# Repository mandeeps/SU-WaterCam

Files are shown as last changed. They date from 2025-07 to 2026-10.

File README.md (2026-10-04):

Prerequisite Knowledge:
Basic Linux, electronics, general computer troubleshooting

Helpful Resources:
Soldering: https://mightyohm.com/files/soldercomic/FullSolderComic_EN.pdf

# Build Guide

### Project requires a Raspberry Pi 
or compatible single board computer with GPIO, I2C, SPI etc.,

## Parts List

**WaterCam Unit**

- Raspberry Pi 4B

- [Copper or aluminum heatsink](https://www.amazon.com/GeeekPi-Heatsinks-Conductive-Electronic-Compatible/dp/B0C7Z27Q3R) for Raspberry Pi

- [Case 150x150x90 mm or larger](https://www.amazon.com/LMioEtool-Dustproof-Waterproof-Electrical-Transparent/dp/B07PK84N5D)

- [Optical Camera w/ controllable NIR filter (IR-CUT)](https://www.amazon.com/Dorhea-Raspberry-Camera-Automatic-Adjustable/dp/B07DNSSDGG/136-0027955-5919373) - should come with a ribbon cable to connect to the Pi 4B

- WittyPi 4 power management: [Witty Pi 4 HAT - RTC & Power Management for Raspberry Pi : ID 5704 : Adafruit Industries](https://www.adafruit.com/product/5704)

        Witty Pi 4 supports 3A power output for the Raspberry Pi 4

        [CR2032 Battery for WittyPi 4](https://www.adafruit.com/product/654)

- Flir Lepton 3.5 and Flir Breakout Board v2
  
  - [Flir Breakout board 2.0](https://www.mouser.com/ProductDetail/Teledyne-FLIR-Lepton/250-0577-00?qs=DRkmTr78QARne0IUCYtsyA%3D%3D)
  
  - [Flir Lepton 3.5](https://www.mouser.com/ProductDetail/Teledyne-FLIR-Lepton/500-0771-01?qs=DRkmTr78QAQNv%2FBEKfCn%252BQ%3D%3D)

- [Female/Female Jumper Wires](https://www.adafruit.com/product/266) - to connect Flir until we get a custom PCB made

- LWIR (8-14 micron range) transmission window material to protect Flir - [Edmund Optics](https://www.edmundoptics.com/f/infrared-ir-material-windows/12440/)

- [Stemma QT header cables to connect Adafruit sensors to Pi](https://www.adafruit.com/product/4397)

- plus [Stemma QT to Stemma QT cable](https://www.adafruit.com/product/4210) for chaining Adafruit sensors to other Adafruit sensors

- [Adafruit BNO085 IMU](https://www.adafruit.com/product/4754) or 055 IMU- for motion detection / orientation reporting

- [Adafruit AHT20](https://www.adafruit.com/product/4566) Temperature and Humidity Sensor - for monitoring device health

- [Voltaic V50 Battery](https://voltaicsystems.com/v50/) or V75 or other battery

        We are using Voltaic battery packs because they do not auto-shutdown during low power draw, which is important for this system as it will be in low-power mode most of the time and losing power then would prevent it from starting back up. They are intended to be directly charged from 6V solar panels using a barrel jack to usb-c (micro for older verions) adapter. If using a battery that is not always-on configure the WittyPi to draw more power when idle to avoid losing power.

- [Solar Panel](https://voltaicsystems.com/10-watt-panel-etfe/) - 6 volt panel if charging Voltaic battery pack directly  

- MicroSD card - preferably higher capacity than needed (at least 64GB), consider "high endurance" or "industrial" (for temperature tolerance) cards: https://www.dzombak.com/blog/2023/12/Choosing-the-right-SD-card-for-your-Pi.html
  
  Example: [SanDisk High Endurance microSD](https://shop.sandisk.com/products/memory-cards/microsd-cards/sandisk-high-endurance-uhs-i-microsd?sku=SDSQQNR-064G-GN6IA)
  
  Test the SD cards with F3 Fight Flash Fraud to verify they are legit: https://github.com/AltraMayor/f3

       TODO: Alternatively boot from USB SSD - this has pros/cons

* Dual USB-A to single USB-C cable to connect Voltaic power pack to WittyPi 4, preferably with right angle connectors for smaller cases. Only the USB-A ports on the Voltaic packs are always on, and each outputs 2.5A max, 3A together, so we need a Y power adapter.

* Cellular modem with USB Adapter board:
  
  [Quectel EC25 Cellular Modem](https://www.amazon.com/Quectel-LTE-EC25-AF-Mini-PCIe/dp/B082SL8KY1)
  
  [Cell Modem USB Carrier/Adapter with SIM Card Slot](https://www.amazon.com/gp/product/B07YY5967K)
  
  [Antennas for Modem and GPS](https://www.amazon.com/Antenna-698-2700MHZ-Universal-Directional-Wireless/dp/B08XBSYT8N) - need 3 antennas, 2 for cellular and 1 for GPS
  
  [Cables to connect Antennas to Cell Modem](https://www.amazon.com/Coaxial-Pigtail-Antenna-Bulkhead-Extender/dp/B098QH631G) - get appropriate cables to connect to uFL on the cellular board. SMA male antennas need SMA female cables, RP-SMA antennas likewise need the correct cables.
  
  [USB A Right Angle Up Adapter Cable for Modem](https://www.amazon.com/Antrader-Degree-Extension-Converter-Adapter/dp/B07F7Y21GW) - if the modem board does not otherwise fit in your case. The 150x150x90 case is too small to directly install the modem into the USB port on the Raspberry Pi.
  
  SIM Card for Cell Modem - 1nce for example has a data plan targeting IoT devices

* [Multitech mDot LoRa module](https://www.multitech.com/brands/multiconnect-mdot)
  
  - [Antenna for mDot](https://www.amazon.com/915MHz-LoRa-Antenna-Indoor-Cable/dp/B0CTXKBMH9) - RP-SMA connector needed on 915 MHz antenna
  
  - [Female-Female 2.54 to 2.0mm Jumper Wires](https://www.adafruit.com/product/1919) - 2mm pitch header cables for connecting mDot to Raspberry Pi until we get a custom PCB made

* Cable gland to let solar panel power cable into case
 
* MicroSD cards - preferably higher capacity than needed for wear-leveling, consider high endurance or industrial (for temperature tolerance) cards: https://www.dzombak.com/blog/2023/12/Choosing-the-right-SD-card-for-your-Pi.html 

Test the SD cards with F3: https://github.com/AltraMayor/f3
 
  **optional items we are evaluating**
- Anti-fog spray/hydrophobic coating for lens

- Breather valve / vent plug to allow moisture and heat to exit the bottom of the case

- Desiccant packs - for example https://sensorpros.com/products/druck-dri-can-desiccant?variant=3272716801 or https://www.amazon.com/Silica-Gel-Packets-Indicating-Electronics/dp/B0B2DNLZ4K - will need to be dried for reuse
  
  **Tools and accessories - do not order multiples**

- [Conformal coating](https://www.digikey.com/en/products/detail/mg-chemicals/419D-55ML/9657990) to protect electronics from water - make sure it is not applied to any connectors

- Silicone sealant for water-resistance - use to seal holes in case

- Ethernet cable - so you can connect to a network for updates and initial configuration. I shared the WiFi connection on my laptop with the Pi over Ethernet using Network Manager's connection sharing on Linux. Other operating systems have similar functionality.

- [Serial TTL USB adapter cable](https://www.adafruit.com/product/954) - useful for logging into the Pi before networking has been configured, and for debugging/troubleshooting.

- Drill for creating openings in case for cable gland, antenna sockets (if antennas don't fit in the case or need to be external), and camera aperatures

- microSD reader if you do not have one

### Setup Raspberry Pi 4 with Flir Camera, IMU, and Quectel Cellular modem+GPS

  Refer to this image for GPIO pin numbers



Flash the current SD card image file to an unused microSD card: https://github.com/WaterCam-Team/sd-images - NOTE: GPS set up has to be done for each cellular modem individually, this might be automated in the future.

You can use the [Raspberry Pi Imager's](https://www.raspberrypi.com/software/) custom OS option to write the image file to a SD card. Simply click "Choose OS", scroll all the way down, select "use custom" and pick the file you downloaded, then click "Choose Storage" and pick your microSD card. You don't need to customize settings or options, just write the image - so select "No" when asked if you want to customize Once it's been written to, you can insert it in a Pi 4B and let it boot. It will automatically expand the filesystem to the full size of the card, so it will take some time on the first boot. Do not interrupt this, just let it run.

You can connect to the system using a serial cable. Once it's connected to a network (via nmtui or other) synchronize the time (manually or with wittypi.sh) and change the hostname with `sudo hostnamectl set-hostname NEWNAME`. Verify that the 127.0.0.1 entry in /etc/hosts matches this new hostname and is not still using the base image name. Then you can add the device to Tailscale with an ACL tag: go to Tailscale Admin, click "Add device", select Linux server, add an ACL tag, and generate the install script.







<details>
<summary>If and only if installing software from scratch:</summary>

Use Raspberry Pi Imager to install current stable 64-bit Raspberry Pi OS Lite (Bookworm) to a microSD card with SSH enabled in the configuration options, along with the user account name and password, and configure a unique hostname for each system that makes sense (like the installation location)

https://www.raspberrypi.com/software/

After flashing, add `enable_uart=1` at the end of the /boot/config.txt file. Insert the SD card in the Pi, attach power and boot it up.

https://www.jeffgeerling.com/blog/2021/attaching-raspberry-pis-serial-console-uart-debugging

Use a serial cable to connect to the console and use sudo raspi-config to configure the device settings (locale, timezone, predictable network names, etc.,) and select Network Manager in place of dhcpcd in networking settings.

https://learn.adafruit.com/adafruits-raspberry-pi-lesson-5-using-a-console-cable/software-installation-windows

Pi Zero: within raspi-config, leave GPU memory at the default of 32 MB, PiCamera2 will not need more and the camera will not work with less.

Use sudo nmtui to configure the ethernet connection to a static IP, with your computer IP as the gateway and DNS server if you are sharing your Internet connection with the Pi. Otherwise configure for whatever network setup you have.

Now you can use ssh to login to the Pi after connecting it to your computer with an ethernet cable. Connection sharing can be setup using Network Manager on a Linux computer, or Windows Connection sharing, or the macOS equivalent.

Once you've logged in and have an internet connection on the Pi, run `sudo apt update` and `sudo apt upgrade`

Verify the Pi is on the latest firmware with `rpi-eeprom-update`.

Helpful tools: `sudo apt install git tmux htop rpicam-apps`
Serial console application: tio [https://github.com/tio/tio] or other (screen, minicom, etc.,)
Install your preferred editor (which should be neovim) and aptitude if you want a TUI for apt

Set /boot/config.txt options:

###### Disable LEDs to save a little power

dtparam=act_led_trigger=none
dtparam=act_led_activelow=off
dtparam=pwr_led_activelow=off

To disable ethernet LEDs on Pi 3 & 4 try:

dtparam=eth_led0=4
dtparam=eth_led1=4

or:

dtparam=eth_led0=14
dtparam=eth_led1=14

###### disable audio

dtparam=audio=off

###### disable wireless - Obviously leave this out if you are using Wifi on the Pi

dtoverlay=disable-wifi
dtoverlay=disable-bt
dtoverlay=pi3-disable-wifi
dtoverlay=pi3-disable-bt

###### I2C clock stretching for BNO055 IMU - only set this if there are issues with the BNO IMU

dtparam=i2c_arm_baudrate=10000

###### Pi Zero: add to /boot/cmdline.txt - Flir Lepton SPI settings

spidev.bufsiz=131072

###### SD Card settings

Disable swap and set noatime to prolong SD card life by decreasing writes: `sudo swapoff --all`, `sudo apt purge dphys-swapfile`.

Add `noatime,commit=60` settings to ext4 partitions in /etc/fstab - noatime prevents writing access times to files, commit collects and delays writes to every N seconds. Data loss will be limited to the last N seconds of writes if power is lost. Do NOT change the /boot partition settings, it is a vfat filesystem and these options will not work and will cause the Pi to not boot.

Set temp directories like /tmp to mount in RAM, ex. `tmpfs /tmp tmpfs nodev,nosuid,size=20M 0 0` in fstab: https://wiki.archlinux.org/title/Tmpfs

Other options include logging to a USB drive, or setting the SD to write-protected and using a USB drive for all write operations.

Use a larger SD card size than needed so you have free space for automatic wear-leveling (is this a thing on cheap SD cards?) 

Industrial or "high endurance" cards should offer better durability. SLC flash would be ideal but is expensive.

##### Optional Tweaks

You can disable services we won't be needing to speed up boot slightly (~3s)
sudo systemctl disable man-db.timer keyboard-setup triggerhappy

If you are not using wifi you could also disable wpa_supplicant

Outdated (Bullseye specific): If there are issues with taking high-resolution images use the vc4-kms-v3d driver with options: dtoverlay=vc4-kms-v3d,cma-320

Can also add nohdmi to the vc4-kms-v3d line to disable HDMI ports and save ~30mA

Keep the systemd journal in RAM to spare the microSD card: install `config/journald-volatile.conf` as described at the top of that file. Logs then last until the next shutdown or power cut.

### Power Management

Next, configure the WittyPi 4 for power management.
Download: wget http://www.uugear.com/repo/WittyPi4/install.sh
Install: sudo sh install.sh
Shutdown the Pi, install the WittyPi onto the Pi using the extended headers
Reboot, then run wittyPi.sh from the wittypi directory to configure the schedule.

Install doas with `sudo apt install doas -y`

Create /etc/doas.conf and add:

`permit nopass <username> cmd reboot
permit nopass <username> cmd shutdown`

We will run `doas shutdown` to power down the Pi in a script that is run as a non-root user. This lets us save power by turning off the Pi after it has completed its tasks and we can turn it back on at a regular interval with the WittyPi schedule.

Remove uwi since we will not be using it: sudo systemctl disable uwi, then rm the uwi directory.

If there are issues with power management check the firmware version the WittyPi is using and upgrade if needed using these instructions (might need a Pi with Bullseye installed, worked for me on Bookworm with kernel 6.1): https://www.uugear.com/portfolio/compile-flash-firmware-for-witty-pi-4/#rtc_offset_value

Remember to save and restore the clock offset as the instructions say.

### SU-WaterCam software setup from scratch

Clone the public git repo: https://github.com/mandeeps/SU-WaterCam.git
Compile lepton.c and capture.c for the device. Install build-essential if not already done: `sudo apt install build-essential`. Then cd to the SU-WaterCam/tools directory and run: 
`gcc lepton.c -o lepton && gcc capture.c -o capture`

Copy to the root of the SU-WaterCam directory: From tools directory, run `cp lepton ../.` and `cp capture ../.`

Install the system packages, create the venv and install the Python packages exactly as the header of
[`requirements.txt`](requirements.txt) describes. It is the single, complete recipe: the apt packages
(picamera2 and the camera stack must come from apt, not pip), a venv created with
`--system-site-packages` so it can see them, then `pip install -r requirements.txt` into that venv.

Set default Python to the venv by adding 'source /home/pi/SU-WaterCam/venv/bin/activate' to the end of your .bashrc file.

### Adafruit BNO055 IMU

`pip install adafruit-circuitpython-bno055` in the venv

### Adafruit BNO085 IMU

`pip install adafruit-circuitpython-bno08x` in the venv

### Calibrate the IMU prior to use:

Calibrate BNO055 - use the bno055_calibration.py script in the tools directory `bno055_calibration.py --mode calibrate`. It will walk you through the procedure.

Calibrate BNO085

TODO

</details>

## Hardware Setup

Current order of installation:

Modify NIR camera, install passive heatsink, install WittyPi 4 with CR2032 battery, connect NIR camera, connect cellular modem, connect Flir Lepton, connect mDot, insert microSD card, power on and test device before installing into case.

Drill holes for cameras and external power (and antennas if too large to fit within or signal blocked) into case, place components and battery into case, install cameras, connect antennas. Power on and test device.

Apply silicone sealant to all openings into case, and install LWIR transmission window for Lepton. Check water-resistance before field installation. Connect to solar panel power.

### Optical Camera

Remove the photo resistor (light sensor) from the Dorhea IR-CUT camera. You could remove it by snipping the two leads that connect it to the board, or apply heat with a soldering iron to the two leads and use a solder sucker or solder wick to detach them. 

Solder a wire so the IR filter can be manually controlled by the Pi. The wire is soldered to the third point from the bottom of the camera on the backside and connected to pin #40 on the Pi for use with the take_nir_photos.py script.

Before removing the photoresistor:



Solder a header cable like so:



It should look like this when done, the light sensor is gone and the wire will let us manually control the filter:



Insert the cable into the camera with the metal pins facing the board:



On the Rapsberry Pi find the CAMERA slot. The other end of the ribbon cable should be installed with the metal pins facing away from the black plastic retainer towards the pins in the slot:



### WittyPi 4 Setup

Solder pins to the unpopulated 7-pin header for use with the mDot. 

Software is already configured on the SD filesystem image. If installing from scratch follow installation instructions for the WittyPi software before installing the WittyPi hardware. Install the heatsink, standoffs, and connect the camera ribbon cable before placing the WittyPi on the GPIO pins. Screw down the hardware so it stays attached. Create a startup script or SystemD service to run the WittyPi network time synchronization when networking is available to get an accurate system time - WittyPi stock software disables Chrony, systemd-timesyncd, etc.,







Do not forget the standoffs or the heatsink.





### Quectel EC25 Modem and GPS

Install the miniPCIE card into the USB adapter. The mini PCIE card is the component on top and the USB adapter is the component on the bottom of this image:



The card can only fit into the adapter one way:



The MAIN and DIV UFL ports should connect to cellular antennas using UFL to SMA cables, and the GNSS slot is for a GPS antenna. Read this before connecting anything to UFL connectors: [Three Quick Tips About Using U.FL - SparkFun Learn](https://learn.sparkfun.com/tutorials/three-quick-tips-about-using-ufl/all)

The UFL connectors on the cables can be easy to damage, consider using a tool like this for installing and removing the cables: [U.FL Push/Pull Tool](https://www.sparkfun.com/u-fl-push-pull-tool.html)



Use a right-angle USB adapter cable to make connecting to the Raspberry Pi easier:



Also consider taping or otherwise securing the connections once everything is installed in the waterproof case to reduce the chance of disconnections during field installation.

Some of our cellular antennas use SMA connectors. Going forward we will stick with RP-SMA because that is what the mDot uses.

 https://store.rokland.com/blogs/news/connectors-101-rp-sma-vs-sma



SMA connectors

<details>

<summary>Cellular Modem Manual Software Setup</summary>

`sudo apt install gpsd gpsd-clients`

Remove and purge udhcpcd and openresolv: `sudo apt purge udhcpcd openresolv`
Reconfigure current network devices with network manager to retain local networking during setup - `sudo nmtui` is easiest way
Make sure /etc/network/interfaces has no references to devices you want NM to manage

Override automatic device renaming: Create /etc/systemd/network/10-wwan.link with the contents 

[Match]
Driver=qmi_wwan
Path=platform-fd500000.pcie-pci-0000:01:00.0-usb-0:1.3:1.4

[Link]
Name=wwan0

Then run 'sudo udevadm control --reload' 

'sudo udevadm trigger --action=add /sys/class/net/wwp1s0u1u3i4' or whatever the device name is

Then configure the cellular modem and verify everything works as expected after restarts
`sudo mmcli -m 0 --simple-connect='apn=iot.1nce.net'` Replace apn as appropriate

Setup connection with NetworkManager: `sudo nmcli c add type gsm ifname cdc-wdm0 con-name Quectel apn iot.1nce.net`

Reduce the priority of the cellular modem so Ethernet or WiFi is preferred while you are still installing updates: https://superuser.com/a/1603124

`sudo nmcli con mod Quectel ipv4.route-metric 100` and do the same for ipv6

**GPS/GNSS setup — needs to be done once per modem**

The Quectel EC25 GNSS receiver is independent of the cellular data stack. It works even if the SIM has exhausted its data limit. The udev rule `config/77-mm-quectel-ignore-gps.rules` prevents ModemManager from claiming the ttyUSB serial ports, so ttyUSB1 (NMEA output) and ttyUSB2 (AT commands) are always available.

Configure these one-time NVRAM settings on the modem. Stop ModemManager first so the AT port is free:

`sudo systemctl stop ModemManager`

Connect to the AT port with tio:
`tio /dev/ttyUSB2`

(ttyUSB2 is the AT port. ttyUSB1 is the GPS NMEA output port.)

Issue the following AT commands. You should see `OK` after each. You may not see what you are typing — just type and press Enter.

Enable NMEA output:
`AT+QGPSCFG="nmeasrc",1`

Enable GNSS autostart on modem power-on:
`AT+QGPSCFG="autogps",1`

Turn GNSS on now:
`AT+QGPS=1`

Enable assisted GPS (XTRA) — requires network access to download assistance data, skip if SIM is exhausted:
`AT+QGPSXTRA=1`

Exit tio with `ctrl-t q`. These settings are saved to NVRAM and only need to be set once per modem.

Restart ModemManager: `sudo systemctl start ModemManager`

**Install the GNSS systemd service**

`quectel-gnss.service` sends `AT+QGPS=1` at boot, before gpsd starts. This is needed because the autogps NVRAM setting does not always persist across power cycles reliably.

```
sudo cp config/quectel-gnss-enable /usr/local/bin/
sudo chmod +x /usr/local/bin/quectel-gnss-enable
sudo cp config/quectel-gnss.service /etc/systemd/system/
sudo systemctl daemon-reload
sudo systemctl disable gps.service   # disable old service if present
sudo systemctl enable --now quectel-gnss.service
```

**Configure gpsd**

Edit `/etc/default/gpsd`:
```
DEVICES="/dev/ttyUSB1"
GPSD_OPTIONS="-n"
START_DAEMON="true"
```

Then restart gpsd: `sudo systemctl restart gpsd`

Verify NMEA is streaming: `timeout 10 cat /dev/ttyUSB1` — you should see `$GPGGA`, `$GPRMC`, etc.

**Python GPS usage** (using py-gpsd2 installed via requirements.txt, or run tools/get_gps.py directly):
```python
import gpsd2
gpsd2.connect()
packet = gpsd2.get_current()
print(packet.position())
```

**XTRA assisted GPS data**

XTRA data speeds up cold-start time-to-first-fix but requires network access to download. If the SIM data is exhausted, XTRA will not update but the receiver still works — expect a longer cold-start fix time (a few minutes outdoors with clear sky view instead of seconds). To manually refresh XTRA when network is available: download `xtra2.bin` and inject it with `sudo mmcli -m 0 --location-inject-assistance-data=xtra2.bin`

sources:
https://sigquit.wordpress.com/2012/03/29/enabling-gps-location-in-modemmanager/
Stackoverflow mirror: https://code.whatever.social/questions/6146131/python-gps-module-reading-latest-gps-data

</details>

### Flir Lepton Breakout board wiring

Raspberry Pi GPIO Header

Image source: [Lepton/docs/RaspberryPiGuide.md at main · FLIR/Lepton · GitHub](https://github.com/FLIR/Lepton/blob/main/docs/RaspberryPiGuide.md)

Eventually we will have a PCB to connect the Lepton breakout board and Raspberry Pi.

Manual Lepton Breakout Board Wiring
Orient the back of the breakout board towards yourself. The front is the side with the socket for the Lepton camera.
Let's call the pins that are closest to you pins 1 through 10, starting from the left and going to the right. Right is the side with the mini ZIF connector on top (the white plastic bit above the QR code sticker)
Let's call the pins on the bottom (away from you) pins A through J.

Flir Lepton Breakout 2.0 Pins

Image by Kaitlyn Gilmore (https://github.com/kmgmore)

We can use the top pin of the two pins without jumpers on the back of the board (side towards you right now) for ground. In other words, the pin with nothing covering it that is closest to the white ZIF socket towards the top is the ground pin, so connect it to the ground pin on the Pi.

Wiring diagram: 



Note: I2C is not required for getting data from the Lepton, but is useful for changing its configuration. Because we need I2C for other peripherals, use splitter cables for the two I2C pins (SDA and SCL) on the Pi. So get or make two cables that each have a female header on one end and a male and female header on the other end. One female end connects to a pin on the Raspberry Pi GPIO header, and the other two ends are for the Flir breakout board and a peripheral like the Adafruit IMU. Another pair of split cables is useful for 3.3V (or 5V) and ground.

Split Y cables for I2C or power: 

If using I2C: The SDA pin on the Pi (pin #3) will connect to pin C on the breakout board (side away from you) - use a splitter

I2C: The SCL pin on the Pi (pin #5) will connect to pin 4 on the breakout board (side towards you) - use a splitter - image has been corrected to match this

MOSI on the Pi (pin #19) connects to pin E on the breakout

MISO on the Pi (pin #21) connects to pin 6 on the breakout board

CLK pin on the Pi (pin #23) will connect to pin D on the breakout

CS pin (pin #24, right across from CLK, aka CE0, GPIO 8) connects to pin 5 on the breakout board

We are not using this but I am leaving the note here for reference: the VSYNC pin is Pin #11, GPIO 17 on the Pi connected to pin H on the breakout board - This GPIO is also used by the WittyPi 4 and that might cause an issue. Our software does not currently use vsync anyway, so this can be ignored.

Reset pin on the breakout is pin I following the convention declared above. Connect it to an arbritrary GPIO pin on Pi that is set high by default (options are 0-8)

I am using GPIO 6 (pin 31 on the Pi) in the lepton_reset.py script. We need a pin that is high by default because the breakout board reset triggers on low.

Insert the Flir camera into the breakout board.
Check everything is correct by running the capture and lepton binaries in SU-WaterCam. Rename or copy the appropriate 32 or 64-bit binaries to "lepton" and "capture" and then run: ./capture

Examine the created files to verify things are working.

Binaries are from https://github.com/lukevanhorn/Lepton3

Thanks Luke Van Horn! Also, thanks to Max Lipitz for the tip about the output containing the temperature values in degrees Kelvin.

#### Leptonic for live thermal image stream

We're setting up an unused Pi 3 for collecting thermal images for coregistration - using leptonic from github

https://github.com/themainframe/leptonic

Compile after installing dependencies: libzmq3-dev

Port forward, first ssh into pi and run leptonic on /dev/spidev0.0, then open another terminal and port forward with:
➜ ssh -L 5555:10.42.0.3:5555 pi@10.42.0.3

Run the leptonic web server on your own machine, it's too much for the Pi 3 to do both: 
npm start in frontend directory then
127.0.0.1:3000 in your browser

</details>

### Multitech mDot LoRa module



The default mDot firmware is set up for UART. The WittyPi can tell if the Raspberry Pi is off by reading the TX pin, which should be set low when the Pi shuts down. Keeping the mDot powered on through the WittyPi keeps the TX pin on the Pi set high and prevents the WittyPi from cutting off power to the Raspberry Pi. So we turn on alternative UART pins on the Pi 4B and use those to connect to the mDot instead on our default OS images.

To do this manually: add dtoverlay=uart5 to /boot/config.txt on a Pi 4 so we can use pin 32 for TX and pin 33 for RX. On the Pi 4, make sure "enable_uart=1" is in the /boot/config.txt file, and add "dtoverlay=uart5". Save and reboot. Connect the TX pin on the mDot to pin #33 on the Pi and connect the RX pin on the mDot to pin #32 on the Pi.

**mDot wiring**

The power pin (VOD, pin # 1) on the mDot should be connected to 3.3V on the WittyPi. Connect ground (pin 10 on the mDot) to the ground pin on the WittyPi. Connect the mDot UART TX (transmit, pin #2) to the Pi RX (receive) pin (pin #33 if using uart5), and the mDot RX pin (#3) to the Pi TX pin (pin #32 using uart5).

For the remote start over Lora function, the WittyPi ground should be connected to both the mDot ground and a mosfet's source. The mosfet drain should be connected to the WittyPi switch pin. The mosfet gate should be connected to both the mDot output pin PB_1 and the WittyPi ground with a resistor. The mDot input pin PA_6 should be connected to a GPIO on the Raspberry Pi that is set HIGH when the Raspberry Pi is turned on, we are using GPIO 5 (pin 29) on the Raspberry Pi. 

On the Pi run tio /dev/ttyAMA5 and issue AT commands to control the mDot, see the mDot AT reference document in the instructions directory. For example, "ATI" will tell you the installed firmware version.

if using minicom or screen:

sudo minicom -s -D /dev/serial0 to connect to the mDot if it is on the default TX/RX pins, minicom -s -D /dev/ttyAMA5 if on uart5,

Use the settings specified in the mDot manual:

Baud rate 115200

Data bits 8

Parity N

Stop bits 1

Hardware/software flow control off

Add the device ID to Chirpstack as the Device EUI. You can reuse the device Network ID as the Join EUI in Chirpstack. The device Network Key is the Application Key in Chirpstack. If the mDot fails to join but does activate try to set the address, session key, and application key manually on the mDot. Reset the nonces under OTAA Keys in Chirpstack and on the mDot.

### Solar Power

Voltaic battery packs should be connected to solar panels using the connector on the side of the battery pack. Older models used micro-USB and newer ones use USB-C. The USB-C port on the top can be used for reading the battery level. The full-size USB-A ports are the ones that provide always-on power. Voltaic packs support pass-through charging from solar panels.

According to Voltaic: "The SBU pins still correlate to ½ of the cell voltage, so while the battery cell voltage ranges from approximately 3.2V (empty) to 4.2V (full charge), the corresponding SBU pin voltage ranges from 1.6V to 2.1V. We recommend that customers currently reading the cell voltage from the D+ pin make the necessary hardware changes to read from the A8/B8 SBU pins."

### Tailscale for remote login over cellular data

https://tailscale.com/download

Consider using Tailscale SSH: https://tailscale.com/kb/1193/tailscale-ssh

`tailscale up --ssh`

Make sure the device is [tagged](https://tailscale.com/kb/1068/tags) and not using a personal Tailscale account. See tailscale-acl.txt in config directory for an example of Access Control List rules to permit SSH into tagged devices. Forbid tagged devices from accessing other tagged devices for security. 

Do not clone SD cards from Pis with Tailscale already configured so you can install that SD card on a new Pi. Each device should be connected to Tailscale individually and not share keys.

Consider installing and using mosh for high-latency cellular connections
sudo apt install mosh

Use an appropriate client for your own device.

### Filebrowser remote file access

Helpful when using a system interactively for data collection: https://github.com/filebrowser/Filebrowser

Install, then run:

```
filebrowser config init 
filebrowser users add USER PASSWORD
filebrowser config set --address 0.0.0.0
```

Then you can create a SystemD service like the example in the config directory. Move it to /etc/systemd/system, run `sudo systemctl daemon-reload` and `sudo systemctl enable --now filebrowser` to run.

### Remote Video Streaming

with libcamera-apps-lite installed run:

`libcamera-vid -t 0 --inline --listen -o tcp://0.0.0.0:8888`

On your machine connected to the Pi (over Tailscale or directly) use VLC to stream the video using 'open network stream' and enter tcp/h264://PI_ADDRESS_OR_HOSTNAME:8888 with the appropriate IP address and port number. 

### Pytorch

`pip install torch torchvision` (in the venv)

old model based on FloodNet data set and DeepLab
FloodNet: https://ieeexplore.ieee.org/document/9460988

### Boot Speed and Power Optimization
If the cellular modem is not needed, networking and USB can be disabled to reduce boot time and power consumption. NetworkManager and ModemManager can be disabled.

uhubctl for turning off USB: https://github.com/mvp/uhubctl

Overclocking by small amounts is being investigated. Reducing the time spent operating would allow the system to return to an off state faster, possibly reducing overall power consumption compared to running at a lower clock rate.

## Clone SD Card

If you need to clone/copy a Pi microSD card:

on a Linux/*nix system use dd to copy the entire device. Make sure you have enough free space first, as the filesystem image will be the same size as the SD card you are copying. Use lsblk to determine the location of the SD card! Clone the entire disk, not a partition.

`dd bs=4M if=/dev/mmcblk0 of=sd_clone conv=fsync status=progress`

You might need to run dd with sudo if your user account does not have access to the SD device. Change the owner of the new file if so.

If you want to share it online, use PiShrink to save space. PiShrink reduces the image to the actual used space, not the size of the entire SD card: https://github.com/Drewsif/PiShrink

This command will also apply xz compression to the shrunk image.

`sudo pishrink.sh -aZ image_file`

For creating new SD cards with the file you copied you can use Raspberry Pi Imager (or Etcher or another such tool). If you are copying an image that was compressed with PiShrink remember that the first boot will take time as the filesystem is expanded. If you use dd to write the image to an SD card you need to uncompress it first. The command for dd is as above but with the input and output reversed to write to a blank SD card. ALWAYS check you are writing to the correct device when you use dd. For more information on this: https://www.pragmaticlinux.com/2020/12/how-to-clone-your-raspberry-pi-sd-card-in-linux/ 

## Manual Data Collection

If you need to take a unit out in the field to collect data you can add a couple of wires to a button to trigger the cameras and use the button-service-gpiozero.py script with GPIO Zero installed: https://github.com/gpiozero/gpiozero 

We are using a simple pushbutton on a perfboard with two header cables connected to pin #29 and ground on the Pi. Autostart the script with systemd using the button.service file in the config directory. Copy the button.service file to /etc/systemd/system, then run sudo systemctl daemon-reload, sudo systemctl enable button.service, and sudo systemctl start button.service

***References and Helpful Resources***

**Raspberry Pi**

https://pinout.xyz/

**Flir Lepton**

Lepton 3.5 with radiometery: 56° HFOV, 71° diagonal (f/1.1 silicon doublet)

[Home · groupgets/LeptonModule Wiki · GitHub](https://github.com/groupgets/LeptonModule/wiki)

[Flir Lepton Thermal Camera Breakout | Hackaday.io](https://hackaday.io/project/3000-flir-lepton-thermal-camera-breakout)

[GitHub - maxritter/diy-thermocam: A do-it-yourself thermal imager, compatible with the FLIR Lepton 2.5, 3.1R and 3.5 sensor with Arduino firmware](https://github.com/maxritter/diy-thermocam)

[GitHub - themainframe/leptonic: A web GUI and several utilities for working with FLIR® Lepton® 3 LWIR camera modules.](https://github.com/themainframe/leptonic)

[Flir Lepton hacking](https://www.electricstuff.co.uk/lepton.html)

[GitHub - groupgets/LeptonModule: Code for getting started with the FLIR Lepton breakout board](https://github.com/groupgets/LeptonModule)

[FLIR Lepton Hookup Guide - SparkFun Learn](https://learn.sparkfun.com/tutorials/flir-lepton-hookup-guide)

[Lepton/docs/RaspberryPiGuide.md at main · FLIR/Lepton · GitHub](https://github.com/FLIR/Lepton/blob/main/docs/RaspberryPiGuide.md)

https://groups.google.com/g/flir-lepton?pli=1

[GitHub - alexanderdyson/openmv_flir_object_detection](https://github.com/alexanderdyson/openmv_flir_object_detection)

[GitHub - danjulio/lepton: Code and libraries to use a FLIR Lepton Thermal Imaging Camera Module](https://github.com/danjulio/lepton/)

[lepton/raspberrypi at master · danjulio/lepton · GitHub](https://github.com/danjulio/lepton/tree/master/raspberrypi)

https://anthony.lepors.fr/raspi-thermo-cam/installation-de-leptonmodule/

https://www.pureengineering.com/projects/lepton

[GitHub - lukevanhorn/Lepton3: Lepton 3 for the Raspberry Pi](https://github.com/lukevanhorn/Lepton3)

**UUGear WittyPi4**

Alternative implementation using more standard modern Linux subsystems: https://github.com/trackIT-Systems/wittypi4 - will investigate later
Python interface to WittyPi4: https://github.com/Eagleshot/WittyPi4Python

Note that the stock software disables network time sync software like Chrony, systemd-timesyncd, ntpd, etc.,

**Multitech mDot LoRa module**

https://os.mbed.com/cookbook/Interfacing-with-Python

https://os.mbed.com/cookbook/Interfacing-Using-RPC

With mbed being EoL'd by ARM, consider mbed community edition for future work: https://github.com/mbed-ce

GCC ARM toolchain can be used for mbed in place of ARM CC

**Voltaic Battery**

["The two USB-A ports function the  same. Connecting a USB-A cable activates a mechanical switch, which puts the battery into Always On mode. Removing the cable puts that battery into Auto Off mode. If you supply power into the battery via the top USB-C PD port, the Always On function of the USB-A ports is deactivated. We recommend using the side port for power input in any Always On application."](https://blog.voltaicsystems.com/updated-usb-c-pd-and-always-on-for-v25-v50-v75-batteries/)

**Quectel Cellular Modem**

**IR CUT Camera**

Our (OV5647 sensor) camera stats: 

CCD size: 1/4 inch

Aperture(F): 1.8

Focal Length: 3.6 mm (adjustable)

Field of View: 72 degrees

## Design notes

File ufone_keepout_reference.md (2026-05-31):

# UFONet WaterCam – Component Keep-Out Reference

**Rev 0.3 | UFO-Net / WaterCam Sensor Stack**

This document covers mechanical dimensions, keep-out zones, special placement constraints, and conformal coating instructions for each component in the WaterCam sensor assembly. Dimensions are in millimeters unless noted. All dimensions should be verified against the linked official sources before committing to a PCB layout.

> **Conformal Coating Note:** Two coating materials are in use across WaterCam builds. Third-party manufactured units use **acrylic** (IPC-CC-830 Type AR, 25–75 µm). Student-assembled units may use **MG brand modified silicone** (IPC-CC-830 Type SR). Keep-out zones are identical for both materials; process procedure and safety considerations differ — see [Section 0](#0-conformal-coating-material-selection) before beginning.

---

## 0. Conformal Coating Material Selection

### Is acrylic sufficient for WaterCam?

**Yes.** WaterCam units are housed in IP65-rated enclosures. The conformal coating is a secondary protection layer against condensation forming inside the enclosure — not a substitute for the enclosure seal. Acrylic (IPC-CC-830 Type AR) at 25–75 µm is standard practice for this type of deployment and is the correct specification for third-party manufacturing.

Acrylic advantages for this application:
- Simple, consistent application by spray or brush
- Tack-free in ~30 min, full cure in 24 h
- Reworkable with acetone or MEK — failed components can be replaced in the field
- No outgassing after cure — safe to close enclosure immediately

### MG Modified Silicone — when and why

MG brand modified silicone (e.g., MG 422B) is a silicone-acrylic hybrid (IPC-CC-830 Type SR). It offers better flexibility across wider temperature swings (−65°C to +200°C vs. acrylic's typical −65°C to +125°C) and greater moisture resistance if the IP65 seal is compromised.

Students may use MG modified silicone for units they assemble. The keep-out masking zones are identical to acrylic. However, silicone introduces three risks specific to this hardware that require additional procedure steps described below.

### Material Comparison

| Property | Acrylic (third-party) | MG Modified Silicone (student) |
|---|---|---|
| IPC-CC-830 type | AR | SR |
| Thickness target | 25–75 µm | 50–130 µm (2 thin coats) |
| Tack-free time | ~30 min | ~30 min |
| Functional cure | 24 h | 24 h |
| Off-gas period before enclosure close | None required | **72 h minimum** (see AHT20 risk below) |
| Rework solvent | Acetone or MEK | MG 8340 thinner or mechanical removal only |
| Viscosity | Low — good spray atomisation | Higher — apply thin coats, avoid flood |
| Masking tape bond risk | Low | Moderate — use low-tack tape (3M ScotchBlue 2090) |

### Silicone-Specific Risk 1 — AHT20 Humidity Sensor Contamination (CRITICAL)

Silicone coatings off-gas volatile cyclic siloxanes (D4, D5) during and after cure. These vapors deposit on the AHT20's capacitive polymer sensing film, filling the hygroscopic pores and reducing effective surface area. The result is a persistent, systematic **low-humidity offset** that may not recover fully at ambient conditions. This is a documented failure mode for polymer-film humidity sensors exposed to silicone coating outgassing.

**Mitigation for silicone builds:**
- After coating and functional cure (24 h), leave the board in open air for a minimum of **72 h** before installing into the enclosure.
- Do not close the enclosure until off-gassing is complete — siloxanes trapped inside will re-deposit on the sensor.
- After 72 h open-air off-gas, perform a reference humidity check by comparing the AHT20 reading against a calibrated reference (a second uncoated sensor or a reference hygrometer). If offset exceeds ±4% RH, extend off-gas period or replace the AHT20.
- Alternatively: install the AHT20 **after** coating and off-gassing are complete. The AHT20's DFN-6 package is a simple hand-solder part (6 pads, 3 mm × 3 mm); installing it last avoids exposure entirely.

### Silicone-Specific Risk 2 — Optical Surface Contamination

Siloxane vapor deposits a thin, partially absorptive film on optical surfaces:

- **Dorhea camera lens:** Silicone film causes visible haze in RGB images. Even minor contamination reduces contrast at the water surface edge used for flood-line detection.
- **Lepton lens (internal) and PE IR window (enclosure):** Silicone film deposits on the Lepton's internal lens element reduce thermal sensitivity (higher effective NETD). The enclosure PE window (EO #2593, 0.38 mm polyethylene) is non-polar — siloxane physisorption on PE is relatively low compared to polar or crystalline surfaces, so the window itself is a secondary concern. The primary reason not to close the enclosure during off-gassing is the AHT20. That said, if siloxane does deposit on the PE window, clean with IPA; unlike crystalline windows, PE is not damaged by IPA.

**Mitigation for silicone builds:**
- Remove Lepton module before coating (already required for all builds).
- Remove Dorhea camera from its mount and store in a sealed anti-static bag before coating.
- Do **not** reinstall either optical component until the full 72 h off-gas period is complete and the board is installed in the enclosure with the enclosure briefly vented.

### Silicone-Specific Risk 3 — Connector Contact Contamination

Silicone that contacts metal spring fingers (Molex socket, U.FL connectors, GPIO pins) cannot be removed with acetone or IPA. It requires MG 8340 thinner and mechanical scrubbing, or micro-abrasive blasting — neither practical for field repair.

**Mitigation for silicone builds:**
- For the Molex 32-pin Lepton socket: tape is not sufficient. Insert a physical foam plug cut to the socket cavity dimensions, then tape over it. Remove foam plug after curing.
- For U.FL connectors: use a mated dummy connector or wrap with self-fusing silicone tape (yes — silicone tape as mask, because it does not bond to cured silicone coating the way acrylic-based tape adhesive does).
- For GPIO headers: wrap entire header with self-fusing silicone tape rather than electrical tape.
- Inspect all contacts under magnification before reinstalling any connector. Any silicone residue on spring fingers requires 8340 thinner and a cotton swab before assembly.

### Silicone Application Notes for Students

1. **Clean the board first.** Remove all flux residue with IPA. Allow IPA to evaporate completely (minimum 15 min at room temperature) before applying silicone — residual IPA under curing silicone causes adhesion failure and blistering.
2. **Apply in two thin coats, not one thick coat.** MG modified silicone is more viscous than acrylic. A single thick coat runs and drips around connector edges. Let first coat become tack-free (~30 min) before applying second coat.
3. **Do not spray at close range.** If using aerosol, hold the can at 30 cm minimum. Close-range silicone spray globs rather than atomising.
4. **Feather brush strokes away from masked areas.** Load the brush lightly and stroke outward from the masked edges — do not stroke toward them. Silicone wicks more aggressively than acrylic.
5. **Use low-tack masking tape.** Standard painter's tape or electrical tape may bond to the silicone surface on removal, leaving adhesive residue on PCB pads. 3M ScotchBlue 2090 is a suitable choice. Peel masking within 1 hour of tack-free (do not wait for full cure to remove masking — it becomes harder to peel cleanly).
6. **Document what you coated.** Photograph the board before and after coating. Record which board serial number received silicone. Rework requires knowing which material was used.

### Revised Process Order — Silicone Builds

1. Clean board with IPA. Wait 15 min for full evaporation.
2. **Remove** FLIR Lepton module. Store in sealed anti-static bag.
3. **Remove** Dorhea camera. Store in sealed bag.
4. Apply physical foam plug to Molex socket. Apply self-fusing silicone tape to GPIO headers and U.FL connectors. Apply low-tack tape (3M 2090) to all other MASK zones.
5. Apply first coat of MG modified silicone. Allow 30 min tack-free.
6. Apply second coat. Allow 24 h functional cure at room temperature.
7. Peel all masking (do not wait beyond 1 h after tack-free for tape sections).
8. Inspect contacts under magnification. Clean any silicone residue from spring fingers with MG 8340.
9. **Leave board in open air for 72 h** to off-gas siloxanes. Do not place in enclosure during this period.
10. After 72 h: perform AHT20 reference humidity check (compare against calibrated reference). If offset >±4% RH, extend off-gas period or replace AHT20.
11. Inspect optical paths: confirm no haze on Dorhea lens, confirm no film visible on Lepton lens. Do not install enclosure polymer IR window until off-gas is complete.
12. Reinstall Dorhea camera. Reinstall FLIR Lepton module into Breakout Board socket.
13. Install board into enclosure.

---

## 1. Raspberry Pi 4 Model B

| Attribute | Value |
|---|---|
| PCB | 85.0 × 56.0 mm |
| Thickness | 1.4 mm nominal |
| Mounting holes | 4× M2.5, located at corners (see drawing) |
| GPIO header | 40-pin 2×20, 2.54 mm pitch |
| Tallest component (USB-A) | ~15.0 mm above top of PCB |
| RJ45 height | ~13.5 mm |
| USB-C power | Short edge, extends ~3.2 mm beyond board edge |
| MicroSD protrusion | ~2.8 mm beyond short edge |
| Camera FPC (CSI-2) | Top edge, 15-pin 1.0 mm pitch |
| Display FPC (DSI) | Top edge, 15-pin 1.0 mm pitch |

### Keep-Out Zones

**Connector access clearance.** The USB-C power port, dual USB 3.0/2.0 ports, and RJ45 all protrude from the long edges of the board. The USB-C extends 3.2 mm past the PCB edge; provide a minimum 5 mm clearance on the USB-C side to allow cable insertion.

**GPIO header region.** The 40-pin header runs along the long edge. If stacking a HAT, standard M2.5 brass standoffs require 11 mm minimum clearance between board surfaces. Do not route signals under the header pins.

**Under-board clearance.** The underside of the Pi 4B has SMT components. Minimum 1.0 mm clearance below the board to any substrate surface. Do not place any components directly under the Pi footprint on the same carrier PCB if the Pi is soldered down.

**Camera/Display FPC connectors.** Located along the top long edge. Each requires ~5 mm clearance above the PCB for the cable lock arm to open. Do not obstruct the cable path toward the lens or display.

**RF.** The Pi 4B has an onboard Wi-Fi/BT antenna in the top-right corner (opposite end from USB-C). Do not place metallic structures within ~5 mm of the antenna module area on the same vertical plane.

### Conformal Coating — Raspberry Pi 4B

```
Pi 4B Top View (85 mm × 56 mm)
┌──────────────────────────────────────────────────┐
│ [MASK] USB-A × 2    [MASK] RJ45    Antenna ████  │
│ ████████████        ███████████              ▲   │
│                                              │   │
│                    PCB body                  │   │
│                    COAT OK                   │   │
│                                          RF keep-│
│                                          out 5mm │
│ ████ USB-C [MASK]                            │   │
│ ████ MicroSD [MASK]                          │   │
│                                              │   │
│ ○○○○○○○○○○○○○○○○○○○○  GPIO [MASK]           │   │
│ ○○○○○○○○○○○○○○○○○○○○                            │
│ [CSI-2 FPC]  [DSI FPC]  ← both MASK             │
└──────────────────────────────────────────────────┘
```

| Zone | Treatment |
|---|---|
| PCB body (SoC, RAM, passives) | COAT OK |
| USB-A, USB-C, RJ45, HDMI connectors | MASK — connector contacts must remain uncoated |
| MicroSD slot | MASK — card insertion must remain possible |
| GPIO 40-pin header | MASK — WittyPi HAT connection must remain clean |
| CSI-2 FPC connector (camera) | MASK — Dorhea FPC must remain removable |
| DSI FPC connector | MASK — if display is installed; mask regardless |
| Wi-Fi/BT antenna module area | Do not coat; keep metal structures 5 mm clear |

**Official Resources**
- Mechanical drawing (PDF): https://datasheets.raspberrypi.com/rpi4/raspberry-pi-4-mechanical-drawing.pdf
- Product Information Portal: https://pip.raspberrypi.com/categories/559-mechanical
- Full datasheet: https://datasheets.raspberrypi.com/rpi4/raspberry-pi-4-datasheet.pdf

---

## 2. WittyPi 4 (UUGear Power Management HAT)

| Attribute | Value |
|---|---|
| Form factor | Standard Raspberry Pi HAT |
| PCB | 65.0 × 56.0 mm |
| GPIO connector | 2×20 SMT header, base height 3.5 mm (updated Aug 2025; prior version was 2.0 mm) |
| Input voltage | Up to 30V DC via screw terminal |
| Operating temperature | −30°C to +80°C |

### Keep-Out Zones

**Stack height.** When mounted on the Pi 4B via the 40-pin GPIO header, the WittyPi 4 board surface sits approximately 3.5 mm above the Pi GPIO pin tops. Combined with the Pi's 15 mm tallest component, ensure the enclosure interior has adequate clearance for the stack.

**I2C address space.** The WittyPi 4 acts as an I2C proxy for its onboard RTC and temperature sensor. The I2C address is configurable to avoid conflicts with the BNO085 and AHT20 (0x38). Confirm address assignments before finalizing firmware.

**Power wiring keep-out.** The DC input screw terminal is on one edge of the board. Ensure adequate clearance for the power cable routing within the enclosure, especially near the IP65 cable gland entry point.

### Conformal Coating — WittyPi 4

```
WittyPi 4 Top View (65 mm × 56 mm)
┌────────────────────────────────────┐
│                                    │
│  DC/DC converter   RTC chip        │
│  (tallest ~10 mm)  DS3231SN        │
│  COAT OK           COAT OK         │
│                                    │
│  PCB body / passives               │
│  COAT OK                           │
│                                    │
│  ████ DC screw terminal [MASK] ████│ ← power wires pass through
│                                    │
│ ○○○○○○○○○○○○○○○○○○○○ GPIO header  │
│ ○○○○○○○○○○○○○○○○○○○○ [MASK]       │ ← mates with Pi GPIO
└────────────────────────────────────┘
```

| Zone | Treatment |
|---|---|
| PCB body (DC/DC converter, RTC, passives) | COAT OK |
| 40-pin GPIO header (underside, contacts Pi) | MASK — contacts must remain clean for electrical connection |
| DC input screw terminal | MASK — power wire termination must remain serviceable |

**Official Resources**
- Product page: https://www.uugear.com/product/witty-pi-4/
- User manual: https://www.uugear.com/doc/WittyPi4_UserManual.pdf
- STEP model (Mini variant): https://www.uugear.com/repo/WittyPi4/WittyPi4Mini.step

> Note: UUGear does not appear to publish a standalone mechanical drawing PDF for the WittyPi 4. Dimensions can be extracted from the STEP file or measured from the standard HAT template.

---

## 3. FLIR Lepton 3.5

| Attribute | Value |
|---|---|
| Module (without socket) | 11.5 × 12.7 × 6.9 mm |
| Module (with Molex socket) | 11.8 × 12.7 × 7.2 mm |
| Resolution | 160×120 pixels |
| Spectral band | LWIR 8–14 µm |
| Field of view | 57° horizontal / 71° diagonal (with shutter) |
| Interface | 32-pin Molex socket (105028-1001 or 105028-2031) |
| Max mounting force | 1 kgF (do not exceed) |
| Operating power | ~140 mW typical; ~800 mW during shutter event |
| Operating temperature | −10°C to +80°C |

### Keep-Out Zones

**Optical field of view.** The 57° horizontal × 71° diagonal FoV cone must be completely clear of any enclosure wall, baffle, or coating. The cone extends from the lens face outward; nothing may encroach on this volume.

**Mechanical shutter pins.** The Lepton 3.5 has a motorized internal shutter. The shutter mechanism has protruding actuator pins on the sides of the housing. Any foam isolator, retention clip, or bracket must be cut to avoid contacting these pins. Maximum uniform load on shutter face: 1 kgF.

**Thermal keep-out.** Do not place heat-generating components within the Lepton's FoV. Minimize thermal gradient across the camera body — per the Teledyne FLIR Engineering Datasheet, the surrounding area must support dissipation of up to 160 mW. Thermally isolate the Lepton mounting from the main PCB ground plane where possible.

**Socket contact zone.** The Lepton module is NOT a sealed assembly (per FLIR Engineering Datasheet §6.2). Its 32 side contacts engage the Molex socket through wiping contact. Any liquid (coating, flux residue, condensation) that enters the socket-module interface will cause contact resistance failures. The Lepton module must never be coated.

**Polyethylene IR window.** The WaterCam enclosure uses an Edmund Optics 6″ × 6″ Translucent IR Material Window (EO #2593) cut to fit the **Lepton aperture only**. This window does not cover the Dorhea optical camera — the Dorhea lens faces the environment directly (see Section 5). Material is **polyethylene (PE)**, 0.38 mm thick, molded translucent/milky white sheet. Transmission spans 8–14 µm (LWIR, matching the Lepton 3.5 spectral response) and extends to ~40 µm. The FLIR Engineering Datasheet §6.2 cites germanium and zinc selenide as common crystalline options — those are not in use here.

Key handling notes for this window:
- **Thickness 0.38 mm — very flexible and scratch-prone.** Handle by edges only. Do not lay flat on abrasive surfaces.
- **Solvent compatibility.** PE is resistant to IPA, acetone, and the carrier solvents in both acrylic and silicone conformal coatings. Do not use aromatic solvents (toluene, xylene) or chlorinated solvents near the window — these swell PE. Clean with IPA or mild soap and water only.
- **UV degradation.** Outdoor UV exposure causes PE to yellow and embrittle over time. Inspect the window at each service interval; replace if yellowing or surface crazing is visible, as this scatters LWIR and degrades thermal image uniformity.
- **Silicone outgassing.** PE is non-polar; siloxane physisorption from silicone coating outgassing is lower on PE than on polar or crystalline surfaces. However, the precaution of not closing the enclosure until the 72 h off-gas period is complete still applies — primarily to protect the AHT20, not the window. See Section 0, Silicone Risk 2.
- The window is part of the enclosure, not the PCB assembly, and is not subject to the conformal coating process.
- The window must not impinge on the 57° H / 71° D optical keep-out cone.

### Conformal Coating — FLIR Lepton 3.5 Module

```
FLIR Lepton 3.5 — Side View (with shutter)

        ┌── Germanium lens window ──┐
        │     ╔═══════════╗         │
◄──────►│     ║  LWIR     ║         │   NO COAT on any surface
57° FoV │     ║  sensor   ║         │   NO COAT on lens
        │     ╚═══════════╝         │   NO COAT on shutter pins
        └───────────────────────────┘   NO COAT on 32 side contacts
                 │ │ │ │ │ │ │ │
            ─ ─ ─ ─ ─ ─ ─ ─ ─ ─ ─ ─   ← 32-pin side contacts
            (mate into Molex socket)
```

| Zone | Treatment |
|---|---|
| Germanium lens window | **NO COAT** — any coating blocks LWIR; permanent damage |
| Shutter actuator pins (sides) | **NO COAT, NO OBSTRUCT** — shutter event exerts force; coating can jam mechanism |
| 32-pin side contacts | **NO COAT** — must make wiping contact with socket; coating prevents seating |
| Module housing | **NO COAT** — module must remain removable from socket |

> **The Lepton module as a whole must never enter a coating process.** Remove from socket before board coating. Reinstall after coating is fully cured and masking removed.

**Official Resources**
- Engineering Datasheet Rev 400: Teledyne FLIR Doc. # 500-0771-01-09 (on file at `Docs/instructions/`)
- Mechanical IDD for Lepton 3.5: 500-0771-41 (request from Teledyne FLIR)
- Breakout board schematic: `Docs/instructions/FLIR_Lepton_Breakout_Board_V2_Schematic-16912.pdf`

---

## 4. FLIR Lepton Breakout Board V2.0 (PN: 250-0577-00)

| Attribute | Value |
|---|---|
| PCB | 29.5 × 29.0 mm |
| Total thickness (excl. Lepton) | 15.0 mm (PCB + Molex socket + jumper pins) |
| Lepton socket | 32-pin Molex (105028-1001 compatible) |
| Interface header | J2: 20-pin, 2.54 mm pitch (2×10), 100 mil |
| Input voltage | 3.0 V to 5.5 V |
| Operating temperature | 0°C to 55°C |
| Jumpers | J5–J9 (bypass for voltage/clock/power-up sequence) |

### Keep-Out Zones

**Molex socket.** The 32-pin Molex socket is the mechanical and electrical interface to the Lepton module. The socket has side-contact spring fingers that must make unobstructed wiping contact with the Lepton's pads. No coating, flux, or other material may enter the socket interior or contact the spring fingers.

**Jumpers J5–J9.** These bypass the onboard 1.2 V LDO, 2.8 V LDO, master clock, and power-up sequencer. They are installed by default and configure the board for standard 3–5 V operation. Mask these for coating so they remain reconfigurable if power supply topology changes.

**J2 header (Pi interface).** This 20-pin header connects the breakout board to the Raspberry Pi SPI/I2C/power lines. Mask the header if any chance of future disconnection exists. If permanently wire-soldered, the solder joints can be coated after soldering.

**Mounting holes.** Four 2.0 mm diameter mounting holes at corners (see Fig. 1 in datasheet). Mask holes and surrounding ~2 mm annulus if hardware will be installed after coating; coating inside threaded standoff holes causes poor thread engagement.

### Conformal Coating — Lepton Breakout Board V2.0

```
Lepton Breakout Board V2.0 — Top View (29.5 mm × 29.0 mm)

  J2 (20-pin, 2×10 header) — MASK
  ┌──○─○─○─○─○─○─○─○─○─○──┐
  │  ○─○─○─○─○─○─○─○─○─○  │
  │                        │
  │  ┌──────────────────┐  │
  │  │  32-pin Molex    │  │
  │  │  Lepton socket   │  │
  │  │                  │  │
  │  │  ████ MASK ████  │  │
  │  │  (entire socket  │  │
  │  │   interior and   │  │
  │  │   spring fingers)│  │
  │  └──────────────────┘  │
  │                        │
  │  [J5][J6][J7][J8][J9] ← MASK (jumpers)
  │                        │
  │  Y1  C1–C4  U1  R1–R5 │ ← COAT OK (passives, LDOs, oscillator)
  │                        │
  ○ mounting holes — MASK  ○
  └────────────────────────┘
```

| Zone | Treatment |
|---|---|
| 32-pin Molex socket (entire) | **MASK** — spring fingers must remain unobstructed; coating prevents Lepton seating |
| Jumpers J5–J9 | **MASK** — must remain reconfigurable |
| J2 20-pin header | **MASK** — Pi interface must remain electrically clean |
| Mounting holes (4×) | **MASK** — thread engagement |
| PCB body (LDOs, passives, oscillator Y1, U1) | COAT OK |

> **Lepton module itself:** Remove from socket before coating. Do not coat. Reinstall after curing.

**Official Resources**
- Breakout board datasheet: `Docs/instructions/Lepton Camera Breakout Board-V2.0-Datasheet-US.pdf`
- Schematic: `Docs/instructions/FLIR_Lepton_Breakout_Board_V2_Schematic-16912.pdf`
- Getting started guide: `Docs/instructions/Getting started with the Raspberry Pi and Breakout Board V2.0.pdf`

---

## 5. Dorhea IR-Cut Camera (Optical / NIR)

| Attribute | Value |
|---|---|
| Interface | CSI-2 FPC, 15-pin 1.0 mm pitch (connects to Pi CSI-2 port) |
| Resolution | 2592 × 1944 pixels (~5 MP) |
| IR-cut filter | Motorized, GPIO-controlled (GPIO 21 on Pi) |
| Filter state — LOW | IR filter IN (visible-light-only mode) |
| Filter state — HIGH | IR filter OUT (NIR+visible mode) |
| Filter settle time | ~300 ms mechanical travel; 500 ms software margin |

### Keep-Out Zones

**Lens and image sensor.** The lens assembly and image sensor must be completely clear of coating, condensation, and contamination. Any coating on the lens surface causes permanent image degradation and cannot be cleaned off once cured.

**IR-cut filter motor mechanism.** The motorized IR-cut filter is a precision mechanical assembly. Coating that contacts the filter carriage, motor shaft, or actuator linkage will bind the mechanism. GPIO 21 drives the motor; if the mechanism is seized, the NIR-OFF/NIR-ON capture pair will produce identical images, invalidating the reflectance ratio used for water surface analysis.

**CSI-2 FPC connector.** The 15-pin FPC connects to the Pi's CSI-2 port. Both the connector on the camera board and the lock arm on the Pi must remain free of coating. Keep FPC bend radius above 5 mm; route away from enclosure edges.

**Direct environmental exposure.** Unlike the Lepton, the Dorhea lens has no protective window between it and the scene being filmed. The lens is directly exposed to the environment through the enclosure aperture. Ensure the enclosure aperture is sized and sealed (gasket or O-ring) to prevent rain ingress and condensation from reaching the lens face while preserving the optical field of view. Do not allow standing water to contact the lens — the IR-cut filter motor behind the lens is not rated for immersion.

### Conformal Coating — Dorhea IR-Cut Camera

```
Dorhea IR-Cut Camera — Top View (approximate)

  ┌──────────────────────────────────┐
  │                                  │
  │   ┌──────────────────────────┐   │
  │   │    Lens assembly         │   │
  │   │    + Image sensor        │   │
  │   │                          │   │
  │   │   ████████ MASK ████████ │   │
  │   │   (entire optical path)  │   │
  │   └──────────────────────────┘   │
  │                                  │
  │   IR-cut filter motor            │
  │   ┌──────────────────────┐       │
  │   │ filter carriage/motor│       │
  │   │   ████ MASK ████     │       │
  │   └──────────────────────┘       │
  │                                  │
  │   PCB body                       │
  │   COAT OK (non-optical areas)    │
  │                                  │
  │═══════════════════════════════   │ ← FPC connector
  │   CSI-2 FPC [MASK]               │
  └──────────────────────────────────┘
```

| Zone | Treatment |
|---|---|
| Lens assembly | **MASK** — optical surface; permanent damage if coated |
| Image sensor face | **MASK** — permanent contamination |
| IR-cut filter motor + carriage | **MASK** — mechanical binding; destroys NIR capture capability |
| CSI-2 FPC connector | **MASK** — removable connection to Pi CSI-2 port |
| PCB body (non-optical areas) | COAT OK |

---

## 6. IMU — BNO055 (most units) / BNO085 (some units)

> **Variant note:** Most WaterCam units use the **BNO055**. A small number of units use the **BNO085** (or BNO086). Both share the same LGA-28 footprint and identical conformal coating rules. The differences that matter for this document are I2C address selection and package thickness (see table). Verify which variant is installed before finalizing firmware and I2C address conflict checks.

| Attribute | BNO055 | BNO085 |
|---|---|---|
| Package | LGA-28 | LGA-28 |
| Dimensions | 3.8 × 5.2 × 1.13 mm | 3.8 × 5.2 × 1.1 mm |
| Manufacturer | Bosch Sensortec | Bosch sensors + CEVA SH-2 firmware |
| Interface | I2C or SPI | I2C, SPI, or UART |
| I2C address select | COM3 pin → 0x28 (default) or 0x29 | SA0 pin selectable |
| Operating voltage (VDD) | 2.4–3.6 V | 2.4–3.6 V |

### Keep-Out Zones

**Magnetic keep-out.** The BNO085 contains a triaxial magnetometer used for heading/orientation. Keep the following away from the sensor:

- Power inductors and ferrite beads: minimum 15 mm distance recommended
- Permanent magnets and ferromagnetic hardware (screws, standoffs): minimum 10 mm
- DC motor drivers and high-current traces: route away from BNO085 footprint
- Large copper pours (ground planes) directly underneath can distort the magnetic field; avoid a copper-free zone beneath the sensor on adjacent layers if magnetometer accuracy is critical

**Axis alignment.** The BNO085 coordinate system is defined relative to chip orientation. For IMU-assisted georeferencing, document the rotation matrix between chip axes and geographic/enclosure axes at design time. This is especially important if the board is mounted at a non-standard angle inside the enclosure.

**Vibration isolation.** If the enclosure is subject to vibration from wind or water flow, consider vibration-damping foam under the PCB in the sensor region to avoid accelerometer saturation or high gyro noise.

**Conformal coating.** Both the BNO055 and BNO085 are closed LGA packages with no exposed sensing ports. Both can be coated. Avoid thick coatings (>75 µm) that mechanically stress the LGA solder joints.

### Conformal Coating — BNO055 / BNO085

| Zone | Treatment |
|---|---|
| LGA body (either variant) | COAT OK — closed package, no exposed sensing port |
| PCB around sensor | COAT OK |
| Solder joints | COAT OK — confirm <75 µm thickness to avoid mechanical stress |

**Official Resources**
- BNO055 Datasheet (Bosch Sensortec): https://www.bosch-sensortec.com/media/boschsensortec/downloads/datasheets/bst-bno055-ds000.pdf
- BNO08X Datasheet Rev 1.17 (CEVA/Hillcrest): `Docs/instructions/BNO080_085-Datasheet.pdf`
- Adafruit BNO085 breakout guide: `Docs/instructions/Adafruit-9-DOF-orientation-IMU-fusion-breakout-BNO085.pdf`
- Calibration procedure: `Docs/instructions/BNO080-BNO085-Sensor-Calibration-Procedure.pdf`

---

## 7. AHT20 (Aosong)

| Attribute | Value |
|---|---|
| Package | DFN-6 (3×3 mm) |
| Dimensions | 3.0 × 3.0 × 1.0 mm |
| Accuracy | ±2% RH, ±0.3°C (typical) |
| Interface | I2C, fixed address 0x38 |

### Keep-Out Zones

**Airflow / sensor opening.** The AHT20 has a rectangular sensing port on the top surface. This must be exposed to ambient air — do not cover it with conformal coating, epoxy, or any mechanical obstruction. If the sensor is inside an enclosure, the datasheet recommends a window in the housing that allows air exchange while minimizing the influence of air trapped inside the enclosure.

**Thermal isolation.** The AHT20 measures ambient temperature. Placing it near heat sources (voltage regulators, cellular modem, Pi SoC) will produce elevated temperature readings. The AHT20 datasheet (Aosong, Fig. 8–10) recommends adding PCB milling slots around the sensor footprint to reduce thermal conduction from the board.

**Humidity equilibration.** After exposure to solvents (flux cleaning, conformal coating), the AHT20 should be equilibrated at ambient conditions for 24 hours, or baked at >50°C for several hours, before taking calibrated readings.

### Conformal Coating — AHT20

```
AHT20 DFN-6 (3 mm × 3 mm) — Top View

  ┌─────────────────┐
  │  ┌───────────┐  │
  │  │  Sensing  │  │
  │  │   port    │  │ ← MASK this opening
  │  │  ██████   │  │    before coating
  │  └───────────┘  │
  │                 │
  │  DFN body       │ ← COAT OK (except port)
  └─────────────────┘
```

| Zone | Treatment |
|---|---|
| Sensor port (rectangular opening, top surface) | **MASK** — must be open to ambient air |
| DFN package body | COAT OK |
| PCB around AHT20 | COAT OK |

> **Post-coating:** Remove AHT20 sensor port mask last. Allow 24 h equilibration at ambient before trusting humidity/temperature readings.

**Official Resources**
- Datasheet (Aosong official): https://www.aosong.com/userfiles/files/media/Data%20Sheet%20AHT20.pdf
- SparkFun mirror: https://cdn.sparkfun.com/assets/d/2/b/e/d/AHT20.pdf
- Adafruit guide: `Docs/instructions/Adafruit-AHT20_TempHumiditySensor.pdf`

---

## 8. Quectel EC25 (LTE Cat 4)

> Confirm which form factor is in use: standard LCC module or Mini PCIe variant. Dimensions differ significantly.

| Attribute | LCC Module | Mini PCIe |
|---|---|---|
| Dimensions | 29.0 × 32.0 × 2.4 mm | 30.0 × 50.95 × 4.5 mm |
| Interface | LCC pads (solder to PCB) | Edge connector (52-pin) |
| Antenna | U.FL connector(s) | U.FL connector(s) |

### Keep-Out Zones (both variants)

**RF antenna keep-out.** The cellular antenna connects via U.FL. The U.FL connector requires a minimum 1 mm clearance on all sides for mating/unmating. The antenna cable/trace must route away from digital signal lines, switching regulators, and the LoRa module antenna.

**Under-module copper.** Quectel's hardware design guides specify that no copper pour or signal routing should be placed under the module footprint on the top layer.

**Thermal keep-out.** The EC25 generates meaningful heat during active data transmission. Keep temperature-sensitive components (AHT20, BNO085) at least 20 mm away or provide a thermal break.

**eSIM/SIM connector.** If using a nano-SIM socket, ensure clearance for card insertion/removal. If using the 1NCE eSIM, no physical access is needed.

### Conformal Coating — EC25

```
EC25 Module — Top View (LCC variant, 29 mm × 32 mm)

  ┌──────────────────────────────────┐
  │                                  │
  │   RF shield (metal can)          │
  │   COAT OK (exterior)             │
  │                                  │
  │                    ┌──┐          │
  │                    │  │ U.FL     │
  │                    │██│ MASK     │
  │                    └──┘          │
  │                                  │
  └──────────────────────────────────┘
  (LCC pads on underside — coat after soldering is OK)
```

| Zone | Treatment |
|---|---|
| EC25 module body (RF shield exterior) | COAT OK |
| U.FL connector(s) | **MASK** — coax cable must mate; coating prevents connection |
| SIM socket (if nano-SIM) | **MASK** — card insertion |
| LCC solder pads | COAT OK after soldering |

**Official Resources**
- Hardware Design v2.2: https://forums.quectel.com/uploads/short-url/yVwhmS9iLDp8K24V93xJw3L6zmS.pdf
- Hardware Design v1.3 (Pine64 mirror): https://files.pine64.org/doc/datasheet/project_anakin/LTE_module/Quectel_EC25_Hardware_Design_V1.3.pdf
- Quectel product page: https://www.quectel.com/product/lte-ec25-series/

---

## 9. MultiTech mDot (MTDOT-915 Series)

| Attribute | XBee Form (X1-SMA) | SMT Form (M1-UFL) |
|---|---|---|
| Dimensions | 33.02 × 27.69 × 3.81 mm | ~28.6 × 21.0 mm (verify) |
| Frequency | 915 MHz (US) | 915 MHz (US) |
| Antenna | SMA (external) or U.FL | U.FL |
| Interface | XBee socket (through-hole) or SMT | SMT pads |

### Keep-Out Zones

**RF keep-out.** For the SMA variant, a minimum 5 mm clear zone around the antenna connector body is required for connector access. For U.FL variants, apply the same 1 mm rule as the EC25 U.FL connectors. The LoRa antenna should be routed away from the cellular antenna (minimum 15–20 mm separation recommended for co-located antennas at 900 MHz vs. 700–2100 MHz cellular bands, or use orthogonal polarizations).

**Under-module copper.** Same rule as the EC25: no signal routing under the module footprint.

**XBee socket clearance.** If using the through-hole XBee socket variant, the socket adds approximately 4 mm in height below the PCB and requires clearance on both sides for the module to seat and unseat.

### Conformal Coating — mDot

| Zone | Treatment |
|---|---|
| mDot module body | COAT OK |
| U.FL connector(s) | **MASK** — coax cable must mate |
| SMA connector (if applicable) | **MASK** — antenna cable must thread on |
| XBee socket (if through-hole) | **MASK** — module must seat/unseat |

**Official Resources**
- Developer Guide with mechanical drawings (Chapter 2): https://multitech.com/wp-content/uploads/S000612-mDot-Developer-Guide.pdf
- Developer Guide DB9 rev: https://multitech.com/wp-content/uploads/s000612_DB9.pdf
- MultiTech developer resources: https://www.multitech.net/developer/products/multiconnect-dot-series/multiconnect-mdot/

---

## 10. HAT Stack Summary

When using the Pi 4B with the WittyPi 4 HAT stacked on top, the combined assembly height is approximately:

| Layer | Height |
|---|---|
| Pi 4B PCB + tallest component (USB-A) | ~16.4 mm (1.4 mm PCB + 15 mm component) |
| WittyPi 4 SMT header standoff | 3.5 mm |
| WittyPi 4 PCB thickness | ~1.6 mm |
| WittyPi 4 tallest component (approx.) | ~10 mm (DC/DC converter) |
| **Total stack height (approx.)** | **~33 mm** |

This is an estimate. Measure actual component heights against the WittyPi 4 STEP file and Pi 4B mechanical drawing to confirm enclosure sizing.

---

## 11. Special Placement Considerations

### I2C Bus Conflict Check

| Component | Default I2C Address | Notes |
|---|---|---|
| BNO055 (most units) | 0x28 (default) or 0x29 | COM3 pin selects; 0x28 is default |
| BNO085 (some units) | SA0 pin selectable | Confirm address against your specific board |
| AHT20 | 0x38 (fixed) | Cannot be changed |
| WittyPi 4 RTC (DS3231SN) | 0x68 (proxied by WittyPi MCU, configurable) | |
| WittyPi 4 temp sensor (MCP9808) | Proxied by WittyPi MCU | |

No address conflicts in the default BNO055 configuration (0x28/0x29 do not conflict with 0x38 or 0x68). Confirm WittyPi 4 I2C proxy address avoids 0x28, 0x29, and 0x38. For BNO085 units, confirm SA0 pin address selection does not conflict with WittyPi 4's proxied address.

### Antenna Separation

Keep the EC25 cellular antenna and mDot LoRa antenna physically separated and preferably orthogonally polarized. Minimum recommended center-to-center distance between antenna cables is 15 mm. Route antenna cables along opposite edges of the enclosure interior if possible.

---

## 12. Conformal Coating — Complete Mask Summary

| Component | Zone | Treatment | Reason |
|---|---|---|---|
| FLIR Lepton 3.5 | Entire module | **NO COAT, remove before coating** | Not a sealed assembly; contacts must wipe clean |
| FLIR Lepton 3.5 | Lens (internal) | **NO COAT** | Blocks LWIR 8–14 µm |
| FLIR Lepton 3.5 | Shutter pins | **NO COAT, NO OBSTRUCT** | Shutter actuation force |
| Lepton Breakout V2.0 | Molex 32-pin socket | **MASK** | Spring fingers must remain clean |
| Lepton Breakout V2.0 | Jumpers J5–J9 | **MASK** | Must remain reconfigurable |
| Lepton Breakout V2.0 | J2 20-pin header | **MASK** | Pi interface |
| Lepton Breakout V2.0 | Mounting holes | **MASK** | Thread engagement |
| Lepton Breakout V2.0 | PCB body | COAT OK | |
| Dorhea IR-Cut Camera | Lens assembly | **MASK** | Visible-light optical surface |
| Dorhea IR-Cut Camera | Image sensor | **MASK** | Permanent contamination |
| Dorhea IR-Cut Camera | IR-cut filter motor | **MASK** | Mechanical binding kills NIR capture |
| Dorhea IR-Cut Camera | CSI-2 FPC connector | **MASK** | Removable Pi connection |
| Dorhea IR-Cut Camera | PCB body | COAT OK | |
| AHT20 | Sensor port (top) | **MASK** | Must breathe ambient air |
| AHT20 | DFN body | COAT OK | |
| BNO055 / BNO085 | LGA body | COAT OK | Closed package; <75 µm thickness |
| Raspberry Pi 4B | USB-A, USB-C, RJ45, HDMI | **MASK** | Connector contacts |
| Raspberry Pi 4B | MicroSD slot | **MASK** | Card must insert |
| Raspberry Pi 4B | GPIO 40-pin header | **MASK** | WittyPi HAT connection |
| Raspberry Pi 4B | CSI-2 FPC connector | **MASK** | Camera FPC connection |
| Raspberry Pi 4B | DSI FPC connector | **MASK** | Future display or service |
| Raspberry Pi 4B | PCB body | COAT OK | |
| WittyPi 4 | 40-pin GPIO header | **MASK** | Contacts Pi GPIO |
| WittyPi 4 | DC screw terminal | **MASK** | Power wiring |
| WittyPi 4 | PCB body | COAT OK | |
| EC25 | U.FL connectors | **MASK** | Antenna coax |
| EC25 | SIM socket (if nano-SIM) | **MASK** | Card insertion |
| EC25 | Module body | COAT OK | |
| mDot | U.FL / SMA connectors | **MASK** | Antenna connection |
| mDot | XBee socket (if used) | **MASK** | Module seating |
| mDot | Module body | COAT OK | |

### Coating Process Order — Acrylic (Third-Party / Standard)

1. **Remove** FLIR Lepton module from Breakout Board socket. Set aside in anti-static bag.
2. Apply all masking materials (tape or peelable latex) to zones listed as MASK above.
3. Apply acrylic conformal coating (25–75 µm) by selective spray or brush. Do not flood coat — low pressure to avoid spray ingress under masking at connector edges.
4. Allow full cure (typically 30 min tack-free, 24 h full cure).
5. Remove all masking.
6. Inspect: no coating in socket, no coating on lens, no coating on filter motor.
7. Wait 24 h before trusting AHT20 humidity readings (solvent equilibration).
8. Reinstall FLIR Lepton module. Install board into enclosure.

> **Silicone builds:** See [Section 0 — Revised Process Order for Silicone](#revised-process-order--silicone-builds) for the extended procedure including 72 h off-gas period and AHT20 reference check.

---

## Document Notes

- Dimensions marked as "approx." or without a cited source should be measured from STEP/3D models or manufacturer drawings before use in a PCB layout.
- The WittyPi 4 SMT header height changed from 2.0 mm to 3.5 mm as of August 2025 (Adafruit product page). If your unit predates this change, adjust HAT stack height accordingly.
- The EC25 variant in use (LCC vs. Mini PCIe, and regional suffix: -AF, -A, etc.) determines the exact footprint. Verify against your specific part number.
- The mDot SMT variant dimensions should be confirmed against the MultiTech developer guide mechanical drawings (Chapter 2) for the specific MTDOT part number in use.
- **IMU variants (Rev 0.2):** Most WaterCam units use the BNO055 (I2C address 0x28/0x29 via COM3 pin). A small number of units use the BNO085 (CEVA SH-2 firmware, SA0 pin address select). Both are LGA-28; conformal coating rules are identical for both variants. Magnetic keep-out distances are the same.
- **Camera correction (Rev 0.2):** Prior revision listed "Raspberry Pi Camera Module 3." The installed optical camera is the Dorhea IR-Cut Camera (CSI-2, motorized NIR filter, GPIO 21).
- **Coating materials (Rev 0.3):** Acrylic is the specified coating for third-party-built units and is accurate for the use case (IP65 enclosure, secondary moisture protection). Student-assembled units may use MG modified silicone — see Section 0 for material comparison, outgassing risks, and the silicone-specific process order. Key difference: silicone builds require 72 h open-air off-gas before enclosure installation to protect the AHT20 humidity sensor.

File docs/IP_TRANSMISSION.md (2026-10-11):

# IP Transmission — WaterCam over WiFi/Cellular

**Status:** Complete — standalone client and TickTalkPython integration both implemented.  
**Branch:** `CellTransmit`  
**Last updated:** 2026-04-14

---

## Overview

The WaterCam device normally sends sensor data over LoRa via an mDot modem.
On deployments with WiFi or cellular access, the same data can be sent directly
to the FastAPI server over HTTP.  Both transports produce identical readings in
InfluxDB and the dashboard — the only difference is the delivery path.

```
Sensors ──┬── LoRa (mDot → ChirpStack → POST /chirpstack/uplink)
           └── IP  (requests → POST /ip/uplink)
                            └── GET /ip/downlink/{device_id}  (polling)
```

The server auto-sets `transport_type = "ip"` for any device that hits the
`/ip/uplink` endpoint, which makes the `/downlink` router queue commands
for polling instead of pushing them through ChirpStack.

---

## Files

| File | Purpose |
|---|---|
| `tools/transmit_ip.py` | `IPTransmitter` class — uplink POST and downlink poll |
| `runtime_config.json` → `ip_upload` | All user-tunable settings |
| `tests/test_ip_upload.py` | Integration tests against a live server |
| `docs/IP_TRANSMISSION.md` | This document |

---

## Configuration (`runtime_config.json`)

Add or edit the `ip_upload` block:

```json
"ip_upload": {
  "enabled": false,
  "server_url": "http://localhost:8000",
  "api_key": "",
  "device_id": "watercam-001",
  "timeout_s": 15,
  "retry_attempts": 3,
  "retry_backoff_s": 2,
  "fallback_to_lora": true,
  "only_if_lora_unavailable": true,
  "cellular_connection": "Quectel",
  "cellular_connect_timeout_s": 90
}
```

| Key | Type | Description |
|---|---|---|
| `enabled` | bool | Master switch. Set `true` to activate IP transport. |
| `server_url` | str | Base URL of the FastAPI server, no trailing slash. |
| `api_key` | str | This unit's own IP API token, sent as `Authorization: Bearer <token>` on uplinks and downlink polls. Issued once per device on the dashboard (Management → IP access token). Required when the server runs `IP_AUTH=enforce`; until then a missing token is accepted and logged (API `docs/IP_TRANSPORT.md`). |
| `device_id` | str | Logical device identifier used for all uplinks and downlink polling. Must be unique per deployment. |
| `timeout_s` | int | Per-request timeout in seconds. |
| `retry_attempts` | int | Max POST attempts before giving up (backoff between attempts). |
| `retry_backoff_s` | float | Base sleep between retries. Before attempt N, waits `retry_backoff_s * 2^(N-1)` seconds (exponential backoff). |
| `fallback_to_lora` | bool | Intent flag for the TickTalkPython integration layer: if IP fails, fall back to LoRa. Not enforced by `transmit_ip.py` itself. |
| `only_if_lora_unavailable` | bool | Default `true`: skip the IP uplink while the mDot is joined (LoRa first). `false` sends over both. |
| `cellular_connection` | str | Default `"Quectel"`: the LTE modem's NetworkManager connection, brought up only when the server can't be reached over WiFi. Managed only if its autoconnect is off. `""` leaves the modem alone. See [Transport order](#transport-order-lora-wifi-cellular). |
| `cellular_connect_timeout_s` | int | How long `nmcli` may take to bring the connection up (default 90; re-attaching took 3–51 s on 006). |

---

## `IPTransmitter` Class

```python
from tools.transmit_ip import IPTransmitter

tx = IPTransmitter()  # reads runtime_config.json automatically
```

### Constructor options

```python
IPTransmitter(
    config_path="runtime_config.json",  # path to config
    override_url="http://...",          # skip config server_url
    override_device_id="dev-001",       # skip config device_id
)
```

### `send_uplink(channels, device_ts=None) → dict`

POST sensor readings to `/ip/uplink`.

**`channels`** — list of channel dicts. Each channel encodes one sensor value:

```python
channels = [
    {"code": "00 01", "payload_hex": "000000006710AB12"},  # device timestamp
    {"code": "02 01", "payload_hex": "00000050"},          # battery 80%
    {"code": "05 01", "payload_hex": "0898"},              # temperature 22.00°C
    {"code": "06 01", "payload_hex": "3D"},                # humidity 61%
    {"code": "04 01", "payload_hex": "028F5C2AFAD47800"},  # GPS lat/lon
    {"code": "07 17", "payload_hex": "00000001"},          # flood detected
    {"code": "08 18", "payload_hex": "FF00FF00..."},       # flood bitmap (variable)
]
result = tx.send_uplink(channels, device_ts=int(time.time()))
```

**Returns:**
```python
{
    "success": True,
    "status_code": 201,
    "response": { "device_id": "...", "decoded": {...}, "ts": "..." },
    "error": None,
    "attempts": 1
}
```

On failure `success` is `False` and `error` contains a human-readable message.
4xx errors are **not retried** (client mistake). 5xx and connection errors are
retried up to `retry_attempts` times.

### `poll_downlink() → dict`

GET `/ip/downlink/{device_id}` to retrieve the oldest queued command.

```python
result = tx.poll_downlink()
if result["success"] and result["command"]:
    cmd = result["command"]
    print(cmd["hex_payload"])   # encoded command to decode/apply
    print(cmd["queue_id"])      # DB id (already marked delivered)
    print(cmd["parts"])         # decoded parts list (may be None)
```

The server marks the command as delivered **atomically on retrieval** — there is
no separate acknowledge call. Once polled, the command is consumed.

**Returns:**
```python
{
    "success": True,
    "status_code": 200,
    "command": {                  # or None if nothing queued
        "queue_id": 42,
        "hex_payload": "...",
        "parts": [...],
        "created_at": "2026-04-14T12:00:00+00:00"
    },
    "error": None
}
```

### `is_reachable() → bool`

Quickly checks if `/health` responds with HTTP 200. Use this before deciding
whether to attempt IP or fall back to LoRa.

---

## Channel Encoding Reference

The server's `CHANNEL_REGISTRY` maps 2-byte codes to sensor fields.  The
`payload_hex` for each channel must be exactly the right length and use
**big-endian byte order**.

| Code | Field | Bytes | Encoding |
|---|---|---|---|
| `00 01` | `device_ts` | 8 | uint64 — UNIX seconds |
| `01 04` | `emergency_status` | 4 | uint32 bool (0 or 1) |
| `02 01` | `battery_pct` | 4 | uint32 (0–100) |
| `03 01` | `imu_block` | 12 | 3× int32 accel (mg), or custom IMU packing |
| `04 01` | `gps_block` | 8 | int32 lat\_microdeg, int32 lon\_microdeg |
| `05 01` | `temperature_c` | 2 | int16 (value × 100) |
| `06 01` | `humidity_pct` | 1 | uint8 (0–100) |
| `07 17` | `camera_flood_detect` | 4 | uint32 bool |
| `07 27` | `camera_new_local_max` | 4 | uint32 bool |
| `08 18` | `camera_flood_bitmap` | variable | raw bitmap bytes |
| `09 19` | `sr_area_threshold_pct` | 4 | uint32 |
| `09 29` | `sr_stage_threshold_cm` | 4 | uint32 (cm) |
| `09 39` | `sr_monitoring_frequency` | 4 | uint32 |
| `09 49` | `sr_emergency_frequency` | 4 | uint32 |
| `09 59` | `sr_neighborhood_emerg_freq` | 4 | uint32 |

**Encoding examples (Python `struct`):**

```python
import struct, time

# device_ts — 8 bytes
struct.pack(">Q", int(time.time())).hex()

# battery_pct — 4 bytes
struct.pack(">I", 75).hex()          # → "0000004b"

# temperature_c — 2 bytes (22.50°C → 2250 → 0x08CA)
struct.pack(">h", int(22.50 * 100)).hex()

# humidity_pct — 1 byte
struct.pack(">B", 61).hex()          # → "3d"

# gps_block — 8 bytes (40.7128°N, -74.0060°W — placeholder)
struct.pack(">ii", int(40.7128 * 1e6), int(-74.0060 * 1e6)).hex()

# flood bitmap — variable
bitmap_bytes = b'\xff\x00\xff\x00'   # 8 pixels, alternating
bitmap_bytes.hex()
```

---

## Server API Endpoints

All endpoints are on the FastAPI server (`../API`).  
Base path: `{server_url}/` (no version prefix currently).

### `POST /ip/uplink`

Receive sensor data from an IP device.

**Request body:**
```json
{
    "device_id": "watercam-001",
    "device_ts": 1712000000,
    "channels": [
        {"code": "02 01", "payload_hex": "00000050"},
        {"code": "05 01", "payload_hex": "0898"}
    ]
}
```

- `device_ts` — optional; if omitted, server time is used.
- `channels` — at least one required (or provide `payload_hex` for raw TTLoRa hex).
- Side effect: device `transport_type` is set to `"ip"` on first call.

**Response (201):**
```json
{
    "device_id": "watercam-001",
    "channel": "multi",
    "ts": "2026-04-14T12:00:00+00:00",
    "decoded": {
        "battery_pct": { "value": 80, "unit": "%" },
        "temperature_c": { "value": 22.0, "unit": "°C" }
    }
}
```

### `GET /ip/downlink/{device_id}`

Poll for the oldest pending queued command.

**Response (200) — command pending:**
```json
{
    "command": {
        "queue_id": 42,
        "hex_payload": "09192A...",
        "parts": [...],
        "created_at": "2026-04-14T11:55:00+00:00"
    },
    "message": "Command retrieved successfully"
}
```

**Response (200) — nothing queued:**
```json
{"command": null, "message": "No pending commands"}
```

The command is marked delivered **atomically** when retrieved. No ACK needed.

### `POST /ip/device/{device_id}/transport`

Manually set the transport type for a device.

```json
{"transport_type": "ip"}
```

Usually not needed — `/ip/uplink` sets `transport_type = "ip"` automatically.

---

## Running the Tests

```bash
# From the project root:
python tests/test_ip_upload.py

# Or with pytest:
pytest tests/test_ip_upload.py -v

# Point at a different server:
WATERCAM_SERVER_URL=http://192.168.1.50:8000 python tests/test_ip_upload.py

# Use a different device ID (avoids polluting production data):
WATERCAM_DEVICE_ID=test-device-ci python tests/test_ip_upload.py
```

The tests **skip** (rather than fail) if the server is unreachable, so they are
safe to include in CI pipelines where the API may not be running.

Tests that create real readings in InfluxDB/SQLite — the `device_id` used during
testing will appear in the dashboard.  Use `WATERCAM_DEVICE_ID=...` to isolate
test traffic from production devices.

---

## Smoke-Testing the Transmitter Directly

```bash
python tools/transmit_ip.py
```

This encodes a minimal uplink (timestamp + battery + temperature) using values
from the script's `__main__` block and prints the server's response.  The server
URL and device ID come from `runtime_config.json`.

---

## TickTalkPython Integration

**Status: Complete** as of 2026-04-14.

Two `@SQify` functions have been added to `ticktalk_main.py`:

### `ip_uplink_transmit(bitmap, sensor_tracker)` (line ~1496)

Collects a subset of sensor data (AHT20 temperature/humidity, GPS, WittyPi
battery, flood bitmap, flood detect flag, and runtime threshold parameters),
encodes it as channel-coded hex, and POSTs to `/ip/uplink`.  IMU orientation
is intentionally omitted (no `03 01` channel).  Called from `ttmain` immediately
after `lora_return`:

```python
lora_return = lora_token_with_tracker(bitmap, sensor_tracker)
ip_return   = ip_uplink_transmit(lora_return, sensor_tracker)  # lora_return is the bitmap
shutdown_result = call_shutdown(ip_return)
```

The IP uplink runs after LoRa, and the shutdown waits for it, so an upload
(or a cellular bring-up) is never cut off.  A failure in IP never affects LoRa
and vice versa.

### Transport order: LoRa, WiFi, cellular

On by default. Each capture's IP uplink:

1. **LoRa.** While the mDot is joined (`AT+NJS?` through the LoRa daemon), the
   IP uplink is skipped, and a cellular session left up is taken down.
2. **WiFi.** Otherwise the server is tried over WiFi. NetworkManager prefers
   WiFi's route (metric 600) to the modem's (700). If a cellular session is up
   and WiFi has reconnected, the session is taken down first.
3. **Cellular.** If the server is still unreachable, `nmcli connection up`
   brings the modem's data connection up, the reading and queued backlog are
   sent, and any downlink command is collected (the wake-start poll had no
   route). The connection then stays up for the session, until LoRa or WiFi
   returns or the Pi powers off. If the server can't be reached over it either,
   it is taken down straight away.

Only a connection with autoconnect **off** is managed. A unit whose `Quectel`
connection still autoconnects keeps cellular up as before, so a field unit
reached over cellular doesn't lose its link until it is set up for this.

**Capture ID.** The capture time, the moment `get_time` fired for that capture
(`tools/capture_time.py`), identifies it on every transport: `device_ts` in the
IP uplink, and channel `00 01` in the LoRa sensor packets. The LoRa bitmap
packet carries no ID, so that every byte goes to the bitmap. It is sent straight
after the full sensor packet, and the API gives it that packet's capture time
when the LoRaWAN frame counters are consecutive. Captures are at least 30 s
apart, so the capture time is unique per unit.

- **On the node:** while LoRa isn't joined, each capture is also queued for LoRa
  store-and-forward. When IP delivers a reading (live or from its own queue),
  the LoRa entry with the same capture time is removed.
- **On the server:** the API keeps the first arrival of each part of a capture
  (sensors, bitmap) and drops later ones, whichever transport they came by
  (API `app/capture_dedup.py`). This also covers what the node can't know: LoRa
  uplinks are unconfirmed, and an HTTP retry can post twice.

Set up on the unit (checks and remote-access caveats are in
[FIELD_DEPLOYMENT_GUIDE.md](FIELD_DEPLOYMENT_GUIDE.md#151-keep-the-cellular-modem-off-unless-lora-and-wifi-fail)):

```bash
sudo nmcli connection modify Quectel connection.autoconnect no   # no data at boot
sudo install -m 644 config/polkit/50-watercam-networkmanager.rules /etc/polkit-1/rules.d/
```

The polkit rule lets `pi` (ticktalk has no login session) control NetworkManager
connections. The modem stays registered on the network without a data
connection: that costs no measurable power (see
[POWER_ANALYSIS.md](POWER_ANALYSIS.md)) and keeps GPS working. Cellular is
kept as the last resort for **data**, not power: a wake over cellular used
126–474 KB on 006, of which our own traffic was about 10 KB; the rest was
Tailscale ([CELLULAR_DATA.md](CELLULAR_DATA.md)).

**Effect on the other units:** with the defaults, units with `ip_upload.enabled`
stop sending over IP while their LoRa is joined.

**Sensor data collected:**
- AHT20: `temperature_celsius` → channel `05 01`, `relative_humidity` → `06 01`
- GPS: `gps_lat` / `gps_lon` → channel `04 01`
- WittyPi: `battery_voltage` converted to % → channel `02 01`
- Bitmap: contents → channel `08 18`; flood detect flag → channel `07 17`
- Runtime params: area/stage thresholds, frequencies → channels `09 19`–`09 59`

**Reachability check:** `is_reachable()` is called before encoding; if the
server doesn't respond, the function returns `{"status": "unreachable"}` without
spending time on encoding.

### `ip_downlink_poll_and_apply(lora_init)` (line ~1647)

Polls `/ip/downlink/{device_id}` once per wake cycle and applies any queued
parameter-update commands.  Called after `initialize_lora_integration` so
updated thresholds are in effect for the capture cycle that follows:

```python
lora_init   = initialize_lora_integration(trigger)
ip_downlink = ip_downlink_poll_and_apply(lora_init)  # NEW
```

**Downlink command codes handled** (from server `app/encoders.py`):

| Code | Name | Decoding | `set_parameter` target |
|---|---|---|---|
| `10 90` | `area_threshold_pct` | u8 direct | `area_threshold` |
| `11 91` | `stage_threshold_cm` | u16 direct | `stage_threshold` |
| `12 92` | `monitoring_freq_h` | u8 index → `[1,3,6,24,72]` hrs → ×60 | `monitoring_frequency` (min) |
| `13 93` | `emergency_freq_min` | u8 index → `[2,5,10]` min | `emergency_frequency` |
| `14 94` | `flood_code_freq_min` | u8 index → `[10,20,30,40,50,60]` min | `neighborhood_emergency_frequency` |
| `16 96` | `audio_recording_enabled` | u8 bool | `audio_recording_enabled` |
| `18 98` | remote debug session | u8 × 10 min, 0 = end ([REMOTE_DEBUG_SESSION.md](REMOTE_DEBUG_SESSION.md)) | request for `remote-debug.timer` |
| `21 91` | emergency mode on | u8 hours, 0 = `emergency_max_hours` ([REMOTE_START_AND_EMERGENCY.md](REMOTE_START_AND_EMERGENCY.md)) | `emergency_mode`, `emergency_max_hours`, `emergency_since` |
| `99 99` | emergency mode off | no value | `emergency_mode` |
| `21` | emergency mode on (old code, kept during the transition) | no value | `emergency_mode` |

Unrecognised codes are logged and ignored — forward-compatible with new server
commands.

### Enabling IP in the main application

Set `ip_upload.enabled = true` in `runtime_config.json`.  When disabled (the
default), both `@SQify` functions return immediately without making any network
calls — zero overhead for LoRa-only deployments.

---

## Known Gaps / Next Steps

1. **Full image upload** — not applicable.  Raw camera files (JPG/PGM/CSV) are
   never transmitted; the compressed flood bitmap via channel `08 18` is the
   intended image payload.
2. **Auth — done (API #28).** The server issues each device its own token and checks
   `Authorization: Bearer <token>` on uplinks and downlink polls. Put the token in
   `ip_upload.api_key`; no code change is needed on the node.
3. **GPS decoder bug — fixed (API commit 0a63091)** — `decode_gps_8b` in
   `API/app/decoders.py` had three bugs: 3-byte slices instead of 4-byte,
   `signed=False` which corrupted W-hemisphere longitudes, and raw integer
   field names instead of float degrees.  Fixed and covered by `TestGPSDecoder`
   in `API/tests/test_ip_transport.py`.

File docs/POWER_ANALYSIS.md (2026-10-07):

# WaterCam Power Budget

**Updated:** 2026-10-06, from bench measurements on units 005 and 006 running
current `main` (006 at stock clocks on the packaged kernel since 2026-10-06),
and the field investigation in
[UNIT006_POWER_FAILURE.md](UNIT006_POWER_FAILURE.md).

Every figure below is marked **measured** or **estimate**. The estimates are
there to size things roughly, not to be relied on; the last section lists
what still needs measuring.

---

## Hardware

| Part | Notes |
|---|---|
| Raspberry Pi 4B | Some units run `arm_freq=2000`; stock is 1800 (see [Peaks](#peaks-matter-more-than-averages)) |
| Witty Pi 4 | Power switching, RTC and schedule; always powered |
| Dorhea IR-Cut camera, FLIR Lepton 3.5 | Optical/NIR and thermal capture |
| MultiTech mDot | LoRaWAN, Class C (listens continuously), powered from the Witty Pi's always-on 3.3 V rail |
| Quectel EC25 | LTE modem, on IP-transport units only (006 has one) |
| AHT20, BNO055/BNO085 | Negligible draw |
| Voltaic V50 | 48 Wh usable; A ports 2 A each (3 A combined); solar input capped at about 2 A |
| Voltaic 20 W 6 V ETFE panel | Peaks at 23 W, but the V50 accepts only about 10 W of it |

---

## Measured draw

All figures are the Witty Pi's output (Vout × Iout), from the power logger
(`tools/powerlog.py`, one sample a minute) unless noted.

| State | Power | Source |
|---|---|---|
| Idle, booted, no work | **2.0 W** (0.40 A at 4.90 V) | measured: 005, median of 1,076 samples, no modem |
| Idle, 006 (has the LTE modem) | **2.6 W** (0.53 A at 4.89 V) | measured: 006, median of 2,792 samples. This is a difference between units, not the modem's draw: see [The LTE modem](#the-lte-modem) |
| Two captures, from the first photo to the shutdown request | **3.3–3.8 W** mean, **75–87 mWh** in 73–87 s | measured: five real ticktalk wakes on 006, 2026-10-06, sampled at 5 Hz |
| Peaks during a real wake | **7.5–8 W** (1.50–1.67 A) | measured: same five wakes, stock clocks |
| Brief peaks under synthetic load (camera, inference, 4-core stress, modem) | **8–10 W** (1.8–2.2 A) | measured: 006 load tests at 2000 MHz |
| Off: Witty Pi standby plus the mDot listening | **about 0.05–0.1 W** | estimate: not yet measured |

The one-minute logger is too coarse to integrate a wake, so the 2026-10-06
figures come from a 5 Hz sampler of the same Witty Pi registers. The sampler
itself adds some load, which is in every one of those figures equally.

### The LTE modem

*Measured* on 006, 2026-10-06: five real ticktalk wakes (shutdown intercepted,
so the unit stayed on) with the modem attached or in low power (`AT+CFUN=4`
through ModemManager), uploading over WiFi or cellular.

| Run | Two captures | Mean | Peak |
|---|---|---|---|
| Modem attached, WiFi upload (×2) | 78–79 mWh | 3.7–3.8 W | 1.59–1.67 A |
| Modem in low power, WiFi upload (×2) | 76–87 mWh | 3.6–3.7 W | 1.50–1.63 A |
| Modem attached, cellular upload | 75 mWh | 3.3 W | 1.59 A |
| Cellular on its own: attach, reach the server, back to low power (×2) | 9–53 mWh | 2.8–3.9 W | 1.0 A |

- **An attached, idle modem draws less than the Witty Pi resolves** (about
  0.05 W). Idle was 3.22 W with it attached or in low power, and low power
  didn't lower the peaks either. GPS kept working in low power.
- **Re-attaching took 3 s once and 51 s the next time.**
- **WiFi may cost more than the modem:** with WiFi disconnected, idle fell to
  about 2.6–2.9 W. That comes from a single session and needs confirming.
- **Cellular costs data, not power:** 126–474 KB for a wake over cellular, of
  which our own traffic is about 10 KB; the rest is Tailscale
  ([CELLULAR_DATA.md](CELLULAR_DATA.md)). This is why cellular is the last resort
  ([IP_TRANSMISSION.md](IP_TRANSMISSION.md#transport-order-lora-wifi-cellular)).

---

## One wake, with current software

| Step | Time | Source |
|---|---|---|
| Boot (kernel and userspace) | 11 s | measured: `systemd-analyze` on 005 and 006 |
| Next-wake alarm armed, `ticktalk` starts | about 15 s after boot | measured on 006 when testing #97 |
| Wait for the first capture | none since 2026-10-07: it starts as soon as the sensors are up (`TTStartOnArrival`, `tools/wait_for_sensors.py`); before, it waited for the next minute boundary, 0–60 s, 30 s on average | from the code |
| Two captures 60 s apart (`shutdown_iteration_limit` 2). Each runs photo, co-registration, segmentation (1.6 s via the daemon), compression and transmit, and finishes within about 15 s. | about 75 s | measured: 005 and 006 |
| Shutdown request after the last capture | `ticktalk` start to shutdown request: **1 min 48 s** | measured: 005 and 006, 2026-10-04 |
| Shutdown | about 10 s | estimate |

**A wake lasts about 2 minutes, about 0.12 Wh** (0.11–0.13 Wh).
*Partly measured:* the two captures are 75–87 mWh (above). Boot and shutdown
are estimated at about 35 mWh, as they weren't sampled. Until 2026-10-07 the
first capture also waited for the next minute boundary, at about 3.3 W: about
28 mWh on average, which made a wake about 0.14 Wh.

The Witty Pi schedule's ON window (10 or 15 min) is only a maximum: the Pi
shuts itself down when the cycle ends. Energy depends on the number of wakes,
not the length of the window.

Segmentation used to dominate. Before the SegFormer daemon it took about 40 s
per image (about 95 s on a throttled unit), and the old version of this doc
assumed 2–3 minutes. See
[SEGFORMER_OPTIMIZATION.md](SEGFORMER_OPTIMIZATION.md).

---

## Daily use by schedule

*Estimates.* The off-state draw (0.05–0.1 W, unmeasured) is 1.2–2.4 Wh/day on
its own, so it matters as much as the wakes do.

| Schedule | Wakes/day | Wakes | Off-state | Total |
|---|---|---|---|---|
| `watercam_on15_off1h45_offnight.wpi` (every 2 h, 06:00–22:00) | 9 | 1.1 Wh | 1.2–2.4 Wh | **about 2.5–3.5 Wh/day** |
| `watercam_10minutes_per_hour.wpi` | 24 | 2.9 Wh | 1.2–2.4 Wh | **about 4–5.5 Wh/day** |
| `watercam_daylight_2h.wpi` (every 2 h, 08:00–16:00 EST, daylight only) | 5 | 0.6 Wh | 1.2–2.4 Wh | **about 2–3 Wh/day** |

**These are best cases.** The schedules assume every wake ends with a clean
shutdown.

- **When one doesn't,** the Pi can stay up for the whole ON window or longer, at 2–2.6 W.
- **9 full 15-minute windows** come to about 6 Wh plus the off-state.
- **In the field, 006's use was roughly 12–15 Wh/day** in June–August, on older software. Only 20–37 wakes a month ended with a logged clean shutdown. See [UNIT006_POWER_FAILURE.md](UNIT006_POWER_FAILURE.md#energy-budget).

### Emergency mode

Emergency mode keeps the unit on: `call_shutdown()` ignores the iteration
limit, and the Witty Pi's shutdown schedule is cleared. It captures every
`photo_interval` for as long as it lasts.

- **Draw:** about 3–4.5 W continuously, idle plus a capture each minute, more with the modem. *Estimate.*
- **Per day:** about 70–110 Wh.
- **On the V50 alone:** 48 Wh lasts about **11–16 hours** with no sun.
- **Solar can't sustain it:** a clear day's 20–30 Wh doesn't cover it. Emergency mode needs a time limit (see below).

---

## Solar input and storage

- **The input is capped at about 10 W.** The 20 W panel peaks at 23 W (5.21 V, 4.46 A), but each V50 solar input accepts at most 2 A. *From the spec.*
- **Clear day:** about 20–30 Wh. **Overcast:** about 3–6 Wh. *Estimates* for Syracuse, NY (43°N), June–September; winter yield hasn't been measured.
- **Storage:** 48 Wh usable.
  - At 3–4 Wh/day that's about **12–16 days with no sun**, best case.
  - At the field figure of 12–15 Wh/day, about **3 days**.

On current software, energy is not usually the limit. 006's failure came from:
- **brownouts at wake time**, under fast current peaks
- **the Witty Pi stranding the unit:** once it has been unpowered past its alarm time, it never wakes the Pi again

The fixes are #97 (arm the next wake before the load starts) and #98 (after a power cut, sleep until the battery recovers).

---

## Peaks matter more than averages

- **Clocks:** stock clocks (`arm_freq=1800`) lower the peak current. On 006, 2000 MHz plus the modem browned out the Pi even on a healthy supply. The old advice that overclocking saves energy by finishing sooner no longer holds: inference takes 1.6 s.
- **Wiring:** keep the Y-adapter, so the load is spread across both V50 A ports. Never charge through the V50's top USB-C port while it powers a unit.
- **Overlap:** the IP upload runs after LoRa, once segmentation is done. On 006 the wake's peaks were the same with the modem attached or in low power, so the modem isn't what drives them at stock clocks.

---

## Ideas that still apply

| Idea | Effect |
|---|---|
| Cap emergency mode (e.g. 6–8 h), then fall back to frequent scheduled wakes | Protects the battery during long events |
| Measure the off-state draw; if the mDot dominates, consider whether it must listen overnight | Up to about 1–2 Wh/day |
| Cache the camera's AWB gains across boots | About 5 s per wake |
| Battery-aware scheduling | Needs a real battery measurement first (see [Battery state of charge](#battery-state-of-charge)) |

No longer relevant:
- **Bigger panel:** the V50's 10 W input cap makes it pointless.
- **INT8 or ONNX for speed:** done.
- **Powering the modem down between cycles:** the Pi and modem are fully off between wakes, and only on for about 2.5 minutes.
- **Keeping the modem in low power during a wake:** measured, no saving (see [The LTE modem](#the-lte-modem)).
- **Trimming the ON window:** the Pi already shuts down when its cycle ends.

---

## Battery state of charge

**Today the units have no way to measure it.** Units 005 and 006 have neither
of the sensors `tools/battery_manager.py` supports (ADS1115 at 0x48, INA260 at
0x40). Until 2026-10-07 `battery_pct` was the Witty Pi's output voltage mapped
from 4.75 V (0 %) to 5.10 V (100 %). But the V50's 5 V output is regulated, so
the voltage moves with load and cabling, not charge: a wall-powered unit read
37–54 % within minutes, and the noise set off LoRa sends. Since then no
battery percentage is sent; the Witty Pi voltage is kept for diagnostics only.

### Planned: read the V50's own charge signal through the mDot

The V25, V50 and V75 put about half the cell voltage on the **USB-C D+ pin**
([Voltaic](https://blog.voltaicsystems.com/reading-charge-level-of-voltaic-usb-battery-packs/)):
roughly 1.85–2.1 V full, and about 1.73 V when the pack turns its USB output
off. The mDot can read it with no new chips:

- **ADC pin:** `PB_0` is unconnected on the main-branch HAT and unused in
  mDot-AT-firmware. In use: `PB_1` (Witty Pi switch, heartbeat, emergency out),
  `PA_5` (boot), `PC_1` (Pi state), `PA_6` (emergency in), `PC_4`/`PC_5` (ID).
  Spare ADC alternatives: `PA_1`, `PA_4`, `PA_0` (wake pin), `PA_7`.
- **Always readable:** the mDot runs from the Witty Pi's always-on 3.3 V rail,
  so it can read the pack while the Pi is off (a resting voltage, more accurate
  than one under load). Its ADC reference is about 3.0 V.
- **Wiring:** a USB-C breakout in the V50's top port with **only D+ and GND**
  connected (never VBUS; that port is the one that sagged when charging through
  it). D+ to `PB_0` through about 10 kΩ, with 100 nF from the pin to GND, and
  the V50's ground shared with the HAT.
- **Firmware:** a new AT command in mDot-AT-firmware that reads `AnalogIn(PB_0)`
  and returns the voltage (built in Mbed Studio).
- **Node software:** a new first path in `battery_manager.py` that asks the
  mDot through the LoRa daemon, with the D+ to cell-voltage scale (about 2×)
  calibrated per pack.
- **Calibration:** run the full drain test (below) with D+ logged once a
  minute, to map D+ to charge and set the empty point. Fix `CELL_V_MIN` while
  doing it: 3.0 V now, but the V50 cuts out at about 3.45 V per cell.
- **Accuracy to expect:** about ±10–15 % of charge mid-range, where a Li-ion
  cell's voltage is flat. Better near empty, which is when it matters.
- **v6 HAT:** add a connector for the D+ lead. The KiCad mDot symbol's pin
  numbers don't match MultiTech's guide (PB0/PB1 are swapped, as are PA0/PA7),
  so lay out by pin name and check the footprint.
- **To confirm first:** that the field V50s are the "Always On" model the
  feature is documented for.

Also in `battery_manager.py`: the INA260 path ignores charging and charges the
whole off period at the current measured at boot. Fix it before anyone fits an
INA260.

## Still to measure

1. **Off-state draw:** the Witty Pi plus the mDot listening in Class C, with the Pi off.
2. **Energy per wake, boot and shutdown included:** the captures were sampled at 5 Hz on 2026-10-06; boot and shutdown weren't.
3. **WiFi's draw:** idle looked about 0.3–0.6 W lower with WiFi disconnected, in one session.
4. **Solar charging through the V50's side port:** a load test while it charges from the real panel in sun.
5. **Winter yield** at the 10 W input cap.

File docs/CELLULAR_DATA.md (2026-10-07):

# Cellular Data Use

**Measured:** 2026-10-07 on unit 006 (T-Mobile LTE, Quectel EC25), by recording
`wwan0` and `tailscale0` with `tcpdump` during a real ticktalk wake with WiFi off.
`tailscale0` carries our own traffic before encryption; the rest of what crosses
`wwan0` is overhead. Two wakes of about 100 s each.

Cellular is the last resort: LoRa first, then WiFi (see
[IP_TRANSMISSION.md](IP_TRANSMISSION.md#transport-order-lora-wifi-cellular)).

## Per wake

| | Run 1 | Run 2 |
|---|---|---|
| **Total on `wwan0`** | **474 KB** | **126 KB** |
| Our traffic (API requests, DNS) | 10 KB | 10 KB |
| Tailscale probing every relay (DERP) region over HTTPS | ~280 KB | 0 |
| Tailscale's home relay (no direct path to the API server on cellular, so uploads are relayed) | 64 KB | 42 KB |
| Tailscale coordination server (network map resync) | 33 KB | 44 KB |
| Tailscale direct-path probes to the API server's private addresses (Docker bridges, LAN), which can't answer over cellular | 80 KB | 28 KB |
| Tailscale direct-path probes to the server's public address | 14 KB | 8 KB |
| Tailscale log uploads | 0 | 0 |

- **Most of it comes in the first 15 s after the link comes up** (328 KB and
  72 KB). Whether Tailscale probes every relay region varies: run 2 followed a
  `tailscaled` restart and didn't.
- **While the link stays up,** Tailscale costs about 0.4–2 KB/s (1.5–7 MB an
  hour), mostly the private-address probes. A normal wake keeps cellular up for
  about a minute; in emergency mode the unit stays on, so cellular can stay up
  for hours.
- **Turning off log uploads** (`--no-logs-no-support`) made no difference: no
  log traffic was seen either way.

## Options not yet tried (Tailscale stays, for remote access)

| Option | Saves (estimate) | Needs |
|---|---|---|
| Disable unneeded relay regions in the tailnet policy (`derpMap`, region set to `null`), keeping the home region and a few nearby | up to ~220 KB when the region probing happens | Tailnet admin. Applies to every device on the tailnet. |
| On the node, drop RFC1918 destinations on `wwan0` (nftables) so the private-address probes never reach the modem | 28–80 KB per wake, and most of the steady cost | Node change; check `tailscaled` copes with the dropped sends |
| Tighten the ACL so `tag:watercam` only sees the API server and admin machines (006 sees 11 peers, mostly shared-in devices) | ~15–25 KB, plus fewer updates while up | Tailnet admin. `config/tailscale-acl.txt` is out of date: refresh it from the admin console first. |
| Inbound UDP to the API server's Tailscale port through the campus firewall, so a direct path forms | ~10–25 KB | Campus IT |
| Drop the `/health` check before each upload; one POST per wake | ~5 KB | Node change |

Together these might bring a cellular wake to roughly 40–70 KB. That is an
estimate; confirm it with another recorded wake.

The baseline cost of Tailscale reconnecting its coordination and relay links,
about 30–40 KB per link change, remains while it runs.

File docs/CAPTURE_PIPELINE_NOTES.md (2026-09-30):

# Capture pipeline: detection, gotchas, and a reference run

Operational notes from running the pipeline end to end on node `ufo-01-01-005`, 2026-09-25.
Everything here is measured or reproduced on hardware.

---

## Detecting the cameras

**Do not use `vcgencmd get_camera`.** It belongs to the legacy Broadcom camera stack and returns
nothing useful on the libcamera stack, which is what these nodes run (Debian 13, kernel 6.18). It
reports silence whether or not a camera is attached, so a missing camera and a working one look
identical.

```bash
rpicam-still --list-cameras
```

```
0 : ov5647 [2592x1944 10-bit GBRG] (/base/soc/i2c0mux/i2c@1/ov5647@36)
```

For the thermal side, the Lepton needs SPI:

```bash
ls /dev/spidev*            # expect /dev/spidev0.0 and /dev/spidev0.1
grep -i '^dtparam=spi' /boot/firmware/config.txt
```

`ls /dev/video*` is also a poor test on its own: the libcamera stack exposes `/dev/media*` nodes and
the mapping to `/dev/video*` is not what it was under the legacy stack.

## The Lepton `capture` binary must be found by walking up from the capture directory

`flir()` in `tt_take_photos.py` locates the binary with `_find_project_root()`, which walks **up from
the directory it is given** looking for a file named `capture`. The binaries live in the project
root:

    SU-WaterCam/capture
    SU-WaterCam/lepton

So the capture directory has to sit under the project tree. Production satisfies this by writing to
`images/<timestamp>/`. Capturing somewhere else fails with

    Check Lepton state - capture binary not found: /tmp/capture

and the optical pair still succeeds, so the failure is easy to miss — you get a scene with no
thermal band rather than an error.

## Driving the capture functions directly

`take_two_photos` and `flir` are `@SQify`-decorated for the TickTalk runtime. The plain functions
are reachable through `__wrapped__`:

```python
import tt_take_photos as T
T.take_two_photos.__wrapped__(None, directory)   # optical pair, IR-cut filter toggled between them
T.flir.__wrapped__(directory)                    # Lepton frame + temperatures CSV
```

## The pipeline spans two interpreters

This is by design and matches what `ticktalk_main.segformer()` does with a subprocess:

| stage | interpreter | why |
|---|---|---|
| capture, co-registration | `SU-WaterCam/venv/bin/python3` | picamera2, gpiozero, SimpleITK |
| segmentation | `~/miniforge3/envs/5band/bin/python` | mmseg, mmcv, onnxruntime |

Neither environment can run the other's stage. `mmseg` also only imports with the working directory
set to `segformer_5band`, because the package is vendored there.

## The two five-band TIFFs are not interchangeable

Co-registration writes both, and they differ in channel order and geometry:

| file | channels | size |
|---|---|---|
| `color_preserved_5_band.tiff` | **R, G, B**, thermal, NIR | native 972x1296, 4:3 |
| `final_5_band.tiff` | **B, G, R**, thermal, NIR | 512x512, aspect squashed |

`final_5_band` carries OpenCV's native order straight from `cv2.imread`.
`save_color_preserved_tiff()` is the function that reverses the optical channels, which is what
"color preserved" refers to. Verified against the source JPEG read as true RGB: `color_preserved[0]`
correlates 1.0000 with true red, `final_5_band[0]` correlates 1.0000 with true blue.

**Everything that feeds or reads a model uses `color_preserved_5_band.tiff`**:
`ticktalk_main.segformer()` and `tools/watercam.py` serve it, `photo_processing/export_dataset.py`
trains on it, and `tools/export_segformer_onnx.py` calibrates INT8 on it. The names live in
`CoregistrationConfig` (`MODEL_INPUT_TIFF`, `SEGMENTATION_PNG`) rather than as string literals.

`final_5_band.tiff` is **legacy output, no longer read by any UFONet software.** It is still
written so older captures and external tooling keep working. **Do not feed it to a model.**

### Every TIFF states its own band order

Both writers now set a `BAND_ORDER` tag — `red,green,blue,thermal,nir` for `color_preserved`,
`blue,green,red,thermal,nir` for `final_5_band`, which also carries a `BAND_ORDER_NOTE` saying it is
legacy. The value is the same comma-separated format the exported `.onnx` declares in its `bands`
metadata, so `tools/segformer_daemon.py` compares the file against the model directly instead of
keyword-matching prose band descriptions. `final_5_band` previously carried no band descriptions and
no tags at all, which is how the file easiest to confuse was also the one that said nothing about
itself.

Captures written before the tag existed carry only the prose descriptions, and
`segformer_preprocess.tiff_band_order()` still reads those, so nothing already captured is
invalidated. An audit of all 6489 `color_preserved_5_band.tiff` in the archive found **zero** files
with the bands in the wrong order.

### Mask name

The segmentation mask is `color_preserved_5_band_segmentation.png`. It is named after its input and
cannot be named independently: `segment_tiff_5band.py` takes no output argument and writes
`<input stem>_segmentation.png`. While the mask was still called `final_5_band_segmentation.png`,
the daemon path wrote that name but the subprocess fallback wrote the stem-derived name and then
returned the name it had not written. Masks are resolved through
`coreg_multiple.segmentation_path()`, which accepts the superseded name so directories segmented
earlier stay readable.

## Reference run, sensors through to mask

Node 005, indoors, `iter_100.pth`:

| stage | time | output |
|---|---|---|
| optical pair | 7.9 s | `*-NIR-OFF.jpg` 1,146,071 B, `*-NIR-ON.jpg` 1,062,783 B |
| FLIR Lepton | 3.0 s | `lepton_*.pgm` 64,063 B, `temperatures_*.csv` 96,122 B |
| co-registration | 51.85 s | `final_5_band.tiff` 1,312,028 B, `color_preserved_5_band.tiff` 6,284,508 B |
| segmentation, torch | 28.79 s | mask (972, 1296), water 32.932% |
| segmentation, ONNX | 1.81 s | mask (972, 1296), water 32.891% |

5-band stack `(5, 972, 1296) uint8`, band means R=74.9 G=65.0 B=70.3 TH=97.3 NIR=47.1.

Two things worth reading off this:

- **torch against ONNX agreed on 98.39% of pixels here**, against 94.29% on `lake.tiff` and 93.35%
  on a 23:45 night frame. The disagreement is padding sensitivity scaled by how marginal the
  decisions are, so a well-exposed scene disagrees less. See `segformer_5band/NEXT_CHECKPOINT.md`.
- **Co-registration took 51.85 s here, against 24.20 s and 10.11 s on comparable scenes.** The
  solver's convergence time varies run to run, not just its answer. Once the transform cache is
  seeded this drops to about 1 s regardless.

The 32.9% water on an indoor room is not meaningful. That is a 100-iteration checkpoint, not the
pipeline.

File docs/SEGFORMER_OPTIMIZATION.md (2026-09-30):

# SegFormer 5-Band Performance Optimization

## Current Architecture

### Inference Pipeline

**As of 2026-09-26** `ticktalk_main.segformer()` sends the request to the resident daemon over
`/run/segformer/segformer.sock` and only falls back to a subprocess if the socket is absent. Both
paths are fed `color_preserved_5_band.tiff` and both write
`color_preserved_5_band_segmentation.png`. Measured on node ufo-01-01-005: **2.2 s** via the
daemon, **39.8 s** via the fallback.

The original design, which the strategies below were written against, invoked a fresh subprocess
every wake cycle:

```python
# the historical call
subprocess.Popen(
    ["/home/pi/miniforge3/envs/5band/bin/python",
     "/home/pi/segformer_5band/segment_tiff_5band.py",
     filepath + "/final_5_band.tiff"],
    cwd="/home/pi/segformer_5band"
).wait()
```

Each call was synchronous (`.wait()`), so the entire WaterCam pipeline stalled for the duration of
inference — which is what the daemon removed.

The mask name is not a free choice: `segment_tiff_5band.py` takes no output argument and writes
`<input stem>_segmentation.png`, so it follows from the TIFF name.

### Input Assembly

Co-registration (`tools/coreg_multiple.py`) produces the 5-band TIFF the model reads,
`color_preserved_5_band.tiff`:

| Band | Source | Content |
|---|---|---|
| 1 (R) | NIR-OFF optical | Red channel |
| 2 (G) | NIR-OFF optical | Green channel |
| 3 (B) | NIR-OFF optical | Blue channel |
| 4 | FLIR Lepton 3.5 | LWIR thermal, normalized 8-bit |
| 5 | NIR-ON red − NIR-OFF red | Near-infrared reflectance difference |

Band numbers here are 1-based; `photo_processing/training/` numbers the same bands 0-based.
Every TIFF written from 2026-09-26 states its own order in a `BAND_ORDER` tag
(`red,green,blue,thermal,nir`), in the same format the exported `.onnx` declares in its `bands`
metadata, so `tools/segformer_daemon.py` compares file against model rather than assuming.

Co-registration also writes `final_5_band.tiff`, which is **B, G, R** at a squashed 512×512 —
OpenCV's native order straight from `cv2.imread`. It is legacy output that nothing reads any more.
An earlier revision of this table described that file rather than this one.
`docs/CAPTURE_PIPELINE_NOTES.md` is the canonical reference.

The optical image at 2592×1944 is downsampled by 50% (`SCALE_PERCENT = 50`,
`MAX_IMAGE_SIZE = 1000`) during co-registration, so the TIFF passed to
SegFormer is approximately **1296×972 pixels**.

### Earlier observation (undated, config not recorded)

| Stage | Duration | Power |
|---|---|---|
| Python interpreter + model load | ~10–20 s | 5.5 W |
| Image preprocessing | ~5–10 s | 5.5 W |
| Forward pass (inference) | ~90–150 s | 7.0–7.5 W |
| Postprocessing + PNG write | ~5–10 s | 5.5 W |
| **Total** | **~120–180 s** | **~6.5–7.5 W avg** |

### Measured on node ufo-01-01-005, 2026-09-24

Measured over Tailscale on an idle node (no capture service running), through the deployed
`SingleFileInference5Band` class with the repository-default B0 config and `iter_100` checkpoint.
**No thermal throttling at any point** (`get_throttled=0x0` throughout, peak 69.6 C). The node is
**overclocked (`arm_freq=2000`, `over_voltage=0`)**, so these do not transfer unchanged to a stock
Pi 4B. Environment: torch 1.7.1, onnxruntime 1.19.2, mmcv 1.3.0, mmseg 0.11.0, 4 torch threads.

Real capture (`lake.tiff`, 1296×972), timing `_inference_single` only, so process and model load
are excluded:

| Path | Inference | vs deployed |
|---|---|---|
| torch fp32 (current deployment) | **27.98 s** | 1.00× |
| onnxruntime fp32 (`segformer_5band_dyn.onnx`) | **1.80 s** | **15.5×** |

Synthetic `1×5×512×1024`, repeated runs:

| Path | n | mean | sd | min | max | vs deployed |
|---|---|---|---|---|---|---|
| torch fp32 | 3 | 46.52 s | 1.14 | 45.22 | 47.35 | 1.00× |
| torch int8 dynamic (qnnpack) | 3 | 40.02 s | 1.09 | 38.90 | 41.08 | 1.16× |
| onnxruntime fp32 | 10 | 2.76 s | 0.03 | 2.74 | 2.84 | 16.86× |

The real-capture numbers are lower than the synthetic ones because the test config applies `Resize`
at `img_scale=(1024, 512)`, so inference runs at 512×683 rather than on the full frame.

**The 90–150 s forward pass in the table above is not reproducible here.** That entry is undated and
does not record which config produced it. This configuration resizes before inference and measures
28 s. Treat **28 s as the current deployed baseline**, and the older figure as describing a
whole-frame path rather than this one.

**torch dynamic INT8 is not worth deploying.** It returns 1.16×, against the 3–4× INT8 is usually
quoted at, because `quantize_dynamic` covers only `nn.Linear` and most of this model's cost sits
elsewhere. INT8 through ONNX Runtime is a different mechanism and is still unmeasured.

**Output fidelity: ONNX is faithful, padding is not.** On the real capture, torch and ONNX argmax
agree on only 94.29% of pixels (water fraction 13.724% against 9.285%). That is a padding effect,
not a conversion error:

- On identical padded input, ONNX matches torch to a max absolute logit difference of **5.111e-06**
  and **99.9997%** argmax agreement.
- torch against itself, unpadded 512×683 against padded 512×704, agrees on only **94.33%** with the
  same water-fraction shift, reproducing the entire gap with ONNX absent. The ONNX path pads width
  to a multiple of 32.
- It is amplified by `iter_100` being barely trained: `|logit(water) − logit(bg)|` has median
  0.3942, with **6.72%** of pixels under 0.05 and 1.40% under 0.01. Decisions that marginal flip in
  bulk under any perturbation.

The padding is worth fixing on its own merits, and a properly trained checkpoint should be far less
sensitive to it.

The deployed model is **SegFormer-B0**, not a larger variant. `segment_tiff_5band.py`
defaults to `local_configs/segformer/B0/segformer.b0.512x512.flood_5band_2cls.65k.test.py`
(`type='mit_b0'`, `pretrained='pretrained/mit_b0.pth'`) with the checkpoint
`work_dirs/segformer.b0.512x512.flood_5band_2cls.65k_huantao/iter_100.pth`, and `work_dirs/`
contains only B0 runs. That checkpoint is 44 MB, which is a B0 model carried with optimizer
state; a B2 checkpoint holds roughly seven times the parameters and would be far larger.

The timing is therefore not explained by model capacity, and the earlier inference of "B2 or
larger" from the timing profile was wrong. The config runs `test_cfg=dict(mode='whole')` at
`img_scale=(1024, 512)` over a 1296×972 TIFF, under CPU PyTorch through mmsegmentation, paying a
cold process start every cycle. Input resolution and framework overhead account for the gap, which
is why pre-resizing is Strategy 1 below.

One residual uncertainty: this is the repository default, and the checkpoint actually sitting in
`/home/pi/segformer_5band/` on a deployed node has not been inspected. If a node is reachable,
confirm there.

---

## Bottleneck Analysis

### 1. Cold Process Start (10–20 s per cycle)

Every invocation of `segment_tiff_5band.py` pays the full cost of:
- Python interpreter startup
- Conda environment activation and import resolution
- PyTorch initialization (~3–5 s on ARM)
- Model checkpoint loading from microSD (~5–10 s for B2: 84 MB on-disk)
- GPU/CPU device setup

This overhead is fixed regardless of image size or model variant.

### 2. Unoptimized PyTorch Inference (~90–150 s)

PyTorch on ARM Cortex-A72 (Pi 4B):
- No JIT compilation by default
- Operations execute sequentially through PyTorch's Python dispatcher
- Memory layout (NCHW) is not optimal for ARM NEON SIMD
- Float32 throughout — no half-precision or integer acceleration

### 3. Oversized Input Resolution (1296×972)

SegFormer's MiT encoder uses overlapping patch embeddings on the input.
Processing 1296×972 pixels creates a feature map ~4× larger than the
512×512 resolution the model was likely trained on. The excess resolution
does not improve accuracy but multiplies compute proportionally.

### 4. Subprocess Communication Overhead

The orchestration layer and the inference script share no state — they
communicate only via files on microSD. Each cycle writes a TIFF (~15–25 MB
uncompressed for 5-band 1296×972), which is read back immediately by the
inference script. The SD card I/O adds latency and wear.

---

## Optimization Strategies

### Strategy 1: ONNX Export + ONNX Runtime (Highest Impact, No Hardware Change)

**Expected speedup: 2–4× over PyTorch baseline**
**Expected inference time: 40–75 s (B2) or 8–20 s (B0)**

ONNX Runtime for ARM64 uses ahead-of-time graph optimization and
platform-specific kernel selection (MLAS on ARM, which uses NEON intrinsics
directly). Unlike PyTorch, it does not incur Python dispatch overhead per
operator.

#### Export the model (run once on any machine with PyTorch):

```python
import torch
from transformers import SegformerForSemanticSegmentation

model = SegformerForSemanticSegmentation.from_pretrained(
    "/home/pi/segformer_5band/checkpoint"
)
model.eval()

# Match the 5-band input: batch=1, channels=5, H=512, W=512 (inference resolution)
dummy = torch.randn(1, 5, 512, 512)

torch.onnx.export(
    model,
    dummy,
    "segformer_5band.onnx",
    input_names=["pixel_values"],
    output_names=["logits"],
    dynamic_axes={
        "pixel_values": {0: "batch", 2: "height", 3: "width"},
        "logits": {0: "batch", 2: "height", 3: "width"},
    },
    opset_version=17,
)
```

#### Run inference with ONNX Runtime on the Pi:

```bash
pip install onnxruntime  # arm64 wheel available from PyPI
```

```python
import onnxruntime as ort
import numpy as np
import rasterio
from PIL import Image

sess_opts = ort.SessionOptions()
sess_opts.intra_op_num_threads = 4  # use all Pi 4B cores
sess_opts.execution_mode = ort.ExecutionMode.ORT_SEQUENTIAL
sess_opts.graph_optimization_level = ort.GraphOptimizationLevel.ORT_ENABLE_ALL

session = ort.InferenceSession(
    "segformer_5band.onnx",
    sess_options=sess_opts,
    providers=["CPUExecutionProvider"],
)

with rasterio.open("color_preserved_5_band.tiff") as src:
    img = src.read().astype(np.float32)  # (5, H, W)

# Resize to training resolution before inference
from torchvision.transforms.functional import resize
import torch
img_t = torch.from_numpy(img)
img_t = resize(img_t, [512, 512])  # antialias resize outside the model

# Normalize per-band to [0, 1]
for i in range(5):
    img_t[i] = (img_t[i] - img_t[i].min()) / (img_t[i].max() - img_t[i].min() + 1e-8)

input_array = img_t.unsqueeze(0).numpy()  # (1, 5, 512, 512)
logits = session.run(["logits"], {"pixel_values": input_array})[0]

pred = np.argmax(logits[0], axis=0).astype(np.uint8)
Image.fromarray(pred).save("color_preserved_5_band_segmentation.png")
```

---

### Strategy 2: INT8 Static Quantization (Multiplies ONNX Gains)

**Expected additional speedup over ONNX FP32: 2–3×**
**Expected total inference time from baseline: 15–30 s (B2), 4–8 s (B0)**

ONNX Runtime's quantization tool converts FP32 weights and activations to
INT8. ARM Cortex-A72 supports 8-bit SIMD natively; this maps directly to
vectorized NEON operations that run ~3× faster than FP32 NEON.

Static quantization requires a small calibration dataset (~50–100 images
representative of deployment scenes — flood vs. dry land images).

```bash
pip install onnxruntime onnx
python -m onnxruntime.quantization.preprocess --input segformer_5band.onnx --output segformer_5band_prep.onnx
```

```python
from onnxruntime.quantization import quantize_static, CalibrationDataReader, QuantType
import numpy as np

class WaterCamCalibrationReader(CalibrationDataReader):
    def __init__(self, calibration_tiffs):
        self.images = calibration_tiffs
        self.idx = 0

    def get_next(self):
        if self.idx >= len(self.images):
            return None
        img = load_and_preprocess(self.images[self.idx])  # same logic as inference
        self.idx += 1
        return {"pixel_values": img}

quantize_static(
    model_input="segformer_5band_prep.onnx",
    model_output="segformer_5band_int8.onnx",
    calibration_data_reader=WaterCamCalibrationReader(calibration_tiffs),
    quant_type=QuantType.QInt8,
    per_channel=True,
)
```

**Accuracy note**: INT8 quantization typically reduces mIoU by 0.5–2% on
well-calibrated data. For flood segmentation with clear class boundaries
(water vs. land), this degradation is acceptable. Validate on held-out
captures before deploying.

---

### Strategy 3: Model Variant Reduction

**SegFormer variant comparison on ARM (estimated with ONNX FP32):**

| Variant | Parameters | FLOPs (512×512) | Est. Pi 4B ONNX FP32 | Est. Pi 4B ONNX INT8 |
|---|---|---|---|---|
| B5 | 82M | 79.6G | ~90–120 s | ~30–40 s |
| B2 | 25M | 62.4G | ~40–60 s | ~15–25 s |
| B1 | 14M | 15.9G | ~20–30 s | ~8–12 s |
| **B0** | **3.7M** | **8.4G** | **~10–18 s** | **~4–7 s** |

FLOPs are from the original SegFormer paper (Xie et al. 2021). Pi 4B
estimates are extrapolated from Cortex-A72 GFLOPS benchmarks.

If the deployment model is currently B2 or B5, **retraining with B0** is
the single highest-impact change for inference speed. B0's MiT-B0 encoder
uses 4 transformer stages with [32, 64, 160, 256] channel widths vs B2's
[64, 128, 320, 512], reducing both parameter count and memory bandwidth.

For a 5-class flood segmentation problem (e.g., water/dry_land/vegetation/
infrastructure/shadow), B0 is likely sufficient — the task does not require
ImageNet-scale feature diversity.

---

### Strategy 4: Persistent Inference Daemon (Eliminates Cold-Start Cost)

**Expected savings: 10–20 s per cycle (fixed overhead elimination)**

Instead of spawning a new Python process each wake cycle, run SegFormer as
a long-lived daemon that accepts inference requests via a Unix domain socket
or a named pipe. The model stays loaded in RAM for the duration of the Pi's
active window.

#### Daemon implementation sketch:

```python
# /home/pi/segformer_5band/segformer_daemon.py
import socket, os, sys, json
import numpy as np
import onnxruntime as ort

MODEL_PATH = "/home/pi/segformer_5band/segformer_5band_int8.onnx"
SOCKET_PATH = "/tmp/segformer.sock"

session = ort.InferenceSession(MODEL_PATH, providers=["CPUExecutionProvider"])
print("Model loaded, ready", flush=True)

if os.path.exists(SOCKET_PATH):
    os.unlink(SOCKET_PATH)

server = socket.socket(socket.AF_UNIX, socket.SOCK_STREAM)
server.bind(SOCKET_PATH)
server.listen(1)

while True:
    conn, _ = server.accept()
    data = b""
    while chunk := conn.recv(4096):
        data += chunk
    req = json.loads(data.decode())

    tiff_path = req["tiff_path"]
    output_path = req["output_path"]

    # run inference (load → infer → save)
    result = run_inference(session, tiff_path)
    save_result(result, output_path)

    conn.sendall(b"done")
    conn.close()
```

```python
# In ticktalk_main.py — replace subprocess.Popen with:
import socket, json

def call_segformer_daemon(tiff_path, output_path):
    req = json.dumps({"tiff_path": tiff_path, "output_path": output_path})
    with socket.socket(socket.AF_UNIX, socket.SOCK_STREAM) as s:
        s.connect("/tmp/segformer.sock")
        s.sendall(req.encode())
        s.shutdown(socket.SHUT_WR)
        s.recv(64)  # wait for "done"
```

The daemon is started once by the systemd service (`ticktalk.service`) and
stays alive for the entire wake window. With 3 iterations per wake
(`shutdown_iteration_limit=3`), this saves ~30–60 s per wake event.

---

### Strategy 5: Pre-resize Before the TIFF Write

**Withdrawn 2026-09-26. Do not implement as written.**

> Resizing the capture to a square 512×512 destroys the 4:3 aspect ratio, and the mask is
> georeferenced downstream from IMU pose, so a distorted mask distorts the georeferencing —
> silently, since every intermediate still has the shape it should. The deployed graph is now
> exported with **dynamic height and width**, and `tools/segformer_daemon.py` rescales the capture
> keeping its aspect ratio (972×1296 → 512×683), pads to a multiple of 32, runs, then crops the
> padding back off and resizes the logits to source resolution. That gets the inference-resolution
> saving this strategy was after without squaring the frame.
>
> The file-size half of the argument also no longer applies to anything live: it proposed resizing
> `final_5_band.tiff`, which is legacy output nothing reads. `color_preserved_5_band.tiff` stays at
> native resolution deliberately — it is what the annotator draws masks on.
>
> Retained below as written, for the record.

**Original text — expected savings: 20–40% of inference time (input resolution reduction)**

The co-registration pipeline writes a 1296×972 TIFF but SegFormer inference
should operate at 512×512 or 640×640. Moving the resize to before the TIFF
write avoids the model internally upsampling patch embeddings from an
oversized input.

In `tools/coreg_multiple.py`, `save_color_preserved_tiff()` (line 466):

```python
# Current: writes at full co-registration resolution (~1296×972)
# Add resize before stacking bands:

TARGET_H, TARGET_W = 512, 512

def save_color_preserved_tiff(output_path, rgb, thermal, nir):
    # resize each band to inference resolution
    rgb_r    = cv2.resize(rgb,     (TARGET_W, TARGET_H), interpolation=cv2.INTER_AREA)
    thermal_r = cv2.resize(thermal, (TARGET_W, TARGET_H), interpolation=cv2.INTER_AREA)
    nir_r    = cv2.resize(nir,     (TARGET_W, TARGET_H), interpolation=cv2.INTER_AREA)
    # ... rest of band stacking unchanged
```

This also reduces the TIFF file size from ~15–20 MB to ~1.5–2 MB, cutting
microSD write time by ~10× and reducing the file read time inside the
inference script.

Note: keep the original-resolution `color_preserved_5_band.tiff` and
`registered.jpg` for archival if needed; only resize `final_5_band.tiff`.

---
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

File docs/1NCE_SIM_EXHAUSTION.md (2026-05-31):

# 1NCE SIM Data Exhaustion — Diagnosis & Fixes

1NCE SIMs have a **500 MB lifetime data cap**. Once exhausted the modem shows good
signal and correct APN but the network rejects PDP context attachment — see
`quectel-1nce-debugging.md` for the modem-level symptoms.

This document covers why the 500 MB cap is being consumed faster than expected
across multiple deployed units.

---
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

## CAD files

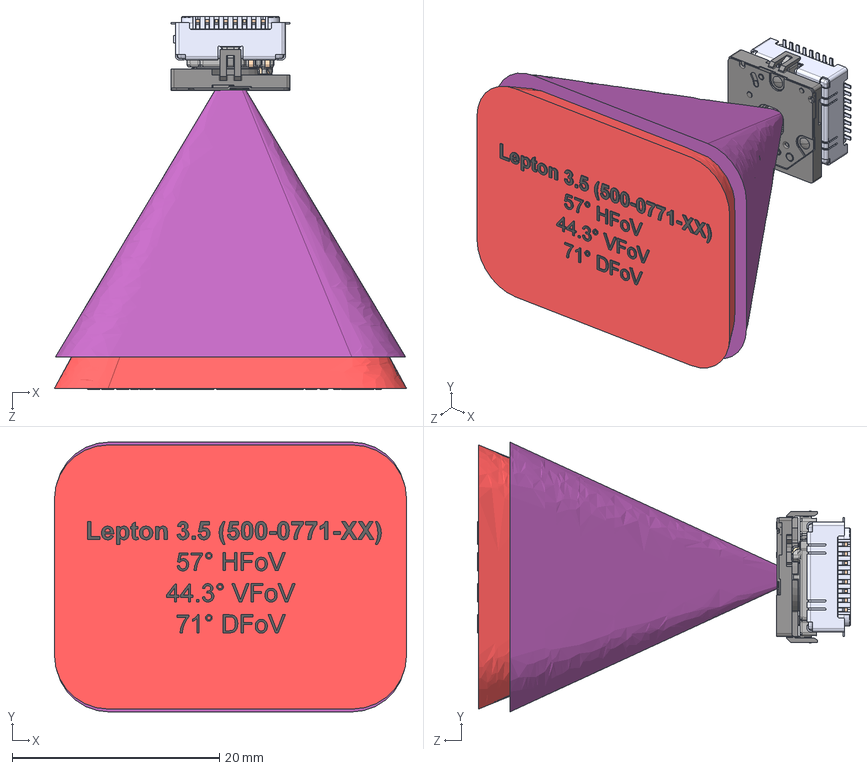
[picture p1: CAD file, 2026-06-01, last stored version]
Reference Models/Lepton 3.5, Socket 1050282031, 57 Deg HFOV 9 Hz Export.STEP
34.0 x 26.1 x 36.0 mm
Lepton Base, Export_Export
Assy, Housing, 160x120 Lens, Lepton 3.0 Export
Emissive Shutter, Lepton, Export
Lepton 3.5 Optical Area
Molex Camera Socket 8.5x8.5 Side Contact Through Board 1050282031 Export

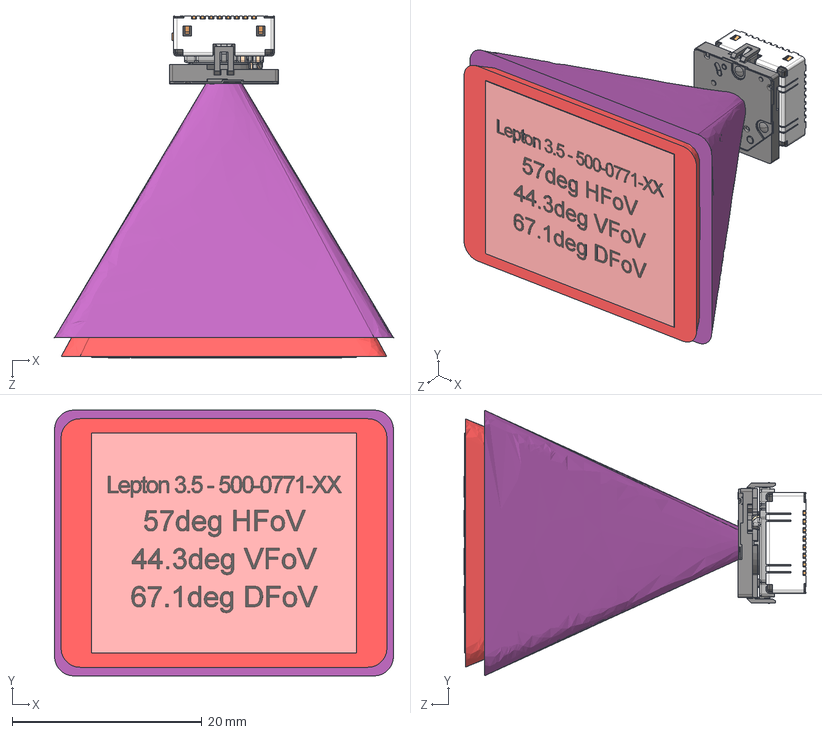
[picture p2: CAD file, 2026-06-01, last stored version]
Reference Models/Lepton 3.5, Socket 10502821001, 57 Deg HFOV 9 Hz Export.STEP
35.7 x 28.0 x 36.0 mm
Lepton Base, Export
Assy, Housing, 160x120 Lens, Lepton 3.0 Export
Molex Camera Socket 8.5x8.5 Side Contact 1050281001 Export
Emissive Shutter, Lepton, Export
Optical Area 57deg HFoV, Lepton 3.5

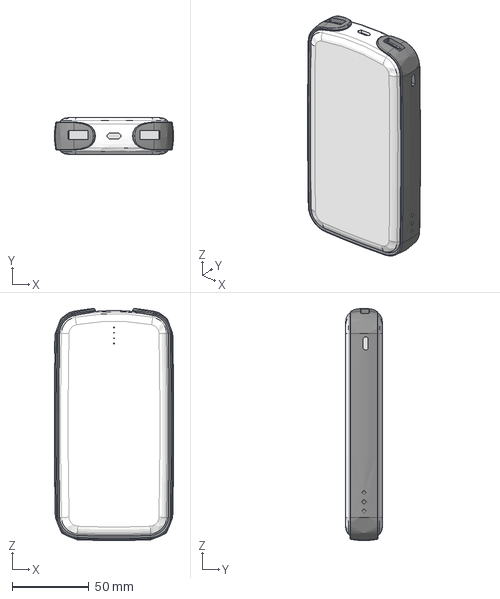
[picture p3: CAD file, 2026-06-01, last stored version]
Reference Models/Volaic_V75_3D.stp
77.9 x 24.0 x 151.6 mm

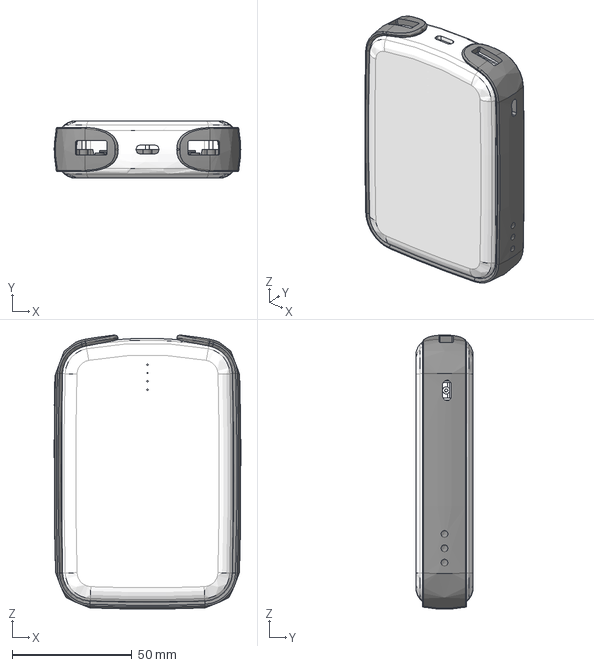
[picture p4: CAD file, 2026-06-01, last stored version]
Reference Models/Voltaic_V50_3D.stp
77.9 x 24.0 x 114.4 mm

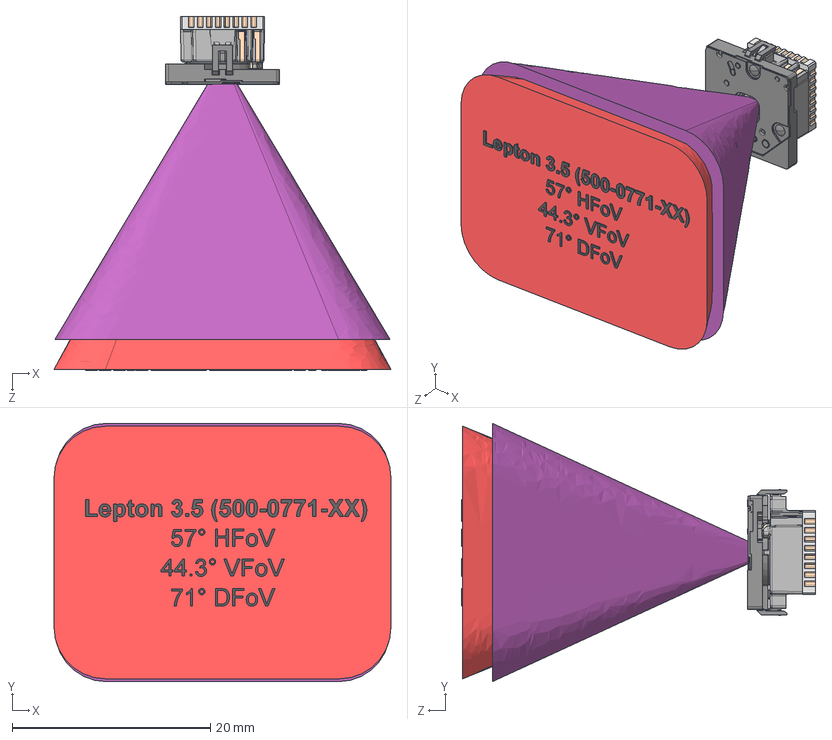
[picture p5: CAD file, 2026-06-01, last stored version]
Reference Models/Lepton 3.5, No Socket, 57 Deg HFOV 9 Hz Export.STEP
34.0 x 26.1 x 35.7 mm
Lepton Base, Export_Export
Assy, Housing, 160x120 Lens, Lepton 3.0 Export
Emissive Shutter, Lepton, Export
Lepton 3.5 Optical Area

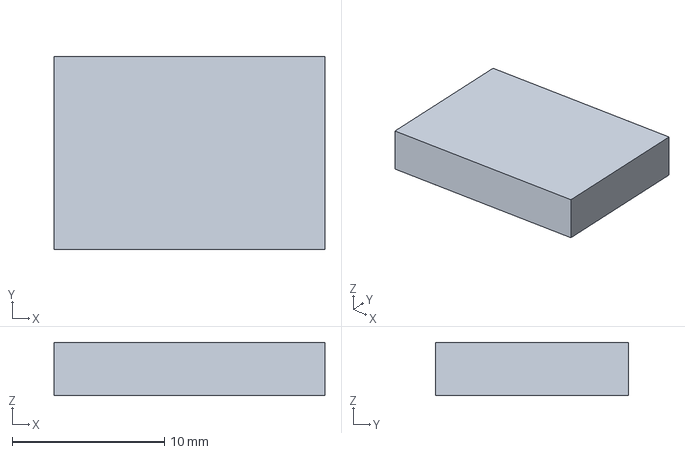
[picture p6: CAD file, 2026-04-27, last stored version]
Reference Models/Adafruit_AHT20_4566_OUTLINE.step
17.8 x 12.7 x 3.50 mm

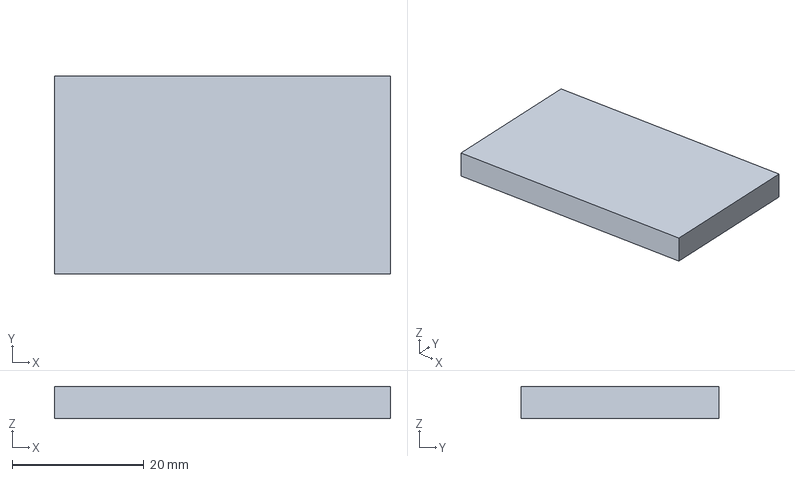
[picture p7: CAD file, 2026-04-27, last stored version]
Reference Models/Quectel_EC25_miniPCIe_OUTLINE.step
51.0 x 30.0 x 4.90 mm

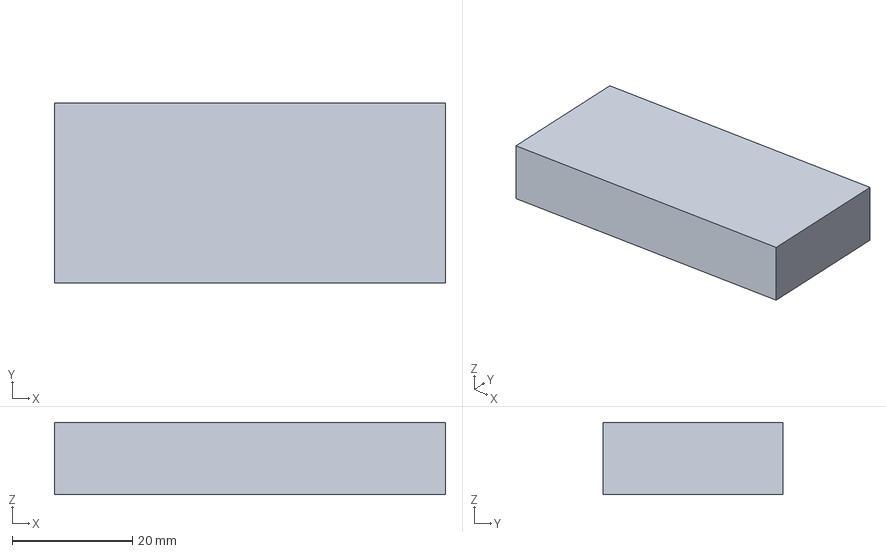
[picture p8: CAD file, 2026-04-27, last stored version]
Reference Models/WittyPi_4.step
65.0 x 30.0 x 12.0 mm

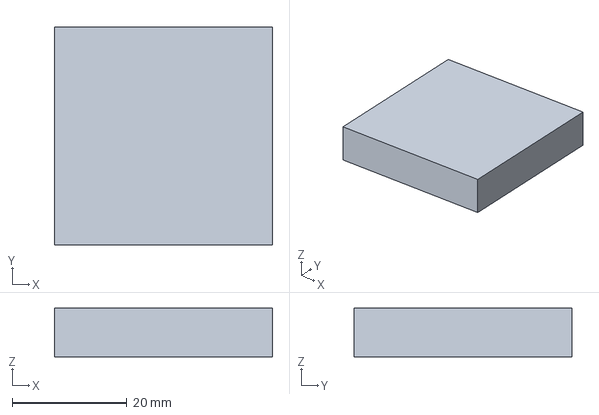
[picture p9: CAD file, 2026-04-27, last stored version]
Reference Models/FLIR_Lepton_Breakout_v2_OUTLINE.step
38.0 x 38.0 x 8.50 mm

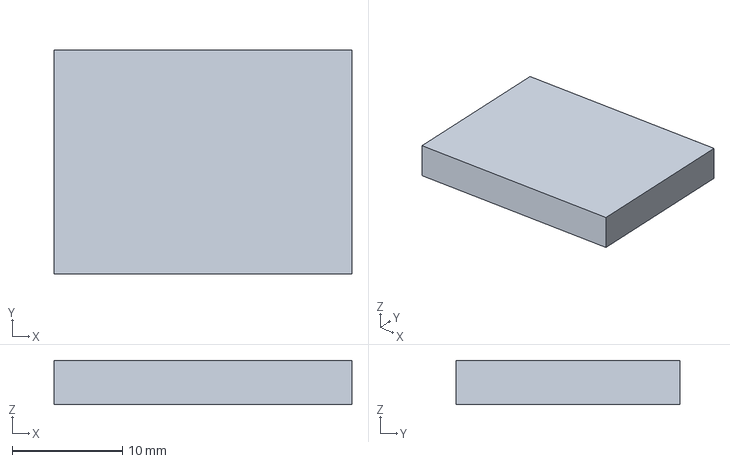
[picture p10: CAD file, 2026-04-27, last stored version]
Reference Models/Adafruit_BNO055_2472_OUTLINE.step
27.0 x 20.3 x 4.00 mm

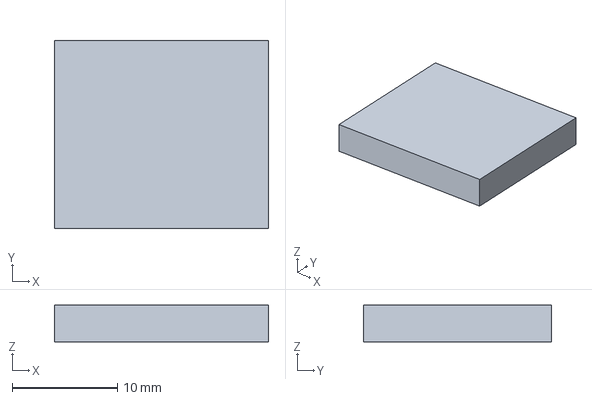
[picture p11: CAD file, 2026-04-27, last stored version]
Reference Models/Adafruit_BNO085_4754_OUTLINE.step
20.3 x 17.8 x 3.50 mm

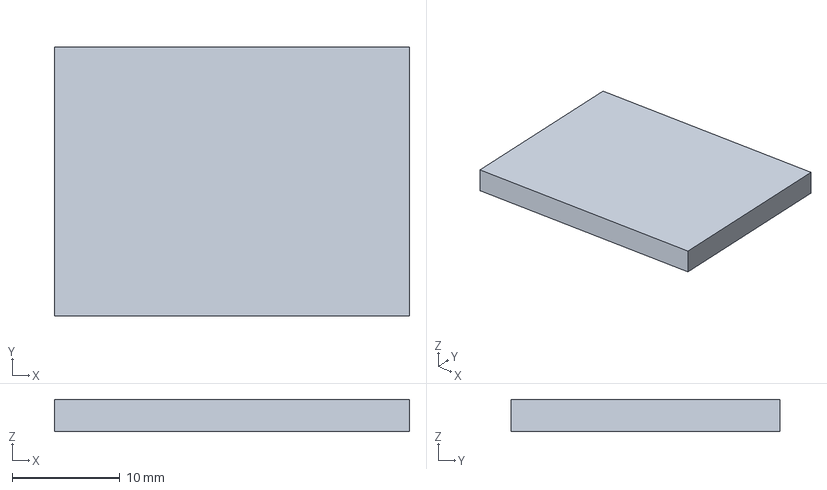
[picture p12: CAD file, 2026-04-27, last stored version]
Reference Models/Multitech_mDot_915_OUTLINE.step
33.0 x 25.0 x 3.00 mm

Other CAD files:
Reference Models/Raspberry Pi 4 Model B.stl

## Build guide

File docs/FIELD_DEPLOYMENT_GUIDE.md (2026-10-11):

# Field Deployment Guide: Configuring and Installing an Assembled WaterCam Unit

**Audience:** Written assuming you have an assembled unit and flashed the SD card image (https://drive.google.com/file/d/1dCcisGiLYk8vYh0eK_8w945sLaqX_JKo/view?usp=sharing) but need to set up remote access, the WittyPi schdedule, and the auto-start functionality. 

**Scope:** This guide starts where the hardware build guide (`README.md`) ends, it assumes you have a fully assembled unit (all components installed, case ready to be sealed).

If any hardware step (soldering, wiring, case prep) hasn't been done yet, stop and follow `README.md` first.

---

## Overview:

1. **Bench configuration** — do this before you leave, while the unit still has network access and you can fix issues.
2. **Field installation** — physical attachment, and on-site verification that everything survived the trip and is working from its final position.

---

## Phase 1: Bench Configuration Checklist

### 1.1 Connect to the unit

Use a USB UART serial adapter (https://www.adafruit.com/product/954) to connect to the Raspberry Pi after you've inserted the flashed SD card into the Raspberry Pi. The white wire connects to pin 8, green to pin 10, and you can connect the black wire to any free ground pin on the Raspberry Pi, like pin 14.

****Make sure the red wire is NOT connected to the Pi****

You will need software on your computer to connect to the Raspberry Pi over the serial link. On a Linux system I would recommend tio. On Windows: (https://learn.adafruit.com/windows-tools-for-the-electrical-engineer/serial-terminal)

Once you've connected the serial adapter, started your connection software with it set to the correct port for the serial adapter, and turned the Raspberry Pi on by tapping the button on the WittyPi you should see some text eventually. It will take time for the system to complete its first boot, and it should reboot automatically after it expands the filesystem to the size of the SD card. If you do not see text in your software, try hitting Enter to see if you get a response. If nothing appears double check how the serial adapter is connected.

If you get the expected login prompt you can log into the system with the standard username pi and password. You will not see the password as you type it, just type it out and hit Enter. If you are at SU campus the system should automatically connect to AirOrangeX and display its IP address (v4 and v6), at which point you can switch to using SSH to connect to the Raspberry Pi, or continue using the serial adapter.

If you want to connect to a different WiFi network you can use 'sudo nmtui' to set up the connection. (https://www.howtogeek.com/devops/how-to-manage-linux-wi-fi-networks-with-nmtui/)

If you need to edit a text file you can use `nano filename.txt`

You can check that the camera is in focus by capturing a photo with `rpicam-still --output test.jpg` and viewing the photo by copying it to your system once SSH is setup or by shutting down the Raspberry Pi and copying the file from the SD card. 

### 1.2 Set a unique hostname

```bash
sudo hostnamectl set-hostname <site-name>
```

Use a name that either identifies the deployment location or the unit number.

After changing it, confirm `/etc/hosts` was updated — the `127.0.0.1` line must match the new hostname, not the base SD image's original name:

```bash
cat /etc/hosts
```

If it does not match, use `sudoedit /etc/hosts` to change it. Log out and back in to check the changes applied.

Every unit flashed from the same SD image starts with the same machine ID and
network keys. Give this unit its own, then reboot:

```bash
sudo rm /etc/machine-id && sudo systemd-machine-id-setup
sudo rm -f /var/lib/NetworkManager/secret_key /var/lib/dhcpcd/duid
sudo reboot
```

systemd, journald and NetworkManager all treat the machine ID as unique, and
the NetworkManager key sets the unit's IPv6 address, so two clones on the same
network would otherwise share it. Check with `cat /etc/machine-id` that it no
longer matches another unit's.

When making a new SD image, empty the machine ID and delete those two files
before capturing it, so each unit generates its own on first boot:

```bash
sudo truncate -s 0 /etc/machine-id
sudo rm -f /var/lib/NetworkManager/secret_key /var/lib/dhcpcd/duid
```

### 1.3 Confirm remote access (Tailscale)

Run the command provided by Tailscale to install

If there is an issue with the script check (https://console.tailscale.com/admin/machines/new-linux)

```bash
tailscale up --ssh
```

This will allow logging into the system using SSH now and when the unit is in the field connected via cellular modem.

### 1.4 Sync the clock

This should have been done automatically, but check the system time is correct.

```bash
sudo /home/pi/wittypi/syncTime.sh
```

How the unit keeps time (NTP is off; `timedatectl` reports "not synchronized", which is expected):

1. **At boot,** the Witty Pi daemon copies its RTC into the system clock, or
   the other way round if the RTC's time looks bad.
2. **About 30 s later,** `beforeScript.sh` runs `syncTime.sh`. It reads the
   `Date:` header of an HTTP request to `http://google.com`, accurate to about
   1 s, and writes it to the system clock and the RTC. That needs internet at
   boot: WiFi, or cellular if the modem autoconnects. A unit whose modem is kept
   off until needed has no internet at boot without WiFi.
3. **Without internet,** `syncTime.sh` takes the time from GPS instead (gpsd,
   through `gps_time.py`), waiting up to 90 s for a fix. The GPS is the
   modem's, and works with its data connection down. With neither, the clock
   and RTC are left alone.
4. **The RTC holds local time.** After a daylight-saving change, the first boot
   runs an hour off until step 2 or 3 corrects it. A unit with neither internet
   nor a GPS fix isn't corrected for the change or for drift, so check its
   clock at each visit.

Install this repo's time sync into the Witty Pi folder (the stock `syncTime.sh`
has no GPS fallback):

```bash
cp /home/pi/SU-WaterCam/config/wittypi/syncTime.sh /home/pi/SU-WaterCam/config/wittypi/gps_time.py /home/pi/wittypi/
```

### 1.5 Configure `runtime_config.json`

This is the unit's operating settings. The file `/home/pi/SU-WaterCam/runtime_config.json` should be edited to have the name of the specific unit and other settings.

```bash
nano /home/pi/SU-WaterCam/runtime_config.json
```

The required change is to set a unique name. The system hostname or something derived from it would make sense.

```json
"ip_upload": {
  "device_id": "watercam-007",
  ...
}
```

The other top-level fields control monitoring behavior. From
`tools/lora_runtime_integration.py`'s parameter definitions:

| Field | Units | Range | Meaning |
| --- | --- | --- | --- |
| `area_threshold` | % | 0–100 | Flood-extent area (as % of frame) that triggers elevated/emergency reporting |
| `stage_threshold` | cm | 0–65535 | Water stage (level) threshold |
| `monitoring_frequency` | minutes | 1–10080 | How often the unit checks/reports under normal conditions |
| `emergency_frequency` | minutes | 1–1440  | How often it reports once a threshold is exceeded (should be shorter than `monitoring_frequency`) |
| `photo_interval` | seconds | 30–1440 | Time between captures while the unit is awake (default 60); applied to the running program |
| `neighborhood_emergency_frequency` | minutes | 1–1440  | Reporting frequency once a *neighboring* unit signals emergency |

Also confirm before deploying:

- `emergency_mode: false` and `debug_mode: false` — both should be off for a normal deployment
- `ip_upload.enabled` — `true` if this site will use cellular/IP upload in addition to (or instead of) LoRa; if so, fill in `server_url` for the WaterCam API server this unit reports to (already set for our tailnet), and `api_key` with this unit's own token: on the dashboard, Management → select the unit → IP access token → Generate, then copy it here. The token is shown once. Once the server enforces tokens (`IP_AUTH=enforce`), a unit without one can't send over IP.
- **LoRa sensor packet:** each capture sends the capture time plus only the fields
  that changed by 5% or more since they were last sent (`data/lora_last_sent.json`).
  Orientation (the IMU's heading, roll, pitch) uses an absolute threshold instead,
  `lora_imu_threshold_deg` (default 2°), allowing for the heading wrapping at 360°.
  Every `lora_full_send_hours` (default 24) all fields go out, since LoRa uplinks are
  unconfirmed and a lost packet would otherwise leave an old value on the server.
  `always_transmit_sensors: true` sends every field every capture.
- **Transport order** (on by default): LoRa first, then WiFi, then cellular only if
  neither works. The modem is only kept off until needed once it is set up as in
  1.5.1 below.

### 1.5.1 Keep the cellular modem off unless LoRa and WiFi fail

The SIM's data is limited (500 MB for its lifetime), and a wake that uses cellular
costs 126–474 KB, almost all of it Tailscale overhead
([CELLULAR_DATA.md](CELLULAR_DATA.md)). So the modem's data connection should stay
down and only come up when the reading can't be sent any other way. The software
already does this ([IP_TRANSMISSION.md](IP_TRANSMISSION.md#transport-order-lora-wifi-cellular)),
but **only for a connection whose autoconnect is off**. Out of the box, `Quectel`
autoconnects and cellular is up on every wake.

Enable it on the unit (run from `/home/pi/SU-WaterCam`):

```bash
sudo nmcli connection modify Quectel connection.autoconnect no
sudo install -m 644 config/polkit/50-watercam-networkmanager.rules /etc/polkit-1/rules.d/
nmcli connection down Quectel      # takes effect now rather than at the next boot
```

The polkit rule lets `pi` (which runs ticktalk with no login session) bring the
connection up and down. Changing the connection's settings still needs `sudo`.

Check it, as `pi` and without `sudo`:

```bash
nmcli -g connection.autoconnect connection show Quectel    # prints: no
nmcli connection up Quectel && nmcli connection down Quectel   # both succeed
ip route | grep default                                     # no wwan0 route once it's down
```

If `nmcli connection up` says "Insufficient privileges", the polkit rule is missing.
The modem stays registered on the network while its data connection is down. That
costs no measurable power and keeps GPS working.

**What else changes with the modem off.** Anything that needed internet at boot
or at the start of a wake now only has it over WiFi, or later in a wake once
cellular is brought up for an upload:

- **Clock:** the boot-time network time sync (1.4) fails without WiFi. Install
  this repo's `syncTime.sh` and `gps_time.py`, so the clock is set from GPS
  instead (#130).
- **Commands sent over IP** (the dashboard's IP downlink) are normally collected
  at the start of a wake, which skips cellular. On a unit with only cellular,
  they arrive after that wake's upload. On a unit whose LoRa is joined, IP isn't
  used at all, so commands must go by LoRa.
- **The IP upload backlog** is only sent when WiFi or cellular is used.
- **Over-the-air model updates** (planned) also need an IP link: WiFi, or a wake
  that used cellular.
- **GPS is unaffected:** the modem stays registered and its GNSS keeps working.

**Remote access:** with this on, the unit is only reachable over cellular
(Tailscale) during a wake in which LoRa and WiFi both failed. Set it up while you
can still reach the unit another way. Don't turn it on remotely for a unit whose only link is
cellular unless you accept that. To undo it:
`sudo nmcli connection modify Quectel connection.autoconnect yes`.

### 1.6 LoRa registration

This can be tricky. 

If the mDot has already been flashed with our custom firmware (https://github.com/WaterCam-Team/mDot-AT-firmware) then you can proceed to connecting to a gateway after the mDot ID is registered with ChirpStack. If the firmware has not been flashed, follow the instructions in the firmware GitHub. If it has programming headers installed the easy way is to use the USB development board (https://multitech.com/product/multitech-mdot-micro-developer-kit-global/). If not, the same USB serial adapter used for the Raspberry Pi can be used to flash the firmware following the instructions in the repository.

The mDot module's DevEUI must already be registered in ChirpStack before the unit can join the network. **This should be done ahead of time by the ChirpStack administrator**, confirm with them that this specific unit's DevEUI is registered and assigned to the correct application/device profile. The DevEUI is unique per mDot module (see `tools/AT_COMMANDS_REFERENCE.md` for querying the module over serial if you need to look it up).

Once it's confirmed that the device is running our firmware and it is set up in ChirpStack, you can connect to the gateway following the instructions in https://docs.google.com/document/d/1Z83h89x7jlwzRIvbZtyiRxBoMupdoHzL/edit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

I'd recommend using SSH at this point to connect to the Raspberry Pi instead of serial. On the Raspberry Pi run `tio /dev/ttyAMA5` to issue the commands to connect to the gateway when you know it is in range.

### 1.7 IMU Stage 1 calibration

**Has to be done before the unit is installed outside**

```bash
python tools/bno055_calibration.py --unit-config <unit_config_file>.json --mode calibrate
```

Verify `bno055_calibration.json` shows `"mag": 3` when done. Without it heading data will be unreliable and georeferencing will be difficult.

### 1.8 Confirm camera calibration exists

Calibration for our set of hardware is done and the file should transfer from unit to unit as long as hardware does not change. I forgot to copy it to the SD card image, so download from (https://drive.google.com/file/d/1Lpb0LEcR_ePSkGa5xrXXbkxigSQw4oQi/view?usp=drive_link) and copy it to `config/camera_calibration.json` in the SU-WaterCam directory using scp or an SD card reader.

```bash
ls config/camera_calibration.json
```

If missing, this file should be copied over or it needs to be redone before deployment (using the 25x18-square, 30mm calib.io checkerboard) use `tools/camera_calibration.py`

### 1.9 Enable the production service

The application is run via `ticktalk.service`

```bash
sudo cp config/lora_daemon.service config/segformer_daemon.service \
        config/ticktalk.service config/wittypi-recovery.service config/wittypi-boot-mark.service \
        /etc/systemd/system/
sudo systemctl daemon-reload
sudo systemctl disable watercam.service 2>/dev/null   # if it was ever enabled
sudo systemctl enable --now lora_daemon.service segformer_daemon.service
sudo systemctl enable ticktalk.service wittypi-recovery.service wittypi-boot-mark.service
```

`ticktalk` and the WittyPi services start on the next boot.

`lora_daemon.service` owns the mDot serial port, and every LoRa send or
receive in `ticktalk` goes through it. Without it the unit has no LoRa.
`segformer_daemon.service` keeps the flood-segmentation model loaded. Without
it `ticktalk` falls back to loading the model on every cycle, about 40 s
instead of about 2 s. Both start before `ticktalk.service`; `--now` also starts
them straight away for the test cycle in 1.11.

`wittypi-recovery.service` handles recovery after a power outage. Leave the
WittyPi on "Default ON", so it boots the Pi whenever power returns. When a
boot comes from power returning rather than from the schedule, the service
arms the next `schedule.wpi` slot at least 2 hours away and shuts down before
the cameras and modem start, giving the battery time to recharge. Settings are
under `recovery_boot` in `runtime_config.json`.

This also applies when you first connect power, so a freshly connected unit
goes straight back to sleep. **Press the WittyPi button** to start a normal
cycle on the bench or at deployment. On the bench you can also set
`"recovery_boot": {"enabled": false}`.

Optionally, install the power logger. It writes one line a minute to
`~/powerlog/powerlog.csv`, synced to disk so the last reading before a
brownout survives, with a marker line for every boot. When a unit fails in
the field, this log shows when the power dropped and how each boot started.
`tools/power_test_report.py ~/powerlog/powerlog.csv` summarises it.

```bash
sudo cp config/powerlog.service /etc/systemd/system/
sudo systemctl daemon-reload
sudo systemctl enable --now powerlog.service
```

Keep the systemd journal in RAM to spare the microSD card. Logs then last
until the next shutdown or power cut; the power log above is the record that
survives one.

```bash
sudo mkdir -p /etc/systemd/journald.conf.d
sudo cp config/journald-volatile.conf /etc/systemd/journald.conf.d/
sudo systemctl restart systemd-journald
```

### 1.10 Run the startup health check

`tools/initial_health_check.py` checks CPU temperature, WittyPi voltages, GPS fix, and IMU availability in one shot, and sends a LoRa alert on failure.

```bash
cd /home/pi/SU-WaterCam
venv/bin/python tools/initial_health_check.py --no-alert; echo "exit code: $?"
```

It prints `Health check: OK` or `FAIL` with each reason, then every reading.
Without `--no-alert`, a failure also queues a LoRa alert.

Exit code `0` means everything passed. If it fails, read the printed failure reasons (`gps_unavailable`, `imu_unavailable`, `wittypi_input_voltage_low_*V`,
etc.) and resolve them before moving on. GPS will very likely fail indoors, re-check it outdoors in Phase 2.

### 1.11 Test a full capture-and-transmit cycle

```bash
sudo systemctl start ticktalk.service
journalctl -u ticktalk.service -f
```

Watch the log for a completed photo capture and a successful LoRa/IP
transmission. Then confirm the reading actually arrived — check the WaterCam dashboard for this device's `device_id` and confirm a fresh
reading shows up. Stop the service again if you still need to seal the case as the service will shutdown the Raspberry Pi once it has finished capturing data:

```bash
sudo systemctl stop ticktalk.service
```

### 1.12 Weatherproofing

Once everything above passes, follow `README.md`'s sealing steps (silicone sealant on case openings, LWIR window installation for the Lepton, water resistance check) before transporting the unit.

### 1.13 Set the power schedule (WittyPi)

The WittyPi controls when the Pi is powered on/off and needs to be told what schedule to use. For a normal deployment use this repo's daylight schedule. It wakes for up to 15 min every 2 h while the camera can see: 08:00–16:00 EST, which is 09:00–17:00 during daylight saving, since the Witty Pi counts seconds from `BEGIN`.

```bash
cp /home/pi/SU-WaterCam/config/wittypi/watercam_daylight_2h.wpi /home/pi/wittypi/schedule.wpi
```

It was checked against sunrise and sunset for Syracuse (43° N) all year. At a site far from that latitude, check the first and last wake times. Don't run `runScript.sh` on the bench, because it arms the schedule and the unit then shuts down at the end of the window. The daemon arms it at the next boot, which is when you press the button at deployment.

If you want to use one of the default schedules run `./wittypi/wittyPi.sh`

If you need to customize the schedule you can write a `.wpi` file for this deployment: (https://github.com/uugear/Witty-Pi-4/tree/main/Software/wittypi/schedules)

Then install this repo's `beforeScript.sh`, which lets the WittyPi arm the next wake about 15 s after boot instead of about 55 s:

```bash
cp /home/pi/SU-WaterCam/config/wittypi/beforeScript.sh /home/pi/wittypi/beforeScript.sh
```

## Phase 2: Field Installation

### 2.1 Site selection

- Camera has a clear, unobstructed view of the area to monitor.
- Solar panel has clear southern exposure (or whatever maximizes light at the install location) with minimal shading across the day.
- Mount is **rigid** — the pole must not sway or rotate
- Within range of a LoRa gateway or cellular coverage, as applicable to this unit's transport configuration.

### 2.2 Mount and record physical measurements

Once mounted, **record these values on-site** 

- **Mount height** above the surface.
- **Approximate compass heading** the camera faces (a phone compass reading is fine as a sanity check — the IMU calibration below gets the precise value).
- Pole material and any known magnetic interference sources nearby.
- GPS coordinates of the installation taken with RTK hardware
- RTK ground control points in the camera's field of view

This is needed for the georeferencing process

### 2.3 Power on and verify

```bash
ssh <hostname>   # via Tailscale, once it reconnects
```

Check that the monitoring software is running with `journalctl -u ticktalk.service -f`

GPS acquiring a fix outdoors from a cold start can take a few minutes (longer without recent XTRA assistance data — see the GPS/GNSS setup section of `README.md`). Give it time before troubleshooting.

### 2.4 Confirm data is flowing from the final position

Check the dashboard again for a reading with GPS coordinates matching the actual install location, and confirm the WittyPi schedule is triggering boots as expected.

### 2.5 Final weatherproofing

Confirm all cable entries are sealed, connections to the solar panel are secure, and the case is fully closed before leaving the site.

---

## Before You Leave: Remote Verification

- **Dashboard**: check for regular incoming readings at the expected
  `monitoring_frequency` cadence.
- **Remote access**: `ssh <hostname>` over Tailscale (only works while the Pi is powered on per its WittyPi schedule
- **Remote Start**: if the system is in range of a LoRa gateway and connected to it you can send a remote start signal from the Chirpstack server or through the dashboard (the dashboard is still under development so it might have issues)

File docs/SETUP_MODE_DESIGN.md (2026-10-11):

# Setup Mode: Guided Installation, Calibration and Field Debugging

**Status:** design, not yet implemented.
**Related:** issue #17 (Integrate Calibration Workflow), `docs/IMU_CALIBRATION.md`,
`docs/FIELD_DEPLOYMENT_GUIDE.md`, `docs/POWER_ANALYSIS.md`, `docs/IP_TRANSMISSION.md`.

## 1. Goal

Make installing and calibrating a node something a collaborator can do from
their own phone, without SSH or the command line, and give the dashboard a way
to turn Wi-Fi on for one node when someone needs to debug it in the field.

Constraints:

- Collaborators use a mix of devices (Android, iOS, laptops). Nothing may
  require installing an app.
- RTK equipment is part of the standard installation kit, but will not always
  be on hand. Setup must still work without it, and must say clearly when the
  result is weaker.
- Wi-Fi has two jobs: configuring and debugging nodes, and reporting. For
  reporting it is the second transport: LoRa first, then Wi-Fi, then cellular as
  the last resort (`docs/IP_TRANSMISSION.md`, #120).
- Power is tight (see `docs/POWER_ANALYSIS.md`, `docs/UNIT006_POWER_FAILURE.md`).
  Anything that keeps the Pi awake must end on its own.

## 2. What exists today

| Piece | Where | Relevant behaviour |
|---|---|---|
| IMU calibration | `tools/bno055_calibration.py` | Step-gated, but driven by terminal `input()` prompts over SSH |
| Camera capture | `tools/take_photo.py`, `tools/picam_fast.py` (Picamera2) | No live preview |
| Lens calibration | `tools/camera_calibration.py` | Uses `cv2.VideoCapture`, cannot drive the CSI camera; bench task |
| Pose from markers | Georeferencing repo (`gcp.py` `refine_pose_from_gcps`, `label_gcp.py`) | Desktop only, run days after installation |
| IP commands | `tools/transmit_ip.py` `poll_downlink()` / `apply_downlink_command()` | Node polls once per wake, so a command waits for the next scheduled wake. With the daylight schedule (`config/wittypi/watercam_daylight_2h.wpi`, #123) that is up to 2 h by day and about 16 h overnight |
| LoRa commands | `tools/lora_runtime_integration.py` | Parsed only while the Pi is awake |
| Wake from sleep | mDot-AT-firmware `CmdClassCPacketProcessor` | The mDot is Class C on the Witty Pi's always-on rail. Only the exact one-byte `!` (0x21) wakes the Pi, by pulsing the Witty Pi switch; that packet is not passed on to the Pi |
| Staying awake | `ticktalk_main.py` `call_shutdown()`, Witty Pi schedule | Two separate limits: `call_shutdown()` requests shutdown after `shutdown_iteration_limit` captures, and the Witty Pi schedule's ON window (10-15 min) ends the wake regardless. Emergency mode bypasses the first and clears the Witty Pi shutdown time (`tools/wittypi_control.py`); `tools/witty_pi_4.py` can clear a shutdown time but not set one |
| Battery level | none | Units have no state-of-charge sensor. The Witty Pi's 5 V reading is regulated and says nothing about charge, so `battery_pct` is no longer reported (#122). A real reading is planned (`docs/POWER_ANALYSIS.md`, *Battery state of charge*) |
| Network control | NetworkManager via `nmcli` | User `pi` has NetworkManager network-control for all interfaces. This is intentional and this design does not narrow it |

Two consequences shape the design:

1. **A sleeping node cannot be told anything except "emergency".** Using
   emergency mode to wake a node for debugging would also clear its schedule
   and switch it into emergency reporting, so it is not a substitute.
2. **The single-channel RFM95W forwarder is uplink-only.** Remote commands over
   LoRa need ChirpStack and a full gateway within range.

## 3. Design overview

```
 dashboard ──(17 97 maintenance on)──> API ──> ChirpStack ──> mDot ──wake──> Pi
                                       └─> IP downlink queue ────────────────┘
 Pi in maintenance mode:
   stay awake (bounded) ─ Wi-Fi up (hotspot or client) ─ setup web page ─ status uplink
 collaborator's phone ──Wi-Fi──> setup page: live view, IMU wizard, markers, pose check
```

Five parts, each useful on its own:

1. Maintenance mode on the node (section 4)
2. A maintenance command and status message (section 5)
3. A dashboard control (section 6)
4. A maintenance wake in the mDot firmware (section 7)
5. The setup web page and installation wizard (section 8)

## 4. Maintenance mode (node)

A new runtime state, separate from emergency mode.

**Entering it:**

- the maintenance command (section 5), over LoRa or IP;
- a local trigger in the field, so setup does not depend on the dashboard or
  on coverage. Candidate: entering maintenance mode automatically when the Pi
  was woken by the Witty Pi button rather than by its schedule. Whether the
  Witty Pi exposes the wake source needs checking; if it does not, a reed
  switch on a spare GPIO is the fallback;
- first boot of an unconfigured node (no `unit_config` with `setup_complete`).

**While active:**

- The emergency flags are not touched.
- The Witty Pi's shutdown time is moved to the maintenance deadline. Stopping
  ticktalk (and with it `call_shutdown()`) is not enough: the schedule's ON
  window would still end the wake after 10-15 min. Setting the shutdown time, rather than clearing it
  as emergency mode does, means the Witty Pi itself enforces the limit even if
  the Pi hangs. This needs a `set_shutdown_time()` in `tools/witty_pi_4.py`.
  On exit the normal schedule is restored.
- Wi-Fi comes up in one of two modes:
  - **hotspot:** the node runs an access point; the collaborator's phone joins
    it. Used for installation and the wizard. Each node has its own WPA2
    passphrase (printed on the unit label and visible to authorised dashboard
    users). It is not stored in this repository.
  - **client:** the node joins a known network, for example a team phone
    hotspot, and comes up on Tailscale so someone remote can use
    `tailscale ssh`. Network credentials are provisioned per node at the bench
    and kept out of the repository.
- **The capture and segmentation workflow does not run.** While the node is
  being configured over the hotspot, nothing captures, segments, compresses or
  transmits flood data: `ticktalk.service` (and the legacy `watercam.service`)
  are stopped, `segformer_daemon.service` is stopped to free memory and CPU,
  and `button.service` is stopped because it also drives the camera. The only
  camera use is the setup page's own preview and stills. Photos taken during
  setup are not flood observations and are never sent as captures. Client mode
  (remote debugging) starts with the workflow stopped too; whoever is
  debugging can start it by hand if that is what they are testing.
- The setup web page (section 8) is served on the Wi-Fi interface only.
- Because ticktalk is stopped, maintenance mode runs as its own service
  (`maintenance.service`, with `Conflicts=` on the workflow services). It keeps
  `lora_daemon.service` running, so it can still receive a maintenance-off
  command over LoRa and send the status uplink, and it does its own IP
  downlink polling. If the node boots straight into maintenance mode (local
  trigger or first boot), a runtime flag stops `ticktalk.service` from starting
  at all.
- With the workflow stopped, the only uplink is the maintenance status
  message. In hotspot mode the radio is busy as an access point, so it goes
  over LoRa, or cellular if LoRa is not joined (the order from #120 minus
  Wi-Fi).

**Leaving it**, whichever happens first:

- the requested duration expires (default 30 min, hard cap configurable,
  suggested 120 min);
- setup is marked complete in the wizard;
- an explicit "maintenance off" command;
- the Pi reports under-voltage (the flags added for the Unit 006
  investigation). A battery threshold is added once units have a real
  state-of-charge reading (#122); until then under-voltage and the time limit
  are the only protection.

On exit the hotspot (or the session's client network) goes down and Wi-Fi goes
back to its normal role as a reporting transport, joining the networks the node
knows during each wake. The maintenance service starts `segformer_daemon` and
`ticktalk` again, so capture resumes and the normal shutdown logic applies; if
the deadline was reached, the Witty Pi shutdown ends the wake instead and the
next scheduled wake starts normally.

## 5. Command and status message

**Command `17 97`, maintenance.** Unused in the API encoder, the IP command
table and the LoRa tables today.

| Byte | Meaning |
|---|---|
| 0 | Duration in minutes, 1-240; `0` = leave maintenance mode now |
| 1 | Wi-Fi mode: `0` hotspot, `1` client |

Needs adding in three places: `API/app/encoders.py`,
`tools/transmit_ip.py` `apply_downlink_command()`, and the TLV table in
`tools/lora_runtime_integration.py`.

**Status message.** The IP downlink queue marks a command delivered as soon as
the node fetches it, and there is no acknowledgement, so the dashboard cannot
tell whether a command took effect. On entering and leaving maintenance mode
the node sends a status uplink: mode, Wi-Fi mode, SSID, IP address on the Wi-Fi
interface, minutes remaining, the Pi's under-voltage flags (and battery level
once a real reading exists), and the reason it left.

**Fix first:** `14 94` means something different on each transport. The IP
path and the API encoder treat it as the flood-code frequency (an index into
10-60 min); the LoRa TLV table sets `photo_interval` in seconds. Whatever
`14 94` should mean, the two paths must agree before more commands are added.

## 6. Dashboard (API repo)

- Per-node **Enable Wi-Fi** control: duration picker, hotspot/client choice.
  Behind its own permission, logged with the user and time.
- Shows the status message: on/off, SSID and passphrase for hotspot mode, IP
  for client mode, countdown, last exit reason.
- If the node is asleep and cannot be woken (IP transport, or LoRa without a
  maintenance wake), say "queued, applies at the next wake" and show the
  expected wake time, rather than appearing to fail.
- Delivering queued commands on the next uplink (API issue #65) shortens that
  wait for IP nodes.

## 7. Maintenance wake (mDot firmware)

Today the only packet that wakes the Pi is `!`, and it is consumed rather than
passed on. Proposed:

- ~~A second wake packet, reserved for maintenance, that pulses the Witty Pi
  switch exactly like `!` but does not imply emergency.~~ Not needed: `!` is now
  only a remote start, and emergency mode is its own command
  ([REMOTE_START_AND_EMERGENCY.md](REMOTE_START_AND_EMERGENCY.md)).
- While the Pi is off (PA_6 low), the mDot holds the most recent non-emergency
  downlink instead of forwarding it to a serial port nobody is reading, and
  replays it once the Pi is up. The maintenance command then travels as a
  normal downlink right behind the wake packet.

With this, a LoRa node responds to the dashboard control within minutes.
Without it, the control still works, at the node's next scheduled wake.

## 8. Setup web page and wizard

Plain HTML and JavaScript served by a small web server on the node (Flask or
similar), tested on Android Chrome, iOS Safari and a desktop browser. It calls
the existing Python tools rather than reimplementing them.

| Step | What the collaborator sees | Backed by |
|---|---|---|
| 1. Check the node | Battery, radio, GPS fix, IMU and camera status | existing health checks |
| 2. Aim the camera | Low-resolution live preview with a horizon line and range rings from the current IMU pitch/roll and mount height; warns when the view does not reach the area it should cover | Picamera2 MJPEG stream, `camera_geometry.py` / `geo_core.py` |
| 3. IMU on the pole | The existing step-gated procedure, one instruction per screen, live 0-3 calibration bars, automatic advance | `tools/bno055_calibration.py` stage 2 |
| 4. Markers | Capture a still; tap each marker on the screen and name it; at least 4 required | port of Georeferencing `label_gcp.py` to touch |
| 5. Pose | **With RTK:** import the marker survey, refine the pose on the node, show per-marker residuals and pass/fail. **Without RTK:** save the photo, labels and IMU readings; the pose is marked *provisional* | Georeferencing `refine_pose_from_gcps`, vendored as `camera_calibration.py` already is |
| 6. Save | Writes the node's `unit_config`, sends it to the API, marks setup complete and leaves maintenance mode | `unit_config` loader |

A provisional pose shows as such on the dashboard until it is verified, either
by a return visit with RTK or by matching the saved photo against reference
imagery later. A node never silently runs on an unverified heading.

**Data handling.** Unit configs and marker surveys contain the node's exact
position. They go to the private API and stay on the node; they are never
committed to this repository.

**Bench work stays at the bench.** Lens calibration and IMU stage 1 are done
before shipping, so nodes reach the field already calibrated and collaborators
only do the on-pole steps.

## 9. Implementation order

1. Maintenance mode with a local trigger, the hotspot, and the time and
   battery limits (node only). Usable immediately for installation. (#117)
2. Agree on `14 94` (#116); add `17 97` and the status message (#118) and the
   dashboard control (WaterCam-Team/API#109). Works within today's wake latency.
3. Maintenance wake and downlink replay in the mDot firmware
   (WaterCam-Team/mDot-AT-firmware#3).
4. Wizard pages, starting with the live view (step 2) and the IMU wizard
   (step 3), then markers and pose (steps 4-5). (#119)

## 10. Open questions

- Can the Pi tell whether the Witty Pi button or the schedule woke it?
- Which wake byte is free for maintenance, given what else is ever sent as a
  one-byte downlink?
- Until units have a state-of-charge reading, should maintenance mode refuse
  to start, or shorten itself, after a run of under-voltage flags?
- Is the hotspot's extra draw acceptable for a 30-120 min session at the
  battery levels seen in the field? Measure on a bench unit.
- Client Wi-Fi outside setup is settled: it is the second reporting transport,
  joined during each wake, so it follows the wake schedule and needs no duty
  cycle of its own. Still open: whether the setup session's client network (for
  example a team phone hotspot) should stay among the networks used for
  reporting afterwards.

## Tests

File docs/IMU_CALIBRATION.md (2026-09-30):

# WaterCam IMU Calibration Procedure

**Applies to:** All WaterCam units equipped with a BNO055 IMU  
**Script:** `tools/bno055_calibration.py`  
**Time required:** ~20 minutes pre-mount + ~10 minutes post-mount

---

## Background

The BNO055 IMU provides heading (compass bearing), pitch, and roll for the georeferencing pipeline. The heading is the most accuracy-critical value: a 2.5° heading error at 13 m slant range causes ~57 cm lateral displacement in the georeferenced flood extent.

The BNO055 has no internal non-volatile memory. Calibration offsets must be saved to disk and reloaded on every boot. Without saved offsets, the magnetometer starts uncalibrated (`mag=0`) and heading output is unreliable.

**Calibration is split into two stages because of the pole installation constraint:**

- **Stage 1 (pre-mount)** captures the magnetic signature of the camera box's own hardware — PCB traces, connectors, screws, the Raspberry Pi. This requires free rotation of the box and cannot be done once it is fixed to a pole.
- **Stage 2 (post-mount)** measures the residual heading error introduced by the mounting pole and local environment. This must be done after installation because the pole itself distorts the local magnetic field.

---

## What you need

**For Stage 1 (pre-mount):**
- Assembled WaterCam unit (fully populated PCB, all components installed)
- Raspberry Pi powered and running
- Outdoor location away from metal furniture, power supplies, and electrical panels
- Laptop or SSH session to run the calibration script

**For Stage 2 (post-mount):**
- Unit installed on its pole in the field
- viDoc RTK rover + iPhone with Pix4DCatch (or any RTK equipment)
- Two surveyed reference points visible from the camera with a known true bearing between them
- SSH session to the Pi

---

## Stage 1 — Pre-mount calibration

Run this **before** permanently mounting the unit. If the unit is already mounted, dismount it for this stage.

### 1.1 Go to the deployment site (or a nearby outdoor area)

Do not calibrate at a workbench or indoors near computers and power supplies. The hard-iron calibration captures the magnetic environment at the time of calibration — you want that environment to match where the unit will be deployed. Within 50 m of the deployment site is ideal.

### 1.2 Connect and run the calibration script

```bash
cd /home/pi/SU-WaterCam
python tools/bno055_calibration.py \
  --unit-config unit_config_UFO006.json \
  --mode calibrate
```

Replace `unit_config_UFO006.json` with the config file for the unit you are calibrating.

### 1.3 Complete the three calibration stages

The script guides you through each stage interactively.

**Stage 1/3 — Gyroscope (~5 seconds)**

Place the box on a flat, stable surface and hold it completely still. Press Enter when ready. The gyroscope reaches `status=3` in about 5 seconds.

**Stage 2/3 — Accelerometer (~2 minutes)**

You will be guided through 6 positions. Hold the box still in each position for 5 seconds:

1. Base down — box sitting normally
2. Lid down — box flipped upside-down
3. Tilt forward ~45° — front edge resting on a book or wedge
4. Tilt backward ~45° — back edge resting on a book or wedge
5. Tilt left ~45° — left edge resting on a wedge
6. Tilt right ~45° — right edge resting on a wedge

> **Note:** The antenna connectors block two of the six faces required for `accel=3`. `accel=2` is the expected ceiling on this hardware and is acceptable.

**Stage 3/3 — Magnetometer (~2 minutes)**

Pick up the box and rotate it slowly through a figure-eight pattern — as if drawing a large "8" in the air. Rules:

- Move **slowly and smoothly** — fast motion does not help
- Stay **at least 30 cm** away from metal objects and cables
- Continue rotating for at least 30 seconds, even if `mag=3` is reached early

When `mag=3` is confirmed for the minimum time, the offsets are saved automatically to `bno055_calibration.json` (or the path specified in your unit config).

### 1.4 Verify the saved file

```bash
cat bno055_calibration.json
```

Confirm the output shows `"mag": 3` in the `calibration_status` block. If it shows `"mag": 0` or `"mag": 1`, the magnetometer stage did not complete — re-run the procedure.

---

## Stage 2 — Post-mount validation

Run this **after** the unit is permanently installed on its pole. Stage 1 must be complete first.

### 2.1 Survey a known bearing

Using the viDoc RTK rover, occupy two points that are visible from the camera — for example, two painted GCP markers in the road. Record RTK-fixed coordinates for each point (≥30 s occupation, PDOP < 2.5).

Compute the true bearing from the camera's position toward one of the surveyed points. In Python:

```python
import math
lat1, lon1 = 40.71280, -74.00600   # camera position (RTK-surveyed; placeholder)
lat2, lon2 = 40.71266, -74.00540   # reference point (RTK-surveyed; placeholder)

dlat = math.radians(lat2 - lat1)
dlon = math.radians(lon2 - lon1)
lat1r = math.radians(lat1)
lat2r = math.radians(lat2)

x = math.sin(dlon) * math.cos(lat2r)
y = math.cos(lat1r) * math.sin(lat2r) - math.sin(lat1r) * math.cos(lat2r) * math.cos(dlon)
bearing = (math.degrees(math.atan2(x, y)) + 360) % 360
print(f"True bearing: {bearing:.2f}°")
```

### 2.2 Run mount mode

```bash
python tools/bno055_calibration.py \
  --unit-config unit_config_UFO006.json \
  --mode mount \
  --known-bearing 70.3 \
  --save-correction
```

Replace `70.3` with the true bearing you computed. The `--save-correction` flag writes the measured correction directly back to `imu_heading_correction_deg` in the unit config.

The script will:
1. Load the saved calibration offsets
2. Wait for `gyro=3` (unit must be completely still — ~10 seconds)
3. Check that magnetometer offsets are active (`mag≥2`)
4. Collect 50 heading samples and compare against the known bearing
5. Compute and save `imu_heading_correction_deg`

### 2.3 Verify the result

The script prints a result like:

```
[VALIDATE] Results:
  Known true bearing  : 70.30°
  IMU mean heading    : 72.85° (after declination correction)
  Residual error      : +2.55°
  Heading std dev     : 0.142° (noise level)

  Measured imu_heading_correction_deg : -2.550°
  Updated unit_config_UFO006.json
    imu_heading_correction_deg: 0.0 → -2.55
```

A **residual error < 2°** is good. Between 2–5° is acceptable but note it in the installation record. Above 5° indicates a problem — see Troubleshooting below.

> **Copy the unit config to the Georeferencing repo.** The `imu_heading_correction_deg` value is also used by the Georeferencing pipeline's `resolve_heading()` function. Update `unit_config_UFO006.json` in the Georeferencing repository to match.

---

## Maintenance

| Event | Action required |
|---|---|
| Normal power cycle | Nothing — offsets load automatically on boot |
| Hardware change inside box (new PCB revision, repositioned sensor) | Repeat Stage 1 from scratch |
| Unit moved to a different pole or site | Repeat Stage 2 (Stage 1 offsets are still valid) |
| Mount disturbed or pole replaced | Repeat Stage 2 |
| Every ~6 months | Repeat Stage 2 to check for drift; repeat Stage 1 only if heading error has grown > 5° |

The Earth's magnetic field drifts slowly (~0.1°/year at Syracuse, NY). Annual Stage 2 re-validation is sufficient unless hardware changes.

---

## Checking calibration status at any time

```bash
python tools/bno055_calibration.py \
  --unit-config unit_config_UFO006.json \
  --mode log \
  --interval 2
```

This loads offsets and prints live calibration status alongside heading output. Watch the `cal=` field:

```
2026-06-23T10:14:32  hdg=  70.8°  pitch= -5.2°  roll=  0.3°  T=28°C  cal=3/3/2/3
                                                                           ^ ^ ^ ^
                                                               sys gyro accel mag
```

Expected when fully calibrated: `cal=3/3/2/3` (sys=3, gyro=3, accel=2, mag=3).  
If `mag < 2` immediately after boot but climbs to 3 within a few seconds on its
own: that's normal — see the note below. If it stays below 2 for longer than
that, the calibration file is missing or corrupted — re-run Stage 1.

**Note on the first few seconds after boot:** writing saved offsets to the
sensor does not instantly restore `calibration_status` to its saved value —
the BNO055's own fusion algorithm re-earns that confidence over a short
window of live operation (typically a few seconds), even though the offsets
themselves are already correct. `tools/bno055_imu.py`'s `_get_sensor()` waits
up to 5 seconds for `mag` to reconfirm before returning, specifically to
avoid the very first photo after boot spuriously tripping
`add_metadata.py`'s "magnetometer uncalibrated" warning. If you see that
warning on a unit with valid, fully-calibrated (`mag: 3`) saved offsets, it
most likely already resolved a few seconds later — check the *next* photo's
EXIF/log rather than assuming calibration itself failed.

---

## Troubleshooting

**`mag` stays at 0 after loading offsets**

First check whether it's just slow to reconfirm rather than genuinely broken
— see the note in the previous section; this can take a few seconds even
with valid saved offsets. If it's still 0 well after that: the calibration
file is missing, has the wrong path, or the offsets file itself has
`"mag": 0` in the saved status (Stage 1 was incomplete). Re-run Stage 1 with
the box off the pole.

**Residual heading error > 5° in Stage 2**

Possible causes:
- The pole is made of highly magnetic steel. Check whether the heading error sign is consistent (fixed offset) or variable (interference). A fixed offset will be fully corrected by `imu_heading_correction_deg`.
- Stage 1 magnetometer calibration was incomplete (`mag < 3` when saved). Re-run Stage 1 ensuring `mag=3` is reached before the 30-second minimum rotation time elapses.
- Incorrect magnetic declination in the unit config. Syracuse, NY is approximately −12.5° (west). Verify with NOAA's calculator for the exact site coordinates.
- The `--known-bearing` value was computed incorrectly. Double-check the RTK coordinates and bearing formula.

**Heading jumps between sessions**

The mount is not rigid — the camera box has rotated on the pole. Check physical clamping and re-run Stage 2. See the accuracy improvement plan for mount stabilization guidance.

**`gyro` does not reach 3 within 30 seconds in mount mode**

The unit is being vibrated by wind or nearby activity. Wait for calm conditions and re-run mount mode.

---

## How the corrections are applied

The full heading correction chain, from raw sensor to georeferencing pipeline:

```
Raw BNO055 heading (magnetic, sensor frame)
  + imu_mount_offset_deg      (physical rotation of sensor on PCB, e.g. +180°)
  = corrected sensor heading

  + imu_magnetic_declination_deg   (magnetic → true North, e.g. −12.5° at Syracuse)
  + imu_heading_correction_deg     (pole influence + residual, measured by Stage 2)
  = true heading (degrees from true North, clockwise)
```

The mount offset and declination are fixed values set once per unit. The heading correction is measured after each installation. All three values live in the unit config JSON and are applied automatically by the georeferencing pipeline's `unit_config.resolve_heading()` function.

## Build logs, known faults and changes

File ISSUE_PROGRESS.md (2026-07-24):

# Open Issue Progress

Documents work already in the codebase against each open GitHub issue.

---

## #16 — Use IP when LoRa not available

**Status: Store-and-forward implemented. LoRa-unavailable detection not yet implemented.**

### What exists

| File | What it does |
|---|---|
| `tools/transmit_ip.py` | `IPTransmitter` class — POST uplink to `/ip/uplink`, GET downlink from `/ip/downlink/{device_id}`, exponential-backoff retry, configurable timeout/retries, `is_reachable()` health check |
| `tools/transmit_ip.py` | `IPTransmitter._enqueue()` — atomic write to `data/ip_uplink_pending/<ts>_<n>.json`; evicts oldest entries when `max_queue_depth` is reached |
| `tools/transmit_ip.py` | `IPTransmitter._drain_queue()` — oldest-first drain; evicts stale entries (> `max_queue_age_days`), deletes corrupt files, stops on first send failure |
| `ticktalk_main.py` | `ip_uplink_transmit()` — sensor collection now runs before `is_reachable()`; on unreachable or send failure the reading is enqueued; on next wake queued entries are drained before the live reading is sent |
| `ticktalk_main.py` | `ip_downlink_poll_and_apply()` — polls server for queued commands and applies them to runtime config each wake cycle |
| `runtime_config.json` | `ip_upload` block: `enabled`, `server_url`, `api_key`, `device_id`, `timeout_s`, `retry_attempts`, `retry_backoff_s`, `fallback_to_lora`, `downlink_poll_interval_s`, `max_queue_depth` (48), `max_queue_age_days` (7) |
| `tests/test_ip_upload.py` | Integration test suite for `IPTransmitter` — uplink, downlink, reachability, edge cases; skips cleanly when server is down |
| `tests/test_ip_store_and_forward.py` | 29 tests covering queue creation, depth/age eviction, drain ordering, stop-on-failure, corrupt-file recovery, integration with `ip_uplink_transmit.__wrapped__` |

### What is missing

- **LoRa-unavailable detection**: the current implementation runs IP as a parallel path alongside LoRa, not as a fallback triggered by LoRa failure. True fallback logic (detect LoRa failure → switch to IP) is not implemented. Needs design discussion — e.g. how to detect LoRa failure reliably without waiting for a full timeout on every cycle.

---

## #20 — IP Command Handling

**Status: Implemented and tested.**

### What exists

`ticktalk_main.py:1765` — `ip_downlink_poll_and_apply()`:

- Polls `IPTransmitter.poll_downlink()` at the start of each wake cycle
- Delegates to `tools.transmit_ip.apply_downlink_command()` for decoding and dispatch
- Disabled when `ip_upload.enabled=false`

`tools/transmit_ip.py:398` — `apply_downlink_command()`:

- Standalone (no TickTalkPython dependency); accepts a `set_param_fn` callable
- Dispatches all recognised codes: `10 90` area_threshold, `11 91` stage_threshold, `12 92` monitoring_freq, `13 93` emergency_freq, `14 94` flood_code_freq
- Validates payload length per code; skips malformed parts without crashing

`tests/test_ip_command_handling.py`:

- 30+ assertions across 7 test classes covering all parameter codes, index bounds, multi-part commands, malformed inputs, and queue_id propagation
- No network or hardware required; `set_param_fn` is a plain dict accumulator

---

## #19 — Downstream Command Handling (LoRa)

**Status: Implementation complete. Test coverage exists but hardware-path testing is incomplete.**

### What exists

`tools/lora_handler_concurrent.py` (≈2100 lines):

- Full TLV-based command parser (`_parse_tlv_commands`, `_apply_command_tlv`) covering all parameter channels (area threshold, stage threshold, monitoring/emergency frequency, debug mode, emergency mode activation/deactivation)
- Legacy hex command format also handled for backwards compatibility
- Command timestamp logging for frequency-adjustment tracking

Test files:

| File | Coverage |
|---|---|
| `tests/test_command_parsing.py` | LoRa command parsing unit tests |
| `tests/test_lora_command_integration.py` | End-to-end with simulated serial hardware |
| `tests/test_new_format_commands.py` | TLV `[Channel][Command][Value]` format |
| `tests/test_chirpstack_parameter_update.py` | Sending downlinks through ChirpStack API |
| `tests/test_emergency_activation.py` | Emergency mode activate/deactivate commands |
| `tests/test_emergency_mode*.py` | Emergency mode state machine |

### What is missing

- Tests require either `/dev/ttyAMA5` hardware or mock serial — no CI-safe pure-unit test that covers the full receive-parse-apply path without mocking concerns.
- The issue is open; it may still have known bugs that haven't been caught by the existing test suite.

---

## #18 — Calibration should be applied prior to Registration

**Status: Resolved. Undistortion is wired into the coregistration pipeline.**

### What exists

`tools/camera_calibration.py` is the canonical calibration tool — a copy of the calibration script from this project's separate Georeferencing codebase (not published on GitHub), the source of truth. Produces the `K`/`D`/`img_size`/`rms` schema that `coreg_multiple.py` actually reads. Its two local dependencies, `camera_geometry.py` and `geo_core.py`, are also copied into `tools/`. `tools/camera_calibration_legacy.py` (the old SU-WaterCam-specific script) and `tools/generate_calibration_chessboard.py` are deprecated — see the notices at the top of each file — kept only as a reference/fallback for on-device Picamera2 capture, since `tools/camera_calibration.py` uses `cv2.VideoCapture` and can't drive the Pi's CSI camera.

`config/camera_calibration.json` holds the current OV5647 calibration (produced by the Georeferencing tool).

`tools/coreg_multiple.py`:

- `_undistort_if_calibrated()` loads `config/camera_calibration.json` by default and calls `cv2.undistort()` if the file exists
- Applied only to the fixed/optical (OV5647/NIR) image in `mutual_information_registration()` and `apply_cached_transform()`, before any registration or resampling occurs — the moving/Lepton (LWIR) image is never undistorted with this calibration, since it has different optics and no calibration data of its own

---

## #17 — Integrate Calibration Workflow

**Status: Intrinsic calibration and coregistration integration exist. Extrinsic collection and guided installation workflow are not yet implemented.**

### What exists

`tools/camera_calibration.py` — canonical tool (copied from this project's separate Georeferencing codebase, not published on GitHub); computes and saves lens intrinsics (`K`/`D`). `tools/camera_calibration_legacy.py` is deprecated (see notice at top of file).

`tools/coreg_multiple.py` — `_undistort_if_calibrated()` applies `config/camera_calibration.json` lens correction to the fixed/optical (OV5647) image only before registration and resampling. Integration with coregistration is complete.

### What is missing

- **Extrinsic parameter collection**: no tooling for collecting or saving the extrinsic parameters (rotation/translation of the camera relative to a world reference) needed for georeferencing.
- **Installation workflow**: no guided process to walk a new installation through capturing calibration data and validating the output.

---

## #21 — Unit ID Metadata

**Status: Resolved. Unit ID is embedded in EXIF and XMP on every captured image.**

### What exists

`tools/add_metadata.py`:

- `_read_device_id()` reads `device_id` from `runtime_config.json` via `_load_ip_config()`
- Writes `device_id` to EXIF `BodySerialNumber` tag (0xA431)
- Writes `device_id` to XMP `DeviceID` property (DC namespace) for Pix4D compatibility
- Also writes IMU orientation (roll/pitch/yaw) to EXIF `UserComment` and XMP `Roll`/`Pitch`/`Yaw`
- Writes GPS fix (lat/lon/alt/track) to EXIF GPS IFD
- Called by `tools/take_nir_photos.py` for every captured image

---

## #2 — Cached Registration Transform not Used

**Status: Resolved. Cache is used on subsequent cycles; resolution changes are detected.**

### What exists

`tools/coreg_multiple.py`:

| Function | Role |
|---|---|
| `save_transform_parameters()` | Serialises transform type, parameters, fixed parameters, and image size metadata to `registration_transform.json` |
| `load_transform_parameters()` | Loads cached transform + saved image size; returns `None` if not found or if `FORCE_RECALCULATE_TRANSFORM=True` |
| `apply_cached_transform()` | Resamples the moving image using the loaded transform |
| `mutual_information_registration()` | Checks type, parameter count, and image size before using the cached transform |
| `validate_transform_compatibility()` | Compares saved image size against current image dimensions (with the same scaling logic); rejects cache on mismatch |
| `--position-changed` CLI flag | Forces recalculation when the camera has been moved |

Two bugs fixed:
- `SetInitialTransform(inPlace=False)` caused `Execute()` to return a `CompositeTransform` wrapper, failing the type check every cycle. Fixed to `inPlace=True`.
- `validate_transform_compatibility()` computed `expected_size` but never compared it. Now rejects the cache when the saved size doesn't match the current image dimensions.

### What is missing

- No automated test (SimpleITK not available in the dev/test environment).

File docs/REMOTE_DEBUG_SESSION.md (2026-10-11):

# Remote debug session: Tailscale SSH over cellular, started over LoRa

An admin can ask a deployed node, over LoRa, to bring its cellular connection up
and stay reachable with `tailscale ssh` for a set time, even if the Pi is off.
The node stops its capture workflow, so nothing shuts it down mid-session, and
everything goes back to normal when the admin ends the session or the time runs
out.

It is a standalone command, separate from emergency mode (which keeps capturing)
and from the planned maintenance mode (#117, Wi-Fi only).

## Command

`18 98 NN`, on fPort 10 like the other downlinks. It has the same meaning over IP.

| `NN` | Meaning |
|---|---|
| `01`–`18` (hex) | Start the session, or extend a running one, for `NN × 10` minutes (10 min to 4 h) from now |
| `00` | End the session and restore normal operation |

Values above `18` are capped at 4 h. On the node, the LoRa decoder sees it as
channel `18`, command `98`, value `NN`, read as hex.

## Sequence

```
admin: dashboard "Remote debug" (minutes, wake if off)
API:   send 18 98 NN (Class C, delivered at once)
         node awake? -> lora_daemon starts the session -> status uplink within ~2 min
         no status after 60 s and "wake" ticked:
           send "!"         mDot pulses the Witty Pi switch: Pi boots (~60 s)
           resend 18 98 NN every 20 s for 5 min, until a status uplink says rd > 0
node:  1. clear the Witty Pi shutdown alarm       (the Pi stays on past its window)
       2. stop ticktalk.service                   (no capture load, no call_shutdown)
       3. nmcli connection up Quectel             (pi may do this: polkit rule)
       4. wait for Tailscale: BackendState Running and Self.Online (up to 120 s)
       5. LoRa status uplink {"dbg":1,"rd":<min left>,"tn":<tailscale 0/1>,"cl":<cellular 0/1>}
admin: tailscale ssh pi@ufo-01-01-NNN...
end:   dashboard "End remote debug" (18 98 00), or on the node:
         ~/SU-WaterCam/venv/bin/python ~/SU-WaterCam/tools/remote_debug.py stop
       or the time runs out (checked every 30 s by remote-debug.timer)
node:  1. cellular down, if it is managed on demand (Quectel autoconnect off)
       2. re-arm the Witty Pi from the installed schedule.wpi (runScript.sh)
       3. start ticktalk.service: a normal cycle, then its usual shutdown
       4. LoRa status uplink with rd 0
```

`remote_debug.py stop --shutdown` skips the capture cycle and powers off at once;
the Witty Pi wakes the Pi at its next scheduled slot.

### Why the API resends after `!`

The mDot does not pass `!` to the Pi, and it drops any downlink that arrives
while the Pi is off. A woken Pi runs its normal boot: `lora_daemon` starts first,
then ticktalk, which shuts the Pi down after its cycles (a few minutes). The
resends make sure `18 98` reaches `lora_daemon` in that gap. The API sends the
plain command first and only sends `!` when there is no answer, which saves the
wake round trip for a node that is already up. `!` is only a remote start, so it
is harmless to a running Pi: the mDot checks the Pi's GPIO5 and does nothing
([REMOTE_START_AND_EMERGENCY.md](REMOTE_START_AND_EMERGENCY.md)).

The Witty Pi itself doesn't cut a woken Pi short: booted between slots, it arms
the shutdown for the end of the next ON slot, and `recovery_boot` only defers
boots caused by power returning, not switch presses.

## Node pieces

- **`tools/remote_debug.py`**: `start --minutes N`, `stop [--shutdown]`,
  `status`, `tick`. State in `data/remote_debug.json`: end time, what started
  it, and whether cellular was already up. Written atomically.
- **`lora_daemon`**: on `18 98 NN`, runs `remote_debug.start()` or `stop()` on
  a thread, so the serial listener isn't blocked while Tailscale connects.
- **IP downlink**: `18 98 NN` writes a request file that the timer picks up, since
  ticktalk can't stop itself and keep running the session.
- **`remote-debug.timer`** runs `remote_debug.py tick` every 30 s as `pi`. It
  applies a pending request and ends an expired session. It doesn't depend on
  `lora_daemon`, which a node without an mDot doesn't run.
- **Privileges**: `pi` stops and starts ticktalk with
  `doas systemctl stop|start ticktalk.service` (two nopass rules added to
  `config/doas.conf`), falling back to `sudo -n`. The Witty Pi calls are the ones
  emergency mode already uses. `nmcli` needs the polkit rule from section 1.5.1
  of the deployment guide.

## Safety

- **Every session ends:** 4 h maximum, and the timer ends an expired session even
  after a reboot or a `lora_daemon` crash.
- **Restore only re-arms the installed schedule.** It never writes `schedule.wpi`.
  (`apply_emergency_schedule(False)` regenerates the file from config values, so
  it isn't used here.)
- **Restarting a node mid-session doesn't strand it:** at boot, `tick` sees the
  session is still running and keeps ticktalk stopped. A session that expired
  while the Pi was off is ended on the first tick.
- **Data rate:** the status uplink is trimmed to the mDot's payload limit, keeping
  `{"dbg":1,"rd":N}` (about 17 B), which is what the API confirms with. That fits at
  SF9 or faster. At SF10 (11 B) nothing useful fits, so the node sends no status
  and the API can't confirm; the session still starts.
- **Cost:** a session uses roughly 1–5 MB of the 500 MB SIM (Tailscale overhead
  plus the SSH traffic) and keeps the Pi on at about 2–2.6 W. Use short sessions
  on units with marginal power.

## Install on a node

```bash
cd ~/SU-WaterCam
sudo cp config/remote-debug.service config/remote-debug.timer /etc/systemd/system/
sudo cp config/doas.conf /etc/doas.conf
sudo systemctl daemon-reload && sudo systemctl enable --now remote-debug.timer
sudo systemctl restart lora_daemon
```

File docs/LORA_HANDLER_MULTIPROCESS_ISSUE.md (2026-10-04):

# LoRa Handler Multi-Process Conflict

**Status:** Root cause confirmed (2026-07-22). Pragmatic mitigation shipped
(retry-with-backoff). Proper architectural fix (single-owner daemon + IPC)
implemented (2026-07-22) — see "Implemented fix" below. **Not yet installed
on any field device**; requires deploying `config/lora_daemon.service` (see
that section for the manual install steps).

**Severity:** Medium — reduces LoRa transmission reliability (a sensor-change
cycle occasionally gets skipped), but does not corrupt data or crash the
device. IP/cellular uplink, when enabled, is unaffected and provides a
working fallback path.

---

## Symptom

Devices intermittently log this even when nothing else is obviously wrong —
no other process, no stale deploy, no leftover process from a previous run:

```
🔧 Creating new LoRaHandler instance...
ℹ️ LoRa serial port already owned by another process; skipping handler creation in PID 1291
⚠️ LoRa handler unavailable (serial port busy) — skipping transmission this cycle
```

First observed and diagnosed on UFO010 (2026-07-21 through 2026-07-22).

## Root cause

`tools/lora_handler_concurrent.py` implements `get_lora_handler()` as a
process-wide singleton, guarded by a module-level `threading.Lock`
(`_lora_handler_lock`) plus an OS-level `fcntl.flock()` on
`/run/lock/watercam-lora.lock` (intended as a cross-process guard: "only one
process may hold the serial port at a time").

**The `threading.Lock` half of this design assumes all callers live inside
one process.** They don't. TickTalk's own runtime (`ticktalkpython/`)
schedules and executes the compiled dataflow graph's nodes across
**multiple, genuinely separate OS processes** — not just threads within one
process. Confirmed directly via a live process-tree capture on UFO010 (see
Evidence below): a worker process held a fully-initialized `LoRaHandler`
(and its flock), while a **child of that same worker process** independently
tried to construct its own `LoRaHandler` and got `LoRaSerialPortConflict`.

Each of these OS processes gets its own copy of the Python interpreter's
memory, including a fresh `_lora_handler = None` and a separate
`_lora_handler_lock` object. The in-process singleton pattern therefore only
ever protects callers *within a single one* of these processes — it provides
no sharing or coordination across the several processes that may
concurrently want LoRa access. The OS-level flock on
`/run/lock/watercam-lora.lock` is the *only* thing that's actually
cross-process here, and it is working exactly as designed: it correctly
prevents two processes from simultaneously holding the physical serial port.
The problem is architectural, not a bug in the locking logic itself — this
is a resource (one physical UART) that only one owner can hold, guarded by a
synchronization primitive (a per-process singleton) that was never designed
to arbitrate across several real, independent owners.

## Evidence

Confirmed via three rounds of live diagnostics run directly on UFO010 (added
as temporary instrumentation, then removed once conclusive — see git history
around commits `89d2c0f`, `be226ca`, `1b21e84`, `7bfcce4` on the `main`
branch for the false leads that were investigated and ruled out along the
way, described below).

**1. Ruled out: duplicate Python module instances.** A live diagnostic
printed `sys.modules` membership and `id(_lora_handler_lock)` at the exact
moment of conflict:

```
bare='lora_handler_concurrent' in sys.modules=False
qualified='tools.lora_handler_concurrent' in sys.modules=True
this_module='tools.lora_handler_concurrent'
lock_id=548251657856   # identical across every conflict observed
```

Only one module copy, one lock object, every time. (A *real* instance of
this class of bug — two independent module copies from an inconsistent bare
vs. package-qualified import — was found and fixed separately in
`tools/lora_runtime_integration.py` (`89d2c0f`) and
`tools/debug_status_command.py` (`be226ca`). Both were genuine bugs, but
neither explained this specific symptom once fixed — the conflict kept
recurring after both fixes shipped.)

**2. Ruled out: a leftover process from a previous manual test run.** A
full, cold `sudo reboot`, confirming `ps aux | grep -i python` showed
nothing running, then launching `runrtm.py` as the very first thing —
still reproduced the conflict on the first attempt.

**3. Ruled out: a leaked file descriptor from a prior failed construction
within the same process.** `LoRaHandler.__init__` opened the serial port
before checking the flock but never closed it on the conflict path — a real
bug, fixed in `1b21e84` — but repeated `lsof /dev/ttyAMA5` /
`lsof /run/lock/watercam-lora.lock` checks (both from the user, manually,
and programmatically from inside the failing process at the exact instant
of conflict) never showed more than one holder at a time, and that holder
was always a plausible legitimate owner, never an orphaned handle.

**4. Ruled out: ModemManager or another external service.** `ModemManager`
runs on this device (for the Quectel cellular modem) and is known to
generically probe serial ports at boot. Checked
`journalctl -u ModemManager` for any mention of `ttyAMA5` around boot —
none found. Also checked for a second, competing `watercam.service` unit
(the codebase's own older/alternate service, called out in
`docs/FIELD_DEPLOYMENT_GUIDE.md` as something that must not run alongside
`ticktalk.service`) — not installed on this device.

**5. Confirmed: separate OS processes, not threads.** A programmatic
diagnostic ran `lsof` and `ps -eo pid,ppid,etimes,cmd` from inside the
failing process at the exact moment of conflict (zero timing gap — no
reliance on a human running commands after the fact). The process snapshot
showed:

```
PID    PPID ELAPSED CMD
1277     771     2   python runrtm.py -s0 --timeout=0 output/ticktalk_main.pickle 8080
1278    1277     1   python runrtm.py -s0 --timeout=0 output/ticktalk_main.pickle 8080
1279    1277     1   python runrtm.py -s0 --timeout=0 output/ticktalk_main.pickle 8080
1280    1277     1   python runrtm.py -s0 --timeout=0 output/ticktalk_main.pickle 8080
1281    1277     1   python runrtm.py -s0 --timeout=0 output/ticktalk_main.pickle 8080
1291    1280     0   python runrtm.py -s0 --timeout=0 output/ticktalk_main.pickle 8080
```

and, at that same instant:

```
🔬 lsof /dev/ttyAMA5:
COMMAND  PID USER   FD   TYPE DEVICE SIZE/OFF NODE NAME
python  1280   pi   24u   CHR 204,69      0t0  132 /dev/ttyAMA5

🔬 lsof /run/lock/watercam-lora.lock:
COMMAND  PID USER   FD   TYPE DEVICE SIZE/OFF NODE NAME
python  1280   pi   29wW  REG   0,24        0    5 /run/lock/watercam-lora.lock
```

PID 1280 (a worker process spawned by the top-level `runrtm.py` invocation,
1277) held both the port and the lock. PID 1291 — **a child of 1280 itself**
— was the one reporting the conflict. Two genuinely separate OS processes,
in a parent/child relationship, both wanting the same physical hardware at
the same time.

## Current mitigation (shipped, `7bfcce4`)

`get_lora_handler()` now retries the flock acquisition up to 3 times with a
1-second delay between attempts before giving up, instead of failing
immediately on the first `LoRaSerialPortConflict`. This does not fix the
architecture — it's a pragmatic bet that whichever process currently holds
the port is short-lived (a per-node worker process that exits once its task
completes) and will release the port within a couple of seconds, giving the
losing process a real chance to succeed on a subsequent attempt rather than
unconditionally skipping the whole transmission cycle. It measurably helps
(observed successes on retry during the investigation) but does not
guarantee success under sustained contention, and adds up to ~2s of latency
to the failure path.

## Implemented fix: single-owner daemon + IPC (2026-07-22)

Mirrors the codebase's existing precedent for exactly this class of problem,
`tools/segformer_daemon.py` (an expensive/exclusive resource wanted by code
that may run in more than one process — there, ONNX model load time and
memory residency; here, exclusive ownership of one UART): **one long-lived
daemon process owns the resource permanently; every other process talks to
it over a Unix domain socket instead of touching the resource directly.**

1. **`tools/lora_daemon.py`** — a persistent process that constructs exactly
   one `LoRaHandler` at startup (via the renamed
   `create_lora_handler_with_retry()` — the same retry-on-conflict
   construction logic that used to live directly in `get_lora_handler()`)
   and holds it for its entire lifetime. Listens on `/run/lora/lora.sock`
   (matching `/run/segformer/segformer.sock`'s convention) with a
   thread-per-connection accept loop, accepting newline-delimited JSON
   requests (`is_joined`, `queue_transmit`, `queue_binary_transmit`,
   `process_transmit_queue`, `transmit`, `get_queue_depth`,
   `get_size_limit`) and replying `{"status": "ok", "result": ...}` /
   `{"status": "error", "message": ...}`. Raw bytes values (e.g. a
   compressed flood bitmap) are base64-wrapped for the JSON transport by
   `_jsonify_bytes()`/`_unjsonify_bytes()` in `lora_handler_concurrent.py`.

2. **`config/lora_daemon.service`** — modeled directly on
   `config/segformer_daemon.service`: `RuntimeDirectory=lora`,
   `Before=ticktalk.service`, `Restart=on-failure`, an `ExecStartPost`
   health-check loop. **Not yet installed on any field device** — deploying
   this fix requires `sudo cp config/lora_daemon.service
   /etc/systemd/system/`, `sudo systemctl daemon-reload`,
   `sudo systemctl enable --now lora_daemon.service` on each unit, then
   confirming `/run/lora/lora.sock` exists before `ticktalk.service` starts.

3. **Client side**: `tools/lora_handler_concurrent.py`'s `get_lora_handler()`
   now returns a `LoRaHandlerClient` (connects to the socket fresh per call,
   mirroring `segformer_via_daemon()`'s style) or `None` if the socket is
   missing — preserving the existing "callers must check for `None`"
   contract every call site already implements. `compressed_encoding()`,
   `get_config_value()`/`.config`, are computed/read locally rather than
   proxied (pure, or a plain file read — no daemon round-trip needed).
   `get_size_limit()` **is** proxied (corrected from the original proposal
   below, which assumed it was stateless — it isn't: it reflects the mDot's
   live, radio-condition-dependent `AT+TXS` payload limit, refreshed by the
   daemon's listener thread, and `compress_bitmap()` in `ticktalk_main.py`
   depends on the real current value to size bitmaps correctly).

4. **Dual-singleton fix (prerequisite, landed first)**:
   `tools/lora_runtime_integration.py` had two independent
   `LoRaRuntimeManager` singleton factories (`get_runtime_manager()` and
   `get_lora_runtime_integration()`); consolidated into one, since incoming
   emergency-mode messages always route through `get_runtime_manager()`
   specifically (`_listen_loop()`'s fast path calls the module-level
   `set_parameter()`), so the daemon's emergency-mode callback (below) has
   to attach to that exact instance.

5. **Emergency-mode safety path**: `LoRaRuntimeManager.__init__` now accepts
   an optional `lora_handler=` — when the daemon passes its own real,
   already-constructed handler, incoming-message wiring
   (`set_runtime_callback()`/`start_listening()`) happens directly,
   in-process, right there; every other (client-mode) process's
   `LoRaRuntimeManager` does *not* wire that (decode() needs the real
   handler's own state and now runs in exactly one place — the daemon). The
   daemon publishes its manager via the new `set_runtime_manager()` so
   `get_runtime_manager()` calls from `_listen_loop()`'s fast path reach the
   same instance, then registers `register_update_callback('emergency_mode',
   ...)` calling `tools.wittypi_control.apply_emergency_schedule()` directly
   — this also fixed an independent, real, pre-existing bug: the old
   callback called the bare name `wittypi_emergency_control()` (a sibling
   top-level `@SQify` function) from inside a nested closure, which always
   raised `NameError` under TTPython's isolated per-function exec runtime,
   silently caught by an overly-broad `except Exception` — meaning the
   WittyPi shutdown-schedule-clearing safety path had likely never actually
   run in production.

6. **Parameter change-detection reload**: `LoRaRuntimeManager.get_parameter()`
   now re-reads `runtime_config.json` when its `os.stat().st_mtime` has
   advanced since last read (cheap in the common case — a wake-cycle-scale
   device, not a tight loop), diffs old vs. new per key, and fires
   `register_update_callback()` hooks for keys that changed — otherwise a
   change written by the daemon's manager would never be observed by any
   other process's cached `self.parameters`, and callbacks registered on
   client-side instances (e.g. `ticktalk_main.py`'s `lora_listener()`
   callbacks) would silently stop firing for remotely-driven changes now
   that `decode()` runs server-side.

## Testing

`tests/test_lora_daemon.py` — a real client/server round trip for every RPC
action (a test daemon bound to a `/tmp` socket, mirroring
`segformer_daemon.py`'s own `--socket /tmp/segformer_test.sock` convention),
`get_lora_handler()`'s socket-existence contract, `LoRaRuntimeManager`
daemon-mode vs. client-mode wiring, `set_runtime_manager()`/
`get_runtime_manager()` publishing, and the change-detection reload
(including the "own write doesn't self-trigger a duplicate callback" case).
`tests/test_singleton_and_filtering.py` was retargeted from
`get_lora_handler()` to `create_lora_handler_with_retry()` (which now holds
that exact retry/thread-safety/leaked-FD behavior, called only by the
daemon). `tests/test_name_resolution.py` gained an isolated-exec regression
test (see caveat below) proving the `on_emergency_mode_changed` `NameError`
was real pre-fix and is gone post-fix.

**Caveat repeated from elsewhere in this codebase's test suite**: tests that
call an `@SQify` function via `.__wrapped__()` use the real module
`__globals__` and do NOT reproduce TTPython's actual isolated per-function
exec runtime — they cannot catch "resolves via a module-level import/sibling
function reference, missing the required local import" bugs. The existing
`lora_listener()` name-resolution test used exactly this style and would not
have caught the `on_emergency_mode_changed` bug; the new test uses
`_exec_in_isolated_sq_namespace()` instead, which faithfully reproduces the
isolation.

## Remaining work

- **Deploy `config/lora_daemon.service` to field devices** — implemented but
  not yet installed anywhere; see step 2 above.
- **Live verification on a real device once deployed**: confirm no more
  "already owned by another process" (including re-running the same
  process-tree/`lsof` capture from the Evidence section above to confirm the
  conflict is genuinely gone, not just less frequent), and specifically
  confirm an incoming LoRa emergency-mode command still clears the WittyPi
  shutdown schedule promptly end-to-end on hardware.
- The retry-with-backoff mitigation (`7bfcce4`) in
  `create_lora_handler_with_retry()` remains as defense-in-depth for the
  daemon's own startup (e.g. a stale leftover process still releasing the
  port during a daemon restart) — no longer the primary mitigation now that
  only one process ever constructs a real `LoRaHandler`.

## Affected files (final state)

- **New**: `tools/lora_daemon.py`, `config/lora_daemon.service`,
  `tests/test_lora_daemon.py`
- **`tools/lora_handler_concurrent.py`** — `get_lora_handler()` now returns a
  `LoRaHandlerClient`/`None`; `create_lora_handler_with_retry()` (renamed
  from the old `get_lora_handler()`) holds the real construction/retry
  logic, called only by the daemon; `_encode_compressed_packet()` extracted
  as a module-level pure function shared by both the real handler and the
  client; `LoRaHandler.get_queue_depth()` added
- **`tools/lora_runtime_integration.py`** — dual singleton consolidated;
  `LoRaRuntimeManager(lora_handler=...)` for daemon-mode construction;
  `set_runtime_manager()`; change-detection reload in `get_parameter()`
- **`tools/wittypi_control.py`** — `apply_emergency_schedule()` (shared,
  plain-bool-callable logic extracted from `wittypi_emergency_control()`)
- **`ticktalk_main.py`** — `wittypi_emergency_control()` now a thin wrapper;
  `lora_listener()`'s `on_emergency_mode_changed` calls
  `apply_emergency_schedule()` directly; `check_lora_availability()`
  repointed to `get_runtime_manager()`
- **Unchanged**: `tools/lora_store_forward.py` — its existing "mDot not
  joined" store-and-forward path in `ticktalk_main.py` (checked via
  `handler.is_joined()` before any `queue_transmit()` call) is unaffected by
  this change and still applies. A daemon that's unreachable for an entire
  cycle (`get_lora_handler()` returns `None`) skips that cycle's
  transmission entirely — the same behavior as before this daemon existed
  (`ticktalk_main.py:288-293`'s pre-existing `None` check), not a regression;
  `LoRaHandlerClient.queue_transmit()`/`queue_binary_transmit()` do not
  additionally enqueue to store-and-forward on a mid-cycle RPC failure,
  since `enqueue()`'s hex-payload shape doesn't cleanly compose at that
  layer for both the dict (`queue_transmit`) and pre-encoded
  (`queue_binary_transmit`) cases — narrow enough (daemon reachable at
  `is_joined()` but not moments later) not to be worth forcing.

Reference implementation this mirrors: `tools/segformer_daemon.py` +
`config/segformer_daemon.service`

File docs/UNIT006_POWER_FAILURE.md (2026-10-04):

# Unit 006 Power Failure (September 2026)

| | |
|---|---|
| **Unit** | ufo-01-01-006 (Pi 4B rev 1.5, Witty Pi 4, Voltaic V50, 20 W panel) |
| **Failed** | 2026-09-14, 21:03 |
| **Bench work** | 2026-09-29 to 2026-10-02 |
| **Fixes** | SU-WaterCam [#97](https://github.com/mandeeps/SU-WaterCam/pull/97) and [#98](https://github.com/mandeeps/SU-WaterCam/pull/98) |

006 went silent in the field on 14 September and never woke again on its own,
even after its solar panel would have recharged the battery. This document
covers what the bench tests and the unit's own logs showed, the most likely
chain of events, the software fixes, and what is still open.

Confidence labels: **Confirmed** means measured or seen directly. **Likely**
means it fits all the evidence but isn't proven. **Open** means not yet tested.

## Summary

- **What happened:** during the 21:00 wake on 14 September, 006 lost power
  abruptly at 21:03, mid-capture. It made one brief start on 20 September at
  20:10, died within a minute, and stayed off until it was brought in on
  29 September.
- **Why it stayed dead:** once the Witty Pi has been without power past its
  alarm time, it never starts the Pi later and never sets a new alarm. The
  only way back is power returning with "Default ON", which boots the Pi
  straight onto a nearly empty battery. 006's boot also left its next wake
  unset for the first ~55 s, during the heaviest load of the cycle.
- **Underlying cause:** marginal power. There was an energy shortfall as the
  days shortened, plus brownouts at wake time: from August, most wakes started
  with the Witty Pi itself losing power. The V50 also sags badly while charging
  through its top USB-C port. The bench work was initially misled by a faulty
  "known-good" charger.
- **Fixes:** [#97](https://github.com/mandeeps/SU-WaterCam/pull/97) sets the
  next wake 15–17 s after boot instead of 46–55 s, and holds the main program
  until it is set. [#98](https://github.com/mandeeps/SU-WaterCam/pull/98) puts
  a unit back to sleep for at least 2 h when a boot follows a power cut, so the
  battery can recharge. Both were tested on 006.
- **Still open:**
  - whether the V50 sags while charging from a real panel through its side
    solar port
  - whether a full drain on panel power recovers by itself
  - whether other units show the same pattern
  - a Pi-side voltage drop under full load

## Field timeline from 006's logs

The journal had not persisted since April, so this comes from
`~/wittypi/wittyPi.log` and the timestamps of files on disk.

| When | Event | Evidence |
|---|---|---|
| Jun → Sep | Wakes that start with the Witty Pi itself losing power ("power supply newly connected") climb from rare to most wakes, at every hour, including midday. | June 33 vs 210 scheduled, July 65 vs 212, August 110 vs 75, September 76 vs 17 |
| 09-14 21:00:17 | Wake starts with "power supply newly connected". | Witty Pi log |
| 21:01–21:03 | Captures run normally; segmentation finishes at 21:02:24. | Files in `images/20260914-210100`, `-210200` |
| **09-14 21:03** | **Abrupt power loss mid-capture.** The last file written is `images/20260914-210300/IMG_0000.pgm`. | 668 zero bytes at the end of the Witty Pi log (lines never written to disk); last ext4 shutdown unclean |
| 09-14 23:00 → 09-20 | No wakes for six days, including sunny days. | Nothing in the log; no files |
| 09-20 20:10:18 | Power returns ("newly connected"). The Pi boots and dies within about a minute; the last file is written at 20:09:49. | Witty Pi log; `runtime_config.json` and Tailscale files |
| 09-29 | Retrieved and brought to the lab. The V50 shows 3 of 4 bars. | Bench notes |

## Findings

### Bench power path, 005 vs 006

- **006's bench charger was faulty, not "known-good".** *Confirmed.*
  - **On it:** 006 throttled to 600 MHz in most samples and logged repeated
    under-voltage. Segmentation ran about 2.4× slower than on 005 (2.9 s vs
    1.2 s).
  - **On a new charger:** no under-voltage, no throttling, and 1.31 s
    inference at 1800 MHz, which is 005's time scaled by the clock difference.
  - **Consequence:** the 2026-09-29 test that seemed to clear the V50 had used
    this faulty charger, so its conclusion did not hold.
- **The Witty Pis are identical.** *Confirmed.* Both have board ID 0x26,
  firmware 0x07 and scripts v4.21, with the same calibration offsets, and a
  similar input-to-output drop (130–155 mV/A).
- **Software changes alone couldn't fix a weak supply.** *Confirmed.* Stock
  clocks and disabling Bluetooth helped only a little. On the faulty charger,
  only 1 inference thread avoided brownouts, and it was no faster than the
  throttled 4-thread runs. On a good supply, 4 threads is fastest and safe on
  both units.

How fast the Witty Pi's input voltage falls as current rises (fitted slope, in
mV per amp; lower means a stiffer supply). Compare these with each other rather
than as absolute volts, because they come from the Witty Pi's own sensor.

| Supply | mV/A |
|---|---|
| 005, its usual charger | 2 |
| 006, V50 not charging (one A port, stock cable) | 29 |
| 006, V50 + Y-adapter, charger in side port (probably not charging) | 59 |
| 006, new charger | 71 |
| 006, old "known-good" charger | 260 |
| 006, V50 charging via top USB-C port, one A port | 338 |
| 006, V50 charging via top USB-C port, through the Y-adapter | 411 |

The Pi flags under-voltage near 4.63 V. On the worst supplies, the Witty Pi's
output fell to about 4.3 V at the 1.2 A of a capture cycle.

### Voltaic V50 battery

- **Charging through the top USB-C port sags the output and cuts it on
  plug/unplug.** *Confirmed.*
  - **The sag:** while charging through that port, the no-load voltage drops
    about 0.2 V and sags about 0.3 V per amp, enough for under-voltage even at
    idle.
  - **The cut-outs:** plugging in or unplugging a charger at that port reset
    006 both times.
  - **Field relevance:** field units don't charge through this port, so it is a
    bench hazard rather than the field cause.
- **The side solar port doesn't reset the output, but its sag under real solar
  charging is untested.** *Open.*
  - **Plugging in and out** caused no resets.
  - **Why the load tests don't count:** the solar input holds its input at
    5.2 V (matching the panel's 5.21 V maximum-power point), and a 5.0–5.1 V
    wall charger probably can't reach that. That fits what happened: the V50
    drained completely overnight with that charger in the side port while
    running 006 at idle. So the side-port load tests probably weren't charging
    at all.
- **The solar input is capped at about 10 W.** *Confirmed from spec.* The 20 W
  panel peaks at 23 W (5.21 V, 4.46 A), but each V50 solar input accepts at
  most 2 A.
- **The Y-adapter isn't the problem, and may help.** *Confirmed.*
  - **Its cost:** only about 30–45 mV per amp under field conditions.
  - **Why it helps:** each A port is rated 2 A (3 A combined), and with the
    modem active, peak draw reached 2.06–2.21 A (averaged readings). Keep it in
    the field for now.
- **The V50 restores its output after recharging.** *Confirmed.* The product
  is designed to do this, and unit 007 recovered this way through a winter. A
  V50 that stayed off is therefore unlikely to explain 006's six days.

### Witty Pi behaviour

- **The next wake was set about 55 s into each boot.** *Confirmed.*
  - **Why:** the daemon only sets alarms after `beforeScript.sh` finishes, and
    ours ran `syncTime.sh`, which sleeps 30 s and then waits for network time.
  - **Measured:** 46 s on the bench, and about 55 s in the field, while the
    cameras, modem and inference were already running.
- **A missed alarm is gone for good.** *Confirmed by earlier team testing.*
  - **The rule:** if the Witty Pi has no power when the alarm time comes, it
    never starts the Pi later and never sets a new alarm.
  - **What does survive:** its clock keeps time through outages (it had the
    correct time after the six-day gap). An alarm that hasn't been missed also
    survives a 60-second power cut (tested 2026-10-02).
- **The Witty Pi only cuts power once the Pi has sent "system is up".**
  *Confirmed during testing.*
  - **What happened:** a Pi that powered off before the daemon sent SYS_UP on
    GPIO-17 stayed halted with the power on (steady red LED). The Witty Pi
    still counted it as running, so it missed its alarm, and only a long button
    press recovered it.
  - **The contrast:** a shutdown about one second after SYS_UP was cut cleanly.
- **The "default on" delay goes up to only 10 s.** *Confirmed.* That's too
  short to let a battery recharge. 006 is set to 10 s, which only lets the
  V50's output settle before the boot surge.

### Raspberry Pi side

- **Under full load the Pi browns out even on a healthy supply.** *Confirmed.*
  - **What was seen:** with camera, modem pings, inference and 4-core stress
    running, the Pi flagged under-voltage in 82 of 89 samples while the Witty
    Pi still read about 4.70 V.
  - **Why:** fast spikes from the camera and modem transmit bursts, which the
    Witty Pi's averaged readings can't see, plus the drop across the GPIO
    extension header.
- **Repeated on the field supply.** *Confirmed.* On the V50 with the
  Y-adapter (the field wiring), the full-load test on 2026-10-02 again flagged
  under-voltage early in the load (`0x50005`). The Witty Pi output read 4.64 V
  at 1.82 A, and the CPU reached 58–62 °C at 2000 MHz.
- **Both units are overclocked.** *Confirmed.*
  - **Clock:** both have `arm_freq=2000` with `arm_boost=1` (stock is 1800).
    006 was set back to 2000 on 2026-10-01 at 21:26.
  - **Kernel:** 006 runs an `rpi-update` kernel (6.18.54-v8+); 005 runs the
    packaged 6.18.29.

### Energy budget

*Likely:* positive on average, but thin across overcast spells.

- **Use:** about 9 wakes a day and about 2.1–2.4 h of scheduled on-time
  (June–August) comes to roughly 12–15 Wh/day from the pack.
- **Solar input:** about 20–30 Wh on a clear day at the 10 W input cap, but
  only about 3–6 Wh overcast.
- **Storage:** the pack's 48 Wh is about 3 days with no sun.

Only 20–37 wakes a month ended with a logged clean shutdown, so actual on-time
may have been higher.

### Timekeeping quirks that matter

- **The system clock is stale early in every boot.** *Confirmed.*
  - **Why:** until the Witty Pi daemon copies its clock in, about 10 s into
    boot, the system clock holds the last saved time, often the previous
    shutdown.
  - **Impact:** two first versions of the fixes made wrong decisions because of
    this. Anything that runs early must use the Witty Pi clock or a per-boot
    log mark.
- **The field schedule runs an hour late in summer.** *Confirmed.*
  `runScript.sh` steps through the schedule in raw seconds from `BEGIN`, and
  the field schedule's `BEGIN` is in January. So during daylight saving time
  the wakes land at 07:00 … 23:00 rather than 06:00 … 22:00, as 006's log
  shows.

## Most likely failure chain

1. **Power margins shrank through late summer.** *Likely.* Shorter days and
   overcast spells against about 12–15 Wh/day of use, with an input capped at
   about 10 W.
2. **Wakes started browning out.** *Confirmed.* From August, most wakes began
   with the Witty Pi itself losing power at the boot surge, then recovering.
3. **On 09-14 at 21:03, power was lost mid-capture.** *Confirmed.* This was
   after sunset, with the pack at its lowest point of the day. The alarm lines
   from that boot were never written to disk, so whether the next wake had been
   set is unknown.
4. **The Witty Pi was without power past its alarm, so it never woke the Pi.**
   *Likely.* A missed alarm never fires later, so recovery depended entirely on
   power returning.
5. **When power returned, "Default ON" booted the Pi onto a nearly empty
   pack.** *Likely.*
   - **The evidence:** the 09-20 boot died within a minute.
   - **Unconfirmable:** earlier attempts that died within ~30 s would leave no
     trace on disk. A repeating restart loop that kept draining the pack would
     fit the gap, but can't be confirmed.

## Fixes

| Change | What it does | Status |
|---|---|---|
| [#97](https://github.com/mandeeps/SU-WaterCam/pull/97) (`early-wittypi-alarm`) | `config/wittypi/beforeScript.sh` syncs network time in the background unless the daemon reported a bad clock, so the next wake is set 15–17 s after boot (was 46–55 s). `ticktalk.service` waits up to 120 s (`tools/wait_for_wittypi_schedule.py`) for "Schedule next startup", then starts regardless. | Tested on 006; open |
| [#98](https://github.com/mandeeps/SU-WaterCam/pull/98) (`recovery-boot`, stacked on #97) | After a power cut, `wittypi-recovery.service` (`tools/recovery_boot.py`) sets the next schedule slot at least 2 h ahead and powers off before the main program starts. A boot within 20 min after the previous wake counts as a scheduled wake that browned out, and runs normally. It powers off only after the daemon's "system is up" signal, takes times from the Witty Pi clock, and uses `wittypi-boot-mark.service` to tell this boot's log lines apart. Any failure runs the normal cycle. Settings are under `recovery_boot` in `runtime_config.json`. | Tested on 006; open |
| Witty Pi on 006 | "Default ON" kept; default-on delay set to 10 s. | Applied |
| Power logger on 006 | `tools/powerlog.py` run by `config/powerlog.service` (in this repo since the power-tools PR; 006 still runs its earlier copy from `~/powerlog/`). Once a minute it records Witty Pi voltages and current, throttle flags and the Witty Pi clock, forced to disk so the last reading survives a power cut, plus a marker line per boot. | Running |
| Bench charger | The faulty charger on 006 was replaced. | Done |

### Tests run on 006

A stub stood in for the main program in these tests, because the real one
uploads to the production server.

| Test | Result |
|---|---|
| Reboot with a schedule, three times | Next wake set at 15, 17 and 16 s; main program started only after it was set |
| Two real scheduled power cycles | Witty Pi cut power and restored it on its alarms; next wake set at 17 s each time |
| Clock deliberately invalidated | Waited for network time, set the alarms at 46 s, restored the Witty Pi clock |
| Alarm survives a 60 s power cut | Booted on time: "scheduled startup is due" |
| Power restored with no wake due | Waited for "system is up", set a wake, powered off (red LED off), woke on the alarm, normal cycle |
| Power restored just after a scheduled wake | Counted as a wake that browned out; normal cycle, stayed on |
| Button press and reboot | Normal cycle |
| Power cut during full load at a scheduled wake, on the V50 with the Y-adapter (load: segmentation loop, camera, 4-core stress, cellular pings; 1.6–1.8 A) | Next wake (22:56) set before the load started. After replug: power restore before that wake, so recovery waited for "system is up", re-set 22:56 and powered off 7 s after boot. Woke at 22:56 on the alarm and ran the full load again |

## Recommendations for field units

- **Keep "Default ON"** on every Witty Pi, with the 10 s delay. "Default off"
  would leave a unit off after any outage that ran past its next wake.
- **Merge #97, then #98, and install both by hand on each unit.** A
  `git pull` alone doesn't install them: the units and `beforeScript.sh` must
  be copied, and `recovery_boot.enabled` set to `true`. See
  `FIELD_DEPLOYMENT_GUIDE.md` for the commands.
- **At deployment, press the Witty Pi button** after connecting power.
  Connecting power alone now just sets an alarm and goes back to sleep.
- **Lower the peak current:** stock clocks rather than `arm_freq=2000`, and
  keep modem uploads from overlapping capture and inference.
- **Match the schedule to the season,** and consider moving `BEGIN` into
  daylight saving time, or dropping the 23:00 wake, to remove the summer hour
  shift.
- **Keep the Y-adapter,** and never charge through the V50's top USB-C port
  while it powers a unit.
- **Check the GPIO extension header's voltage drop** with a multimeter during a
  capture.

## Open questions and next tests

- **Solar charging through the side port:** a load test on 006 while the V50
  charges from the real panel through the side port, in sun. This is the main
  open question for the field.
- **Drain and recovery on panel power:** a full drain with only the panel
  connected, the power logger and the recovery rule turned on, to see the
  cut-out and recovery on the logger's timeline.
- **The other field units:** a compact summary of the Witty Pi logs from
  008–011 (wakes after a power loss; boots that never set a next wake). This
  costs a few KB of cellular data per unit, so it's waiting for approval.
- **Unit 007:** whether it was overclocked or had a modem and Y-adapter during
  the winter it survived.
- **006's configuration:** who set it back to `arm_freq=2000`, and whether to
  return it to the packaged kernel. Also remove the redundant
  `dtoverlay=miniuart-bt` line.

## Current state of the bench units

**006:**
- **Code and services:** SU-WaterCam checkout on the `recovery-boot` branch,
  with the boot-mark and recovery units installed and enabled.
  `recovery_boot.enabled` is `false`, so bench plugging doesn't put it to
  sleep. `ticktalk` is disabled.
- **Witty Pi:** new `beforeScript.sh` (the old one is in
  `beforeScript.sh.orig`); the previous unit is saved as
  `ticktalk.service.pre-pr97`. "Default ON" with the 10 s delay, no alarms set,
  no `schedule.wpi`.
- **Power logger:** running.
- **Test scripts:** the earlier `~/loadtest.sh` and `~/modemtest.sh`, now
  `tools/power_load_test.sh` in this repo.

**005:** unchanged. Its usual charger, `arm_freq=2000`, packaged kernel
6.18.29; no resets or under-voltage during testing.

### Reusable test tools

- **`tools/power_load_test.sh`** loads the node in phases (idle, 5
  segmentations, 4-core stress, cool-down), sampling the Witty Pi and the Pi's
  throttle flags every 0.3 s. `--modem` adds a ping phase and a full phase
  (segmentation, camera, stress and tiny pings over `wwan0`, about 10 KB of
  data, counted at the end). It replaces the `loadtest.sh` and `modemtest.sh`
  used during this investigation.
- **`tools/power_test_report.py`** prints the per-phase summary and fits
  voltage against current, giving the mV/A figures above. It also reads the
  power logger's CSV.
- **`tools/powerlog.py`** with **`config/powerlog.service`** logs once a
  minute, fsynced, with a marker line per boot.

```bash
tools/power_load_test.sh                  # on the node, on the supply under test
tools/power_load_test.sh --modem          # add the cellular phases
python3 tools/power_test_report.py ~/powerlog/powerlog.csv
```

Related earlier work: segformer_5band PR #1 (merged), SU-WaterCam PR #96
(remote debug status, open).

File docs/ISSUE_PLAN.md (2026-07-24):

# Issue Implementation Plan

Detailed implementation plan for all open GitHub issues, organised by tier.

---

## Status Summary

| Issue | Title | Status |
|---|---|---|
| #2 | Cached registration transform not used | **Needs path-normalization fix** |
| #16 | Use IP when LoRa not available | **Blocked** — IP branch not yet merged |
| #17 | Integrate calibration workflow | **Tooling exists** — extrinsics + CLI docs pending |
| #18 | Calibration applied before registration | **Needs implementation** — undistort not wired in |
| #19 | Downstream LoRa command handling | **Needs cleanup** — duplicate method, debug noise |
| #20 | IP command handling | **Blocked** — IP branch not yet merged |
| #21 | Unit ID in photo metadata | **Already done** — `_read_device_id()` in `add_metadata.py` |
| #31 | Serial port opened at import time | **Done** — `fix/issue-31-32-serial-port` |
| #32 | Serial port never closed | **Done** — `fix/issue-31-32-serial-port` |
| #33 | Race on serial readline | **Done** — `fix/issue-33-listen-lock` |
| #34 | GPS import crash | **Done** — `fix/issue-34-gps-import` |
| #35 | Bare `except:` in lora_functions | **Done** — `fix/issue-35-lora-except` |
| #36 | Config file race condition | **Done** — `fix/issue-36-config-file-lock` |
| #37 | LoRa payload bounds checking | **Done** — `fix/issue-37-lora-bounds-check` |
| #38 | Pickle file integrity | **Done** — `fix/issue-38-pickle-checksum` |
| #39 | GPS altitude on 2D fix | **Done** — `fix/issue-39-gps-mode-check` |
| #40 | Picamera2 thread safety | **Needs implementation** |
| #41 | IMU warmup silent failure | **Needs implementation** |
| #42 | LoRa callback re-entrancy | **Done** — `fix/issue-42-callback-reentrancy` |
| #43 | AHT20 CSV writes strings not floats | **Needs implementation** |
| #44 | GPS return type inconsistency | **Already done** — fixed as part of #34 |
| #45 | Hardcoded `/home/pi/SU-WaterCam/` paths | **Needs implementation** |
| #46 | Battery estimation | **Done** — merged to main |

---

## Tier 1 — Critical (already implemented in prior session)

Issues #31, #32, #33, #34, #35, #36, #37, #38, #39, #42 — see branch list above.

---

## Tier 2 — High priority (already implemented in prior session)

Issues #42, #39, #37 — see branch list above.

---

## Tier 3 — Medium priority

### #40 — Picamera2 thread safety

**File:** `tt_take_photos.py` lines 153–176

**Problem:** `take_two_photos()` reads `sq_state["picam"]` and initialises `Picamera2()` without a lock. Two concurrent calls can both observe `picam is None` and double-initialise.

**Fix:**
1. Add `import threading` near top of file.
2. Add module-level `_camera_lock = threading.Lock()`.
3. Replace the bare `if picam is None:` block with:

```python
with _camera_lock:
    if sq_state.get("picam") is None:
        picam2 = Picamera2()
        config = picam2.create_still_configuration(main={"format": "RGB888", "size": (2592, 1944)})
        picam2.configure(config)
        sq_state["picam"] = picam2
picam2 = sq_state["picam"]
```

**Branch:** `fix/issue-40-camera-lock`

---

### #41 — IMU warmup silent failure

**File:** `tools/bno055_imu.py` lines 31–40 (in `_get_sensor()`) and lines 78–86 (in `get_orientation()`)

**Problem:** Both warmup loops exit silently after 20 iterations (~2 s) with no log message if fusion never initialised.

**Fix:**
1. Add `import logging` and `logger = logging.getLogger(__name__)` at module top.
2. After each warmup loop, check if `euler` is still invalid and emit a warning:

```python
# in _get_sensor() after the warm-up for loop:
e = getattr(_sensor, 'euler', None)
if not (isinstance(e, tuple) and any(v not in (None, 0.0) for v in e)):
    logger.warning("BNO055 warmup timed out — fusion not yet initialised")

# in get_orientation() after the retry for loop:
if not (isinstance(e, tuple) and any(v not in (None, 0.0) for v in e)):
    logger.warning("BNO055 get_orientation: data still zero after retry")
```

**Branch:** `fix/issue-41-imu-warmup`

---

## Tier 4 — Low priority

### #43 — AHT20 CSV writes strings not floats

**File:** `tools/aht20_temperature.py` lines 41–43

**Problem:** The `record_csv()` function writes formatted strings (`'23.4 C'`, `'55.2 %'`) into the CSV `Temp` and `Humidity` columns. Any downstream analysis that reads the CSV expecting numeric values will fail to parse.

**Fix:**
```python
# Before:
row = {'Time': datetime.now().strftime('%Y%m%d-%H%M%S'),
       'Temp': '%0.1f C' % sensor.temperature,
       'Humidity': '%0.1f %%' % sensor.relative_humidity}
print(row)

# After:
temp_c = round(float(sensor.temperature), 1)
hum_pct = round(float(sensor.relative_humidity), 1)
print(f"Time: {datetime.now().strftime('%Y%m%d-%H%M%S')}  Temp: {temp_c} C  Humidity: {hum_pct} %")
row = {'Time': datetime.now().strftime('%Y%m%d-%H%M%S'),
       'Temp': temp_c, 'Humidity': hum_pct}
```

Also fix the hardcoded `FILE` path in the same function (see #45 below).

**Branch:** `fix/issue-43-sensor-types`

---

### #45 — Hardcoded `/home/pi/SU-WaterCam/` paths

**Problem:** Nine files contain literal `/home/pi/SU-WaterCam/` paths that break on any non-`pi` deployment.

**Strategy:** Import `_infer_repo_root()` from `button_hold_camera.py` or replicate the same pattern using `Path(__file__).resolve()` + `WATERCAM_REPO` env-var override (matching the existing pattern in `button_hold_camera.py`).

For **`tools/`** files (one level below repo root):
```python
from pathlib import Path
import os
_REPO_ROOT = Path(os.environ.get("WATERCAM_REPO", str(Path(__file__).resolve().parent.parent)))
```

For **root-level** scripts:
```python
from pathlib import Path
import os
_REPO_ROOT = Path(os.environ.get("WATERCAM_REPO", str(Path(__file__).resolve().parent)))
```

**Files and specific changes:**

| File | Line(s) | Change |
|---|---|---|
| `tools/bno055_imu.py` | 92 | `OFFSET_PATH = str(_REPO_ROOT / "data" / "imu_offsets.txt")` |
| `tools/bno08x_imu.py` | 51 | same pattern |
| `tools/aht20_temperature.py` | 33 | `FILE = str(_REPO_ROOT / "data" / "temp_humidity.csv")` |
| `tools/take_nir_photos.py` | 47, 50, 52, 55 | `str(_REPO_ROOT / "capture")`, etc. |
| `tools/take_nir_photos.py` | 132 (main guard) | `filepath = str(_REPO_ROOT / "images" / "")` |
| `tools/watercam.py` | 30, 32–34 | `_REPO_ROOT / "images"`, segformer paths |
| `tools/take_photo.py` | 33 (main guard) | `filepath = str(_REPO_ROOT / "images" / "")` |
| `ticktalk_main.py` | 633, 640 | `str(Path(os.environ.get("WATERCAM_REPO", ...)) / "images" / date)` |
| `ticktalk_main.py` | 658–661 | segformer Python/script paths from env vars |
| `button-service-gpiozero.py` | 15 | `str(_REPO_ROOT / "tools" / "take_nir_photos.py")` |

**Service files** (`config/*.service`): left as-is — these are deploy-time config files that require site-specific paths.

**Branch:** `fix/issue-45-hardcoded-paths`

---

## Tier 5 — Enhancement / Research

### #2 — Cached registration transform: trailing slash edge case

**File:** `tools/coreg_multiple.py` lines 152–153 and 165–166

**Problem:** `os.path.dirname("path/to/dir/")` returns `"path/to/dir"` (same dir), not the parent. When `directory` ends with `/`, `save_transform_parameters` writes the cache into the wrong location relative to `load_transform_parameters`.

**Fix:**
```python
# save_transform_parameters(), line 152:
parent_directory = os.path.dirname(os.path.normpath(directory)) or os.path.normpath(directory)

# load_transform_parameters(), line 165:
parent_directory = os.path.dirname(os.path.normpath(directory)) or os.path.normpath(directory)
```

**Branch:** `fix/issue-2-transform-cache`

---

### #17 — Integrate calibration workflow

**Status:** `tools/camera_calibration.py` (a copy of the canonical calibration script from this project's separate Georeferencing codebase, not published on GitHub) computes + saves intrinsics (`K`/`D`). `tools/camera_calibration_legacy.py` and `tools/generate_calibration_chessboard.py` are deprecated (see notices at top of each file). Gap is extrinsic collection and a guided workflow doc.

**Remaining work (out of scope for code fixes — tracked in issue):**
- Extrinsic parameter collection tooling
- Installation guide documenting the calibration capture procedure

**No code change needed in this cycle.** Tracked as documentation/workflow gap.

---

### #18 — Apply calibration before registration

**File:** `tools/coreg_multiple.py`

**Problem:** `coreg_multiple.py` never calls `cv2.undistort()`. The `camera_calibration.json` produced by `tools/camera_calibration.py` is ignored.

**Fix:** Add `_undistort_if_calibrated(image, calib_path)` helper and call it on both optical frames before passing them to `mutual_information_registration()`.

```python
def _undistort_if_calibrated(image: np.ndarray, calib_path: str) -> np.ndarray:
    if not os.path.exists(calib_path):
        return image
    try:
        with open(calib_path) as f:
            cal = json.load(f)
        mtx = np.array(cal["camera_matrix"])
        dist = np.array(cal["dist_coefficients"])
        h, w = image.shape[:2]
        new_mtx, _ = cv2.getOptimalNewCameraMatrix(mtx, dist, (w, h), 1, (w, h))
        return cv2.undistort(image, mtx, dist, None, new_mtx)
    except Exception as e:
        print(f"Warning: calibration load failed ({e}), skipping undistort")
        return image
```

Call site in `mutual_information_registration()` (and `apply_cached_transform()`):
```python
calib_path = os.path.join(os.path.dirname(fixed_image_path), "camera_calibration.json")
fixed_image_cv = _undistort_if_calibrated(fixed_image_cv, calib_path)
moving_image_cv = _undistort_if_calibrated(moving_image_cv, calib_path)
```

Also add `--calibration-file` CLI argument to allow specifying a non-default calibration JSON.

**Branch:** `feature/issue-18-apply-calibration`

---

### #19 — LoRa downstream command dispatch cleanup

**File:** `tools/lora_runtime_integration.py`

**Problems:**
1. `process_lora_payload` is **defined twice** (Python keeps the second; first is dead code). The first stub (lines ~219–221 on main) returns `self.process_lora_command(payload)` which calls the old 2-argument method with only 1 arg — a `TypeError` at runtime.
2. `DEBUG:` prefix in `process_lora_payload` will print every received payload in production.
3. `_init_lora_handler` emits verbose emoji debug prints on every startup.
4. The import fallback block emits debug prints including full file listings.

**Fix:**
1. Remove the first `process_lora_payload` definition entirely.
2. Remove `print(f"DEBUG: ...")` lines from `process_lora_payload` and `_apply_command_tlv`.
3. Replace emoji `print()` calls in `_init_lora_handler` with a single `print("LoRa runtime integration initialised")` on success and `print("LoRa unavailable: ...")` on failure.
4. In the import fallback block, remove the verbose directory listing prints; keep only the `raise` on final failure.

**Branch:** `fix/issue-19-lora-dispatch`

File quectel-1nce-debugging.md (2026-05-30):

# Quectel EC25 + 1NCE SIM Debugging Reference

## Symptoms that led here

- Modem visible in `mmcli -L` but registration state stuck at `searching`
- `packet service state: detached` despite good signal
- `mmcli --simple-connect` returning `NetworkTimeout` or `Timeout was reached`
- No change after reboot or ModemManager restart

---

## Debugging procedure

### 1. Check ModemManager state

```bash
mmcli -m 0 | grep -E "state|packet|registration|signal"
```

Key fields to check:
- `state` should reach `registered` before a connection is possible
- `registration: searching` with `packet service state: detached` means the modem is not attaching to any network
- Signal quality percentage gives a rough sanity check

### 2. Stop ModemManager and NetworkManager

ModemManager holds the AT ports open. Stop both before using tio directly.

```bash
sudo systemctl stop ModemManager NetworkManager
```

### 3. Connect to the AT port

The Quectel EC25 exposes multiple ttyUSB ports. Their roles:

| Port | Role |
|---|---|
| ttyUSB0 | ignored by ModemManager |
| ttyUSB1 | GPS NMEA output |
| ttyUSB2 | AT commands |
| ttyUSB3 | AT commands |

```bash
tio -b 115200 /dev/ttyUSB2
```

Exit tio with `ctrl-t q`.

### 4. Key AT commands

**Registration status (GSM/UMTS):**
```
AT+CREG?
```
Response format: `+CREG: <n>,<stat>`
- stat 0 = not registered, not searching
- stat 1 = registered, home
- stat 2 = searching
- stat 3 = registration denied
- stat 5 = registered, roaming

**Registration status (LTE):**
```
AT+CEREG?
```
Same stat values as above. Use this for LTE/4G status.

**Signal quality:**
```
AT+CSQ
```
Returns `+CSQ: <rssi>,<ber>`. RSSI values: 0-9 very weak, 10-14 marginal, 15-19 good, 20-30 strong, 99 no signal.

**PDP context / APN:**
```
AT+CGDCONT?
```
Context 1 should show `iot.1nce.net` for 1NCE SIMs. If it shows something else or is blank, the attach APN is wrong.

**Operator selection mode:**
```
AT+COPS?
```
Mode 0 = automatic (correct). Mode 1 = manual (may be stuck on a specific operator).

**Force registration onto a specific operator:**
```
AT+COPS=1,2,"310410"
```
310410 is AT&T. This will either register or return an error code indicating why registration is being rejected. Useful for getting a specific failure reason rather than staying silently in searching state.

**Band configuration:**
```
AT+QCFG="band"
```
Returns `0x<gsm_bands>,0x<lte_bands>,0x<tds_bands>`. For AT&T US, LTE bands 2, 4, and 12 (hex `0x80a`) are the primary ones.

**SIM IMSI:**
```
AT+CIMI
```
Returns the 15-digit IMSI. For 1NCE SIMs this starts with `901405`. Use this to identify the SIM if you have multiple.

**SIM ICCID:**
```
AT+CCID
```
Returns the ICCID (the number printed on the physical SIM card). Use this to look up the SIM in the 1NCE portal at https://portal.1nce.com.

---

## 1NCE SIM-specific checks

1NCE SIMs have a **lifetime data limit of 500MB**. Once exhausted, the SIM will still attempt registration but the network will reject packet data attachment. The modem will show good signal and correct APN configuration but stay in `searching`/`detached` state.

**Check SIM status:**
- Log into https://portal.1nce.com
- Find the SIM by ICCID (from `AT+CCID`)
- Check: activation status, data usage, roaming status

**1NCE IMSI prefix:** `901405` (MCC 901, MNC 40)

**1NCE US roaming partner:** AT&T (operator code `310410`)

If the SIM shows as active with remaining data but the modem still won't register, try forcing registration onto AT&T explicitly with `AT+COPS=1,2,"310410"` to get a specific rejection error code.

---

## Trixie-specific issues

After upgrading from Bookworm to Trixie (systemd 257, ModemManager 1.24):

**Interface rename:** systemd renames `wwan0` to a predictable name like `wwp1s0u1u3i4`. Fix with a `.link` file:

`/etc/systemd/network/10-wwan.link`
```ini
[Match]
Driver=qmi_wwan
Path=platform-fd500000.pcie-pci-0000:01:00.0-usb-0:1.3:1.4

[Link]
Name=wwan0
```

Confirm the correct `Path=` value with:
```bash
udevadm info /sys/class/net/<interface> | grep "^E: ID_PATH="
```

**Initial EPS bearer APN:** Newer ModemManager is stricter about the LTE attach APN. Set it explicitly before connecting:

```bash
sudo mmcli -m 0 --3gpp-set-initial-eps-bearer-settings="apn=iot.1nce.net"
```

**AT command access:** `--command` flag requires debug mode in ModemManager 1.24. Use tio on ttyUSB2 directly instead.

---

## GPS with exhausted or missing SIM

The EC25 GNSS receiver is independent of the cellular data stack. It communicates
directly with satellites and does not need a PDP context, a working SIM, or a data
session. NMEA sentences stream on `ttyUSB1` as long as GNSS is enabled via AT command.

**What breaks when the SIM is exhausted:**
- PDP context attachment is rejected by the network → `wwan0` never gets an IP
- `network-online.target` is never reached

**What does NOT break:**
- `ttyUSB1`, `ttyUSB2`, `ttyUSB3` — still accessible
- GNSS once enabled with `AT+QGPS=1`

### Old `gps.service` problem

The existing `config/gps.service` has:
```
Requires=network-online.target
After=network-online.target
```
This gates GPS initialisation on network connectivity, so GPS never starts when
the SIM is exhausted.

### Replacement: `quectel-gnss.service`

`config/quectel-gnss.service` + `config/quectel-gnss-enable` replace the old service.
The new service waits only for `dev-ttyUSB2.device` (the USB modem appearing) and
sends `AT+QGPS=1` directly to the AT port. The `77-mm-quectel-ignore-gps.rules` udev
rule already prevents ModemManager from claiming the ttyUSB ports, so the write
succeeds without stopping MM.

**Install on the Pi:**
```bash
sudo cp config/quectel-gnss-enable /usr/local/bin/
sudo chmod +x /usr/local/bin/quectel-gnss-enable
sudo cp config/quectel-gnss.service /etc/systemd/system/
sudo systemctl daemon-reload
sudo systemctl disable gps.service          # disable old service
sudo systemctl enable --now quectel-gnss.service
```

**Verify GNSS is running:**
```bash
# Should show flowing $GPGGA / $GPRMC lines within ~30 s of modem appearing
cat /dev/ttyUSB1
```

**`gpsd` must read from `ttyUSB1`** — set in `/etc/default/gpsd`:
```ini
DEVICES="/dev/ttyUSB1"
GPSD_OPTIONS="-n"
```

---

## Restore normal operation after debugging

```bash
sudo systemctl start ModemManager NetworkManager
```

NetworkManager will pick up the Quectel connection profile and attempt to connect automatically.

---

## Quick reference: connection profile setup

```bash
sudo nmcli connection add type gsm ifname cdc-wdm0 con-name Quectel apn iot.1nce.net
sudo nmcli con mod Quectel ipv4.route-metric 100
sudo nmcli con mod Quectel ipv6.route-metric 100
sudo nmcli con mod Quectel connection.autoconnect yes
```

Setting route metric to 100 ensures Ethernet and WiFi are preferred over cellular when available.

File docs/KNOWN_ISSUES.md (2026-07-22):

# Known Issues & Improvement Backlog

Findings from a codebase audit conducted 2026-04-19. Issues are grouped by severity.

---

## Architectural

### LoRa handler singleton doesn't account for TickTalk's multi-process runtime
**Files:** `tools/lora_handler_concurrent.py`, `tools/lora_runtime_integration.py`,
`tools/lora_daemon.py`
**Status: fixed (2026-07-22), not yet deployed to any field device.**
`get_lora_handler()`'s old singleton (`_lora_handler` + `threading.Lock`)
only worked within one OS process, but TickTalk's own runtime executes graph
nodes across multiple separate processes — confirmed via a live process-tree
capture on UFO010 (2026-07-22) showing a child process independently
conflicting with its own parent over the same serial port. A
retry-with-backoff mitigation shipped first (`7bfcce4`); the proper fix — a
single-owner daemon process (`tools/lora_daemon.py`) + IPC client
(`LoRaHandlerClient`), mirroring `tools/segformer_daemon.py` — has since
landed. **Requires installing `config/lora_daemon.service` on each device**
before it takes effect; until then, deployed devices keep using the old
retry mitigation. **Full writeup, evidence, and implementation details:**
`docs/LORA_HANDLER_MULTIPROCESS_ISSUE.md`

---

## Critical — System Failure

### Serial port opened at import, never closed
**File:** `tools/lora_handler.py:34`
Global `ser` is created at module load time and never closed. Blocks other processes from accessing the port; causes resource exhaustion on repeated imports.
**Fix:** Use a context manager or close in a shutdown handler.

### Serial port open failure is non-fatal
**File:** `tools/lora_handler.py:44`
If `ser.is_open` is false after init, code prints a warning and continues. Downstream `transmit()` calls then fail with confusing errors.
**Fix:** Raise an exception or return an error status instead of continuing.

### Listen loop reads serial without transmit lock
**File:** `tools/lora_handler_concurrent.py:168`
`_listen_loop()` reads from the serial port without acquiring `transmit_lock`. Concurrent read and write operations corrupt messages.
**Fix:** Acquire the same lock in `_listen_loop()` during serial reads.

### `gpsd.connect()` called at module import with no error handling
**File:** `tools/get_gps.py:8`
If the gpsd daemon is not running, importing this module raises an uncaught exception and crashes the caller.
**Fix:** Wrap in `try/except`, set an `_gps_available` flag, return empty data gracefully.

### Bare `except:` and call to undefined `killScript()`
**File:** `tools/lora_functions.py:93`
A bare `except:` swallows `SystemExit` and `KeyboardInterrupt`. The handler then calls `killScript()`, which is not defined, raising `NameError`.
**Fix:** Catch specific exceptions (e.g., `serial.SerialException`, `IndexError`). Define or import `killScript()`.

---

## High — Data Loss or Corruption

### No file lock on LoRa config read/write
**File:** `tools/lora_handler_concurrent.py:142–154`
`load_config()` and `save_config()` have no file-level lock. Two processes writing `lora_config.json` simultaneously will corrupt it.
**Fix:** Use `fcntl.flock()` around file open/write.

### Received LoRa payload parsed without bounds checking
**File:** `tools/lora_runtime_integration.py` (~line 350, `process_lora_command`)
Channel, command, and value fields are extracted from the payload without range validation. A malformed packet can set out-of-range thresholds or frequencies.
**Fix:** Validate parsed integers against expected ranges before applying them.

### `pickle.load()` on graph file without source validation
**Files:** `ticktalk_main.py`, `runrtm.py`
The TickTalkPython graph is loaded with `pickle.load()` from a file path. If that file is replaced by an attacker, it executes arbitrary code.
**Fix:** Validate the file's integrity (checksum or signature) before loading, or migrate to a safe serialization format.

---

## Medium — Incorrect Behavior

### GPS packet attributes accessed without mode check
**File:** `tools/add_metadata.py:152`
`packet.lat`, `packet.lon`, and `packet.alt` are accessed without checking `packet.mode`. A 2D fix (mode 2) has no altitude; mode < 2 has no position at all. Results in `AttributeError` or stale/zero coordinates written into image metadata.
**Fix:** Check `packet.mode >= 3` before accessing altitude; `>= 2` for lat/lon.

### `sq_state` dict access is not thread-safe
**File:** `tt_take_photos.py:141`
The `Picamera2()` instance is stored in a global `sq_state` dict without a lock. Two concurrent SQ nodes can both read `None` and both create camera instances simultaneously.
**Fix:** Guard the check-and-set with a `threading.Lock()`.

### IMU warmup timeout is silent
**File:** `tools/bno055_imu.py:33`
The warmup loop exits after 2 s even if Euler data never becomes valid. The caller cannot distinguish real zero-rotation from a timeout, and no warning is logged.
**Fix:** Log a warning on timeout; return a status flag or raise an exception.

### Parameter update callbacks can recurse infinitely
**File:** `tools/lora_runtime_integration.py:210`
`set_parameter()` invokes registered callbacks synchronously. A callback that calls `set_parameter()` again will recurse until the stack overflows.
**Fix:** Document that callbacks must not call `set_parameter()`; or dispatch callbacks via a queue/thread pool.

---

## Inconsistencies

### Temperature sensor returns formatted string; IMU returns raw float
**Files:** `tools/aht20_temperature.py:40`, `tools/bno055_imu.py:65`
`aht20_temperature.py` returns `'23.5 C'` (string); `bno055_imu.py` returns `23.5` (float). Callers must handle both formats.
**Fix:** Standardize all sensor functions to return raw numeric types; format at the display/log layer.

### `get_gps.py` returns `{}` in some paths and `None` in others
**File:** `tools/get_gps.py`
Different functions return inconsistent sentinel values for "no data available". Callers must check for both.
**Fix:** Standardize to always return an empty dict `{}` when data is unavailable.

### Hardcoded `/home/pi/SU-WaterCam/` paths in ~9 files
**Files:** Multiple (button service scripts, ticktalk_main.py, others)
Deployment to any user other than `pi`, or to a different path, silently breaks these files.
**Fix:** Use an environment variable (e.g., `WATERCAM_ROOT`) or derive the root from `__file__` at runtime.

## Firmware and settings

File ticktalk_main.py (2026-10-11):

import os

_REPO_ROOT = os.environ.get("WATERCAM_REPO", os.path.dirname(os.path.abspath(__file__)))

from tt_take_photos import flir, take_two_photos

# Import TickTalk decorators
from ticktalkpython.SQ import SQify, GRAPHify, STREAMify

# Import LoRa runtime integration
from tools.lora_runtime_integration import (
    get_runtime_manager, 
    get_parameter, 
    set_parameter, 
    register_callback,
    integrate_with_ticktalk
)

# Import LoRa handler
from tools.lora_handler_concurrent import get_lora_handler

# Import helper functions
from tools.wittypi_control import get_wittypi_status

@SQify
def wittypi_emergency_control(emergency_mode):
    """
    Control WittyPi schedule based on emergency mode status
    - Emergency ON: Clear shutdown schedule to prevent system shutdown
    - Emergency OFF: Regenerate and apply normal schedule

    Thin wrapper around tools.wittypi_control.apply_emergency_schedule() so
    the same logic is callable both as a graph node here and directly (via a
    plain local import) from contexts that cannot resolve a bare reference to
    this SQified function -- see lora_listener()'s on_emergency_mode_changed,
    which must call apply_emergency_schedule() directly for exactly this
    reason (a nested closure cannot resolve a sibling top-level @SQify
    function's name in TickTalk's isolated per-function exec runtime).
    """
    from tools.wittypi_control import apply_emergency_schedule
    return apply_emergency_schedule(emergency_mode)

@SQify
def create_sensor_tracker():
    """
    Create a sensor tracker to monitor value changes and only transmit when threshold is exceeded
    """
    try:
        # Initialize sensor tracker with previous values and change thresholds
        tracker = {
            'previous_values': {},
            'change_threshold': 0.05,  # 5% change threshold
            'transmission_history': {},
            'last_transmission': None
        }
        print("✅ Sensor tracker initialized with 5% change threshold")
        return tracker
    except Exception as e:
        print(f"⚠️ Failed to create sensor tracker: {e}")
        return None

@SQify
def check_sensor_changes(tracker, current_sensor_data):
    """
    Check if sensor values have changed by more than 5% from previous values
    Returns dict of sensors that need transmission
    """
    if not tracker or not current_sensor_data:
        return {}
    
    try:
        sensors_to_transmit = {}
        current_time = 'now'  # In real implementation, use datetime.now()
        
        for sensor_name, current_value in current_sensor_data.items():
            # Skip non-numeric values and special fields
            if not isinstance(current_value, (int, float)) or sensor_name in ['timestamp', 'error']:
                continue
            
            previous_value = tracker['previous_values'].get(sensor_name)
            
            if previous_value is None:
                # First time seeing this sensor - always transmit
                sensors_to_transmit[sensor_name] = {
                    'current_value': current_value,
                    'previous_value': None,
                    'change_percent': 100.0,
                    'reason': 'first_reading'
                }
                tracker['previous_values'][sensor_name] = current_value
            else:
                # Calculate percentage change
                if previous_value != 0:
                    change_percent = abs((current_value - previous_value) / previous_value)
                else:
                    change_percent = 100.0 if current_value != 0 else 0.0
                
                # Check if change exceeds 5% threshold
                if change_percent >= tracker['change_threshold']:
                    sensors_to_transmit[sensor_name] = {
                        'current_value': current_value,
                        'previous_value': previous_value,
                        'change_percent': change_percent * 100,
                        'reason': 'threshold_exceeded'
                    }
                    tracker['previous_values'][sensor_name] = current_value
                else:
                    # Update previous value even if not transmitting
                    tracker['previous_values'][sensor_name] = current_value
        
        # Log transmission decisions if any sensors qualify
        if sensors_to_transmit:
            print(f"📊 Sensors qualifying for transmission (5% threshold):")
            for sensor, details in sensors_to_transmit.items():
                print(f"   {sensor}: {details['previous_value']} → {details['current_value']} "
                      f"({details['change_percent']:.1f}% change)")
        else:
            print(f"📊 No sensors qualify for transmission (all changes < 5%)")
        
        return sensors_to_transmit
        
    except Exception as e:
        print(f"⚠️ Failed to check sensor changes: {e}")
        return {}

@SQify
def update_sensor_tracker(tracker, sensor_data, transmission_result):
    """
    Update sensor tracker with transmission results and maintain history
    """
    if not tracker:
        return
    
    try:
        current_time = 'now'  # In real implementation, use datetime.now()
        
        # Update transmission history
        tracker['last_transmission'] = current_time
        
        # Record which sensors were transmitted
        if transmission_result and 'transmitted_sensors' in transmission_result:
            for sensor_name in transmission_result['transmitted_sensors']:
                if sensor_name not in tracker['transmission_history']:
                    tracker['transmission_history'][sensor_name] = []
                
                tracker['transmission_history'][sensor_name].append({
                    'timestamp': current_time,
                    'value': sensor_data.get(sensor_name, 'unknown'),
                    'change_percent': transmission_result.get('change_percent', {}).get(sensor_name, 0)
                })
        
        print(f"✅ Sensor tracker updated with transmission results")
        
    except Exception as e:
        print(f"⚠️ Failed to update sensor tracker: {e}")
    
    return tracker

@SQify
def lora_token_with_tracker(bitmap, sensor_tracker, dirname):
    """
    Send this capture over LoRa: one sensor packet with the capture time and the
    fields that changed past the threshold since they were last sent, then the
    bitmap. If the mDot isn't joined, both are queued for store-and-forward.
    """

    from tools.lora_handler_concurrent import get_lora_handler, get_config_value
    from tools import lora_store_forward as _lsf

    from tools.bno055_imu import get_orientation
    from tools.aht20_temperature import get_aht20
    from tools.get_gps import get_location_with_retry
    from tools.lora_runtime_integration import get_parameter
    # Helper functions are now imported at module level

    # LoRa transmission is always enabled
    # The capture time is the capture's ID on every transport (tools/capture_time.py).
    from tools.capture_time import capture_time
    captured_at = capture_time(dirname)

    # Get sensor data
    try:
        data = get_orientation()
        data.update(get_aht20())
    except Exception as e:
        print(f"⚠️ Failed to get sensor data: {e}")
        data = {}
    
    # Always attempt to collect GPS data
    try:
        gps, packet = get_location_with_retry()
        if gps:
            data.update(gps)
    except Exception as e:
        print(f"⚠️ Failed to get GPS data: {e}")
    
    # Get WittyPi temperature and voltage diagnostics
    wittypi_data = None
    try:
        from tools.wittypi_control import get_wittypi_status
        wittypi_data = get_wittypi_status()
        if wittypi_data.get('status') == 'wittypi_data_retrieved':
            data.update({
                'wittypi_temperature': wittypi_data.get('temperature', 0.0),
                'wittypi_internal_voltage': wittypi_data.get('internal_voltage', 0.0)
            })
            print(f"WittyPi data: temp={wittypi_data.get('temperature', 0.0)}°C, internal={wittypi_data.get('internal_voltage', 0.0)}V")
        else:
            print(f"⚠️ WittyPi data unavailable: {wittypi_data.get('status', 'unknown')}")
    except Exception as e:
        print(f"⚠️ Failed to get WittyPi data: {e}")

    # Get battery state-of-charge from battery_manager (path varies by hardware)
    try:
        from tools.battery_manager import get_battery_status
        batt_status = get_battery_status(wittypi_data=wittypi_data)
        data['battery_percent'] = batt_status['battery_pct']
        data['battery_source'] = batt_status['battery_source']  # device-side diagnostic; not transmitted
        pct = batt_status['battery_pct']
        src = batt_status['battery_source']
        print(f"Battery: {pct}% ({src})" if pct is not None else f"Battery: unavailable ({src})")
    except Exception as e:
        print(f"⚠️ Failed to get battery status: {e}")
        data['battery_percent'] = None
        data['battery_source'] = 'unavailable'

    # Pi-side under-voltage/throttle flags -- the only supply reading taken on the
    # Pi side of the WittyPi and GPIO extension header (see tools/pi_power.py)
    from tools.pi_power import get_throttled
    data['pi_throttled'] = get_throttled()
    if data['pi_throttled'] is not None:
        print(f"Pi throttled: {data['pi_throttled']:#x}")
    else:
        print("⚠️ Pi throttled flags unavailable")

    # Add runtime parameters to sensor data
    emergency_mode = get_parameter('emergency_mode', False)
    area_threshold = get_parameter('area_threshold', 10)
    stage_threshold = get_parameter('stage_threshold', 50)
    
    data.update({
        'emergency_status': 1 if emergency_mode else 0,
        'status_area_threshold': area_threshold,
        'stage_threshold': stage_threshold,
        'monitoring_frequency': get_parameter('monitoring_frequency', 60),
        'emergency_frequency': get_parameter('emergency_frequency', 5),
        'neighborhood_emergency_frequency': get_parameter('neighborhood_emergency_frequency', 30),
        'audio_recording_enabled': 1 if get_parameter('audio_recording_enabled', True) else 0,
    })

    # Embed capture timestamp so stored packets carry original collection time
    if 'timestamp' not in data:
        data['timestamp'] = int(captured_at)

    # Check sensor changes using tracker if available (unless always_transmit_sensors is set)
    always_transmit_sensors = get_parameter('always_transmit_sensors', False)
    if always_transmit_sensors:
        print(f"📡 always_transmit_sensors=True: bypassing sensor change check")
    sensors_to_transmit = {}
    full_send = False
    if sensor_tracker and not always_transmit_sensors:
        try:
            # Compared with the values last sent, kept on disk: the tracker token
            # is a fresh copy every capture, and the Pi powers off between wakes.
            # Every lora_full_send_hours, all fields go out (LoRa is unconfirmed).
            from tools.sensor_changes import changed_fields, full_send_due
            full_send = full_send_due(get_parameter('lora_full_send_hours', 24))
            if full_send:
                print("📡 Periodic full send: all sensor fields this capture")
            sensors_to_transmit = changed_fields(
                data, threshold=sensor_tracker.get('change_threshold', 0.05), everything=full_send,
                angle_threshold_deg=get_parameter('lora_imu_threshold_deg', 2.0))
            print(f"📊 Sensor change check: {len(sensors_to_transmit)} sensors qualify for transmission")
        except Exception as e:
            print(f"⚠️ Failed to check sensor changes: {e}")
            sensors_to_transmit = {k: {'current_value': v, 'reason': 'tracker_failed'} for k, v in data.items()}

    try:
        handler = get_lora_handler()
    except Exception as e:
        print(f"⚠️ Failed to get LoRa handler: {e}")
        return bitmap

    if handler is None:
        # get_lora_handler() returns None when the LoRa daemon's socket is missing,
        # i.e. the daemon is not running; its contract requires callers to check
        # before dereferencing. Skip this cycle instead of crashing on handler.is_joined().
        from tools.lora_handler_concurrent import lora_unavailable_reason
        print(f"⚠️ LoRa unavailable ({lora_unavailable_reason()}) — skipping transmission this cycle")
        return bitmap

    # Store-and-forward: if the mDot is not joined, queue the payloads and skip
    # transmission.  The mDot will rejoin autonomously; the next cycle drains the
    # backlog (trickle: 2 packets/cycle) after sending the current data first.
    _sf_enabled = get_config_value('lora_sf_enabled', True)
    if _sf_enabled and not handler.is_joined():
        _sensor_hex = None
        _bitmap_hex = None
        try:
            # Always include 'timestamp' even when tracker filtering is active —
            # the sensor tracker explicitly excludes it from sensors_to_transmit,
            # but it must be in every stored packet so the gateway sees capture time.
            _sf_data = ({k: v for k, v in data.items()
                         if k in sensors_to_transmit or k == 'timestamp'}
                        if (sensor_tracker and sensors_to_transmit) else data)
            if always_transmit_sensors or not sensor_tracker or sensors_to_transmit:
                _sensor_hex = handler.compressed_encoding(_sf_data).hex()
        except Exception as _e:
            print(f"⚠️ S&F: sensor encode failed: {_e}")
        try:
            if bitmap:
                _bitmap_hex = handler.compressed_encoding({'flood_bitmap_compressed': bitmap}).hex()
        except Exception as _e:
            print(f"⚠️ S&F: bitmap encode failed: {_e}")
        if _lsf.enqueue(
            _sensor_hex, _bitmap_hex, captured_at,
            max_depth=get_config_value('lora_sf_max_depth', 96),
            max_age_days=get_config_value('lora_sf_max_age_days', 7),
        ) and _sensor_hex:
            from tools.sensor_changes import mark_sent
            mark_sent(_sf_data, full=full_send)
        print(f"📦 LoRa not joined — data queued (depth: {_lsf.queue_depth()})")
        return bitmap

    # Transmit sensor data if: no tracker, always_transmit_sensors, or changes detected
    transmission_result = {'transmitted_sensors': [], 'change_percent': {}}
    
    if always_transmit_sensors or not sensor_tracker or sensors_to_transmit:
        try:
            # Filter data to only include sensors that changed significantly
            if sensor_tracker and sensors_to_transmit:
                # The capture time goes in every sensor packet: it is the capture's ID.
                filtered_data = {k: v for k, v in data.items()
                                 if k in sensors_to_transmit or k == 'timestamp'}
                transmission_result['transmitted_sensors'] = list(sensors_to_transmit.keys())
                transmission_result['change_percent'] = {k: v.get('change_percent', 0) for k, v in sensors_to_transmit.items()}
                print(f"📡 Transmitting {len(filtered_data)} sensors with significant changes")
            else:
                filtered_data = data
                transmission_result['transmitted_sensors'] = list(data.keys())
                print(f"📡 Transmitting all sensor data (no tracker, always_transmit_sensors, or all sensors qualify)")
            
            handler.queue_transmit(filtered_data)
            handler.process_transmit_queue()
            from tools.sensor_changes import mark_sent
            mark_sent(filtered_data, full=full_send)
            
        except Exception as e:
            print(f"⚠️ Failed to transmit sensor data: {e}")
    else:
        print(f"📊 No sensor changes detected - skipping sensor data transmission")

    if not bitmap:
        print("[lora_token_with_tracker] No bitmap data to transmit")
    else:
        try:
            # TLV-wrap as channel 0x08 type 0x18 so ChirpStack codec can decode it.
            # compressed_encoding({'flood_bitmap_compressed': bitmap}) produces:
            #   08 18 [len 2B BE] [bitmap bytes]
            # No capture time, to keep every byte for the bitmap: it goes out right
            # after the sensor packet (which carries the capture time), and the
            # API pairs the two by LoRaWAN frame counter.
            handler.queue_transmit({'flood_bitmap_compressed': bitmap})
            print(f"[lora_token_with_tracker] Bitmap queued: {len(bitmap)}B → TLV 08 18")
            handler.process_transmit_queue()
        except Exception as e:
            print(f"⚠️ Failed to transmit bitmap: {e}")

    # Store-and-forward: trickle-drain backlog after current data is sent
    if _sf_enabled:
        try:
            _drain = _lsf.drain(
                handler,
                max_packets=get_config_value('lora_sf_drain_per_cycle', 2),
                max_age_days=get_config_value('lora_sf_max_age_days', 7),
            )
            if _drain['drained']:
                print(f"📤 S&F: drained {_drain['drained']} queued packet(s)")
            if _drain['failed']:
                print(f"⚠️ S&F: drain stopped early (transmission failure)")
        except Exception as _e:
            print(f"⚠️ S&F: drain error: {_e}")

    # Update sensor tracker with transmission results
    if sensor_tracker:
        try:
            # Call the function directly to avoid scope issues
            if not sensor_tracker:
                return bitmap
            
            current_time = 'now'  # In real implementation, use datetime.now()
            
            # Update transmission history
            sensor_tracker['last_transmission'] = current_time
            
            # Record which sensors were transmitted
            if transmission_result and 'transmitted_sensors' in transmission_result:
                for sensor_name in transmission_result['transmitted_sensors']:
                    if sensor_name not in sensor_tracker['transmission_history']:
                        sensor_tracker['transmission_history'][sensor_name] = []
                    
                    sensor_tracker['transmission_history'][sensor_name].append({
                        'timestamp': current_time,
                        'value': data.get(sensor_name, 'unknown'),
                        'change_percent': transmission_result.get('change_percent', {}).get(sensor_name, 0)
                    })
            
            print(f"✅ Sensor tracker updated with transmission results")
            
        except Exception as e:
            print(f"⚠️ Failed to update sensor tracker: {e}")
    
    return bitmap

@SQify
def create_workflow_data(monitoring_params, dirname, photo, lepton_file, coreg_state, seg_result, bitmap, lora_return, shutdown_result):
    """
    Create a structured workflow data object to reduce parameter complexity
    """
    from datetime import datetime
    try:
        return {
            'monitoring_params': monitoring_params,
            'dirname': dirname,
            'photo': photo,
            'lepton_file': lepton_file,
            'coreg_state': coreg_state,
            'seg_result': seg_result,
            'bitmap': bitmap,
            'lora_return': lora_return,
            'shutdown_result': shutdown_result,
            'timestamp': datetime.now().isoformat()
        }
    except Exception as e:
        print(f"⚠️ Failed to create workflow data: {e}")
        return {'error': str(e)}

# get_wittypi_status moved to tools/wittypi_control.py

@SQify
def get_wittypi_schedule_config():
    """
    Get WittyPi schedule configuration from runtime parameters
    """
    try:
        from tools.lora_runtime_integration import get_parameter
        
        # Get schedule parameters with sensible defaults
        start_hour = get_parameter('wittypi_start_hour', 8)
        start_minute = get_parameter('wittypi_start_minute', 0)
        interval_length_minutes = get_parameter('wittypi_interval_minutes', 30)
        num_repetitions_per_day = get_parameter('wittypi_repetitions_per_day', 8)
        
        return {
            'start_hour': start_hour,
            'start_minute': start_minute,
            'interval_length_minutes': interval_length_minutes,
            'num_repetitions_per_day': num_repetitions_per_day
        }
        
    except Exception as e:
        # Return default values if runtime parameters fail
        return {
            'start_hour': 8,
            'start_minute': 0,
            'interval_length_minutes': 30,
            'num_repetitions_per_day': 8
        }
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

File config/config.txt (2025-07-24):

# Interfaces needed for peripherals
dtparam=i2c_arm=on
dtparam=i2s=off
dtparam=spi=on
#dtparam=i2c1=on

# Disable audio
dtparam=audio=off

# Specify camera sensor to speed up boot
camera_auto_detect=0
dtoverlay=ov5647

# Disable display detection to speed up boot
# Comment out if you want a display for debugging
display_auto_detect=0

# This does not apply if using VC4 KMS. Specify minimum RAM for GPU - camera needs 32 MB
#gpu_mem=32

# Disable splash screen and boot option selection delay
disable_splash=1
boot_delay=0

# Enable DRM VC4 V3D driver - Note HDMI is disabled for power savings
# Remove 'nohdmi' option if you need HDMI output for debugging
# set max_framebuffers to number of displays
dtoverlay=vc4-kms-v3d,cma-320,nohdmi
max_framebuffers=0

# Run in 64-bit mode
arm_64bit=1

# Run as fast as firmware / board allows
arm_boost=1

# serial terminal access
enable_uart=1

# Disable wireless
# Comment out if you need wireless during debugging
#dtoverlay=disable-wifi
dtoverlay=disable-bt
#dtoverlay=pi3-disable-wifi
dtoverlay=pi3-disable-bt

# Disable LEDs to save power
dtparam=act_led_trigger=none
dtparam=act_led_activelow=off
dtparam=pwr_led_trigger=none
dtparam=pwr_led_activelow=on # try off
dtparam=eth_led0=4 # 14 on Pi3?
dtparam=eth_led1=4

# enable alt UARTs to connect to mDot without interfering with WittyPi
dtoverlay=uart5
dtoverlay=pi3-miniuart-bt
dtoverlay=miniuart-bt

# run at max clock rate during boot, int is duration in seconds 
initial_turbo=30
# set max clock to 2GHz
arm_freq=2000

# I2C clock stretching for BNO055 IMU
# https://learn.adafruit.com/circuitpython-on-raspberrypi-linux/i2c-clock-stretching
# 400,000 stock. 10,000 if there are issues with BNO IMU
dtparam=i2c_arm_baudrate=400000

# for Lepton - test impact
spidev.bufsiz=131072

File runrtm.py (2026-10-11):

# Copyright 2022 Carnegie Mellon University
#
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
import argparse
import hashlib
import os
import pickle
import time
#import timedinput
import logging

from typing import Dict, Any, TYPE_CHECKING

from ticktalkpython import DebugLogger
from ticktalkpython import RuntimeManager
from ticktalkpython import Graph
from ticktalkpython.IPC import *
from ticktalkpython.Constants import get_readable_time

from output_functions import get_applied_output_func


def _sha256_file(path: str) -> str:
    """Return the hex SHA-256 digest of a file."""
    h = hashlib.sha256()
    with open(path, 'rb') as f:
        for chunk in iter(lambda: f.read(65536), b""):
            h.update(chunk)
    return h.hexdigest()


def write_graph_checksum(filename: str) -> None:
    """Write a SHA-256 sidecar for filename (call this after building the .pkl)."""
    sidecar = filename + ".sha256"
    digest = _sha256_file(filename)
    with open(sidecar, 'w') as f:
        f.write(digest + "\n")


def _verify_graph_checksum(filename: str) -> None:
    """Raise RuntimeError if the .pkl.sha256 sidecar is missing or does not match."""
    sidecar = filename + ".sha256"
    if not os.path.exists(sidecar):
        raise RuntimeError(
            f"Graph checksum sidecar not found: {sidecar}. "
            "Run write_graph_checksum() after building the .pkl file."
        )
    with open(sidecar, 'r') as f:
        expected = f.read().strip()
    actual = _sha256_file(filename)
    if actual != expected:
        raise RuntimeError(
            f"Graph file integrity check failed: {filename}\n"
            f"  expected {expected}\n"
            f"  got      {actual}"
        )


def unpack_graph(filename):
    _verify_graph_checksum(filename)
    with open(filename, 'rb') as inpickle:
        graph = pickle.load(inpickle)
    assert isinstance(graph, Graph.TTGraph)
    return graph


# TODO: input values should be modifiable by the user.
# What format should this be in? perhaps JSON? {input: val}
def send_input_tokens(graph: Graph.TTGraph,
                      logger,
                      runtime_manager: RuntimeManager.TTRuntimeManager,
                      inputs: Dict[str, Any] = None):
    if inputs is not None:
        graph_inputs = inputs
    else:
        graph_inputs = {}
        for input_var in graph.source_var_names():
            graph_inputs[input_var] = 0xdeadbeef

    execute_graph_message = Message(RuntimeMsg.ExecuteGraphOnInputs,
                                    (graph, graph_inputs),
                                    Recipient.ProcessRuntimeManager)

#    logger.info('Sending token inputs\n\n\n')

    runtime_manager.send_to_runtime(execute_graph_message)


def run_application_rtm(name,
                        pickled_graph_file_path,
                        ip,
                        port,
                        output_func,
                        log_file_name,
                        logger,
                        timeout,
                        subscription_time,
                        in_jupyter=False):

    try:
        #        with open(log_file_name, 'a') as logfile:
#            logfile.write(f'\nstart execution of phy ({name}) at '
#                          f'{get_readable_time(time.time())}\n')

        rtm = RuntimeManager.TTRuntimeManagerPhysical(ip, port, port + 1,
                                                      log_file_name,
                                                      output_func)

#        time.sleep(0.5)
        # timedinput doesn't play nice with jupyter notebooks, hack around it
        # It also doesn't work when running runrtm.py through a systemd unit file
        #if in_jupyter:
#        time.sleep(subscription_time)
        #else:
        #    timedinput.timedinput(
        #        f'wait for {subscription_time} secs for devices '
        #        'to connect... hit enter\n\n', subscription_time, ' ')

        # Reset iteration_count once per boot, so a fresh power-on begins at
        # cycle 0. A restart within the same boot (Restart=on-failure after a
        # crash, or after a shutdown that failed) keeps the count: resetting it
        # there made the unit run extra cycles, or loop, until the Witty Pi cut
        # power. To start over by hand within one boot, set iteration_count to 0.
        # All other parameters in runtime_config.json are permanent operator
        # config and are left as-is.
        # Boot is when brownouts hit, so this write must be power-cut-safe
        # (tools/config_io.py), and it takes the same lock as the daemons.
        try:
            import os as _os
            from tools import config_io as _config_io
            _cfg_path = _os.path.join(_os.path.dirname(_os.path.abspath(__file__)),
                                      "runtime_config.json")
            if _os.path.exists(_cfg_path) or _os.path.exists(_cfg_path + ".bak"):
                _config_io.reset_iteration_count_once_per_boot(_cfg_path)
        except Exception as _e:
            print(f"Warning: could not reset iteration_count: {_e}")

        graph = unpack_graph(pickled_graph_file_path)
        instantiate_graph_msg = Message(RuntimeMsg.InstantiateAndMapGraph,
                                        graph, Recipient.ProcessRuntimeManager)
        rtm.send_to_runtime(instantiate_graph_msg)

 #       time.sleep(2)
        # Start capturing as soon as the sensors are up (get_time fires on
        # arrival, TTStartOnArrival) rather than at the next minute boundary.
        try:
            from tools.wait_for_sensors import wait_for_sensors
            _ready = wait_for_sensors()
            if _ready["ready"]:
                print(f"Sensors ready after {_ready['waited_s']} s")
            else:
                print(f"Warning: not ready after {_ready['waited_s']} s: "
                      f"{', '.join(_ready['missing'])}; capturing anyway")
        except Exception as e:
            print(f"Warning: sensor wait failed: {e}")

        send_input_tokens(graph, logger, rtm)

        # photo_interval (seconds) in runtime_config.json drives the capture
        # loop's period while the graph runs.
        try:
            from tools.photo_interval_watcher import start_photo_interval_watcher
            start_photo_interval_watcher(
                rtm, graph,
                os.path.join(os.path.dirname(os.path.abspath(__file__)), "runtime_config.json"))
        except Exception as e:
            print(f"Warning: photo_interval watcher not started: {e}")

        if timeout <= 0:
            rtm.manager_ensemble.enter_steady_state()
        else:
            rtm.manager_ensemble.enter_steady_state(timeout)

    except KeyboardInterrupt:
        print('KB interrupt; exit physical test')
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

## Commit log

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2021-08-10 Fixed issue with MLX library not saving all data per frame to Pandas dataframe by saving frame to empty list of 768 length, then passing to Pandas
    [heatmaps.py]
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2026-04-07 Harden headless button capture pipeline and service wiring.
    This updates the Pi button capture workflow to be resilient under hardware and timing faults: it adds safe Picamera2/FLIR orchestration, serializes capture callbacks, adds bounded FLIR thread handling with stuck-state latching, unifies and hardens LED/buzzer user feedback for headless operation, and fixes edge-case return/error paths so successful NIR output is preserved when possible. It also points the systemd button unit at button_hold_camera.py and adds explicit boot ordering for more reliable startup behavior.
    Made-with: Cursor
    [button_hold_camera.py]
2026-04-07 Refine NIR pair status semantics and serialize capture feedback.
    This follow-up aligns runtime behavior with reviewer concerns by distinguishing partial NIR capture from full-pair success, updating the capture return contracts accordingly, and driving LED/buzzer outcome signaling from explicit full-pair status. It also keeps outcome signaling inside the capture lock path to avoid overlapping feedback across concurrent button callbacks, while preserving existing FLIR safety guards.
    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
    [button_hold_camera.py]
2026-04-08 Harden and speed up button_hold_camera Pi Zero capture pipeline
    Resolve SU-WaterCam root via realpath, walking up until capture/lepton exist,
    or parent of tools/ when the script lives under tools/. Optional WATERCAM_REPO
    override. IMAGES_ROOT under that root is created at import.
    NIR pair: one Picamera2 session (start, capture_file OFF/ON, stop) instead of
    two start_and_capture_file cycles for lower latency. Validate JPEG paths exist
    and are non-empty. Always call stop() in finally inside try/except (no reliance
    on a started flag).
    FLIR: run capture and lepton with cwd set to the session directory; discard
    child stdout/stderr to avoid pipe deadlocks and RAM use on Pi Zero; check
    return cod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
    [button_hold_camera.py]
2026-04-15 button_hold_camera: embed GPS/IMU metadata with clear success log
    Call tools/add_metadata after each NIR JPEG when available; fix import
    path for sibling bno055_imu; log "Sensor metadata written" on success.
    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
    [button_hold_camera.py]
2026-04-15 button_hold_camera: harden metadata loading and preserve NIR pair timing
    Make lazy metadata loading robust across repo layouts by ensuring both repo root and tools paths are importable, and allow periodic retries after failed helper initialization. Defer metadata writes until after OFF/ON capture completes to keep paired frames temporally close.
    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
    [button_hold_camera.py]
2026-04-15 CellTransmit: add IP uplink/downlink transport layer
    Implements WiFi/cellular data upload to the WaterCam FastAPI server as a
    parallel transport path alongside LoRa. Verified end-to-end against the
    live server (11/11 integration tests passing).
    ## New files
    tools/transmit_ip.py
    - IPTransmitter class: send_uplink(), poll_downlink(), is_reachable()
    - Exponential-backoff retry (configurable); no retry on 4xx client errors
    - Module-level convenience wrappers; __main__ CLI smoke-test
    - Reads all settings from runtime_config.json ip_upload block
    - Plain Python — no TickTalkPython syntax (safe to test standalone)
    tests/test_ip_upload.py
    - 11 integration tests covering uplink varia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
    [ticktalk_main.py]
2026-04-15 button_hold_camera: address Copilot review concerns on metadata integration
    - Rename _metadata_writer_initialized → _metadata_writer_attempted: the flag
    tracks "we tried" not "we succeeded"; old name was misleading.
    - Fix sys.path safety: remove tools_dir insertion (index 0 could shadow stdlib);
    use sys.path.append for repo_root instead of insert(0); drop the plain
    "add_metadata" fallback import that required tools_dir on the path.
    - Move metadata writes out of take_nir_pair() and into single_press() after the
    capture lock is released. GPS get_location_with_retry() can sleep ~3 s; holding
    _capture_lock during that window blocked subsequent button presses.
    take_nir_pair() now re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
    [button_hold_camera.py]
2026-04-15 button_hold_camera: load metadata helper via spec_from_file_location
    Replace importlib.import_module("tools.add_metadata") with
    spec_from_file_location so the correct add_metadata.py is always loaded
    by explicit file path, regardless of any other package named `tools` that
    may appear earlier on sys.path.
    sys.path.append(repo_root) is still needed for add_metadata.py's own
    transitive imports (from tools import bno055_imu,
    from tools.get_gps import ...), but is not used to locate add_metadata.py
    itself.
    Also add `import importlib.util` which is required for spec_from_file_location
    (not automatically available via plain `import importlib`).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
    [button_hold_camera.py]
2026-04-15 button_hold_camera: thread-safe metadata init and transient sys.path
    Three issues from Copilot review:
    1. Remove unused `import importlib` — only `importlib.util` is referenced
    after switching to spec_from_file_location; the plain import is dead.
    2. Add _metadata_writer_lock (threading.Lock) around the lazy-init block in
    _get_metadata_writer(). Since metadata writes now run outside _capture_lock,
    concurrent button presses can call _get_metadata_writer() simultaneously and
    race on _metadata_writer_attempted, the backoff timestamp, and exec_module.
    The fast-path check (_metadata_writer is not None) remains lock-free; the
    slow path uses double-checked locking to avoid unne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
    [button_hold_camera.py]
2026-04-15 button_hold_camera: pre-empt next Copilot review round
    - Fix makedirs TOCTOU in photos(): replace the if-not-exists guard with
    makedirs(exist_ok=True). The check-then-create window was harmless in
    practice but a real race in principle.
    - Remove dead outer try/except in _get_metadata_writer(): the outer
    except could never fire — the inner try/except already catches every
    exception from the import path, and the only code outside it
    (last_error assignment + the None-check print) cannot raise.
    - Simplify sys.path restore: replace the _inserted/_orig_idx two-branch
    logic (which already needed a type: ignore[possibly-undefined]) with
    a snapshot-and-restore pattern: save sys.path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
    [button_hold_camera.py]
2026-04-15 button_hold_camera: serialize metadata writes, fix button type annotation
    - Add _metadata_write_lock (threading.Lock) around add_metadata() calls
    in _maybe_add_sensor_metadata(). gpiozero runs button handlers in worker
    threads, so rapid back-to-back presses can reach this function concurrently.
    add_metadata() accesses GPS/IMU hardware (I2C/serial) and is not thread-safe;
    interleaved calls could corrupt readings or log output.
    - Annotate single_press() parameter as button: Button. The pin parameter
    in take_nir_pair() was already typed as LED; this closes the same gap
    for the top-level handler.
    [button_hold_camera.py]
2026-04-15 CellTransmit: address Copilot review on PR #26 (IP transport)
    runtime_config.example.json:
    - Add always_transmit_sensors=false (ticktalk_main reads this via
    get_parameter() but it was missing from the example config)
    - Remove downlink_poll_interval_s: the field was read into the class but
    never enforced — polling is unconditional once per wake cycle; the setting
    was misleading
    tools/transmit_ip.py:
    - Fix module docstring: correct send_uplink/poll_downlink return-value
    examples (both return result wrapper dicts, not raw command objects)
    - _load_ip_config(): catch FileNotFoundError and json.JSONDecodeError and
    return {} so fresh dev/CI environments without runtime_config.json work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
    [ticktalk_main.py]
2026-04-15 CellTransmit: pre-empt next Copilot review on IP transport
    - _load_ip_config: catch OSError instead of FileNotFoundError; OSError
    also covers PermissionError and other I/O failures that would otherwise
    propagate and crash any IPTransmitter construction
    - Add _coerce_int()/_coerce_float() helpers; use them in __init__ for
    timeout_s, retry_attempts, retry_backoff_s — invalid config values
    (e.g. "timeout_s": "abc") previously raised ValueError/TypeError and
    crashed the constructor; now fall back to defaults with no exception
    - Add close() method that closes the underlying requests.Session
    - Module-level send_uplink()/poll_downlink() wrappers now call tx.close()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
    [ticktalk_main.py]
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2026-04-15 CellTransmit: address third Copilot review on PR #26
    - transmit_ip: clamp timeout_s and retry_attempts to at least 1 so a
    zero/negative config value never silently skips all POST attempts
    - transmit_ip poll_downlink: treat HTTP 404 as success=True + command=None
    (device not registered is a valid "no pending commands" state, not a
    transport failure); callers already handle command=None uniformly
    - ticktalk_main ip_downlink_poll_and_apply: add is_reachable(timeout_s=2)
    before polling to avoid blocking the wake cycle for up to timeout_s
    when the server is down (mirrors the reachability guard in ip_uplink_transmit)
    [ticktalk_main.py]
2026-04-15 CellTransmit: address fourth Copilot review on PR #26
    - tests: update test_01_poll_returns_valid_structure to accept status_code
    in (200, 404) — a consequence of our poll_downlink 404-as-success change
    - ticktalk_main ip_uplink_transmit: wrap data-collection, channel-encoding,
    and send_uplink in try/except/finally so the session is always closed and
    any unexpected exception returns a failure dict rather than propagating
    (preserves the "never raises" docstring promise)
    - ticktalk_main ip_uplink_transmit: clamp the five 09 xx status-report
    values with max(0, min(0xFFFFFFFF, int(v))) before struct.pack so an
    out-of-range config value cannot raise struct.error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
    [ticktalk_main.py]
2026-04-15 CellTransmit: address fifth Copilot review on PR #26
    - ticktalk_main ip_uplink_transmit: correct docstring and ttmain comment —
    IP uplink runs sequentially after lora_token_with_tracker, not in parallel
    - ticktalk_main ip_downlink_poll_and_apply: validate each command part is a
    dict with string code/payload_hex before processing; add TypeError to the
    fromhex except clause so a null payload_hex from the server doesn't crash
    the whole downlink apply step
    - tests: close cls.tx before raising SkipTest in both setUpClass methods —
    tearDownClass does not run when setUpClass raises, so the session would
    otherwise leak on every unreachable-server skip
    - docs/IP_TRANSMISSION.md + tran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
    [ticktalk_main.py]
2026-04-15 CellTransmit: address sixth Copilot review on PR #26
    - ip_uplink_transmit: clamp humidity to 0-100 (not 0-255) and use round()
    instead of int() truncation — server expects humidity_pct as a percentage
    - ip_downlink_poll_and_apply: validate parts field is a list before iterating;
    a non-list truthy value (dict, string) would otherwise be iterated silently
    - ip_downlink_poll_and_apply: add expected-payload-length check per command
    code before int.from_bytes() decoding so a short or long payload is
    skipped with a warning rather than silently misinterpreted
    (10 90: 1B, 11 91: 2B, 12 92/13 93/14 94: 1B each)
    - rename sensor_tracker → _sensor_tracker and lora_init → _lora_init in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
    [ticktalk_main.py]
2026-04-15 tools/bno055_imu.py — Added sensor = _get_sensor() at the top of main(). Without it, the loop body would immediately throw a NameError since the old module-level sensor global no longer exists.
    tt_take_photos.py — Two changes in flir() and take_two_photos():
    - flir() no longer calls hardcoded /home/pi/SU-WaterCam/capture and
    /home/pi/SU-WaterCam/lepton. It now resolves the project root dynamically via
    inspect.getfile(flir), finds the binaries relative to that, and falls back
    gracefully if the target directory is under /home/pi and not available.
    - take_two_photos() guards the picamera2 import so a missing camera module
    returns True (soft skip) instead of crashing, and removes the hardcod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
    [tt_take_photos.py]
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2026-04-16 issue #20: remove dispatch duplication from ticktalk_main.py
    ip_downlink_poll_and_apply() now delegates to apply_downlink_command()
    instead of reimplementing the same loop inline.
    [ticktalk_main.py]
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2026-04-16 Lock AWB/AEC before NIR pair captures to preserve spectral difference
    Without locked camera controls, auto-white-balance and auto-exposure adapt
    between the NIR-OFF and NIR-ON captures, equalising the spectral difference
    introduced by the IR-CUT filter and producing two photos that look identical.
    The fix mirrors the approach validated in test_ircut_filter.py:
    1. Start camera with pin LOW (IR filter IN), wait NIR_FILTER_SETTLE_S +
    NIR_AWB_WARMUP_S (2.5 s total) for AWB/AEC to converge on the scene.
    2. Snapshot current ColourGains, ExposureTime, AnalogueGain via
    capture_metadata() and freeze them with set_controls().
    3. Capture NIR-OFF frame with locked controls.
    4. Drive pin HIGH (fil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
    [button_hold_camera.py]
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2026-04-19 issue #20: address Copilot review comments on PR #27
    - Consolidate apply_downlink_command import with IPTransmitter at top of function
    - Type set_param_fn as Callable[[str, Any], None] | None; remove type: ignore
    - Normalize skipped sentinel to "<malformed_part>" for non-dict parts
    - Update docstring to reflect actual skipped entry contents
    [ticktalk_main.py]
2026-04-19 issue #20: address third round of Copilot review comments on PR #27
    - Guard lora_runtime_integration lazy import with RuntimeError so standalone
    callers get a clear message instead of heavy import-time side effects
    - Surface dispatch["skipped"] in log output and return dict
    - Return status "no_match" instead of "applied" when no params were applied
    [ticktalk_main.py]
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2026-04-19 fix: graceful degradation for missing/faulty AHT20, BNO055, and Lepton hardware
    - aht20_temperature.py: replace module-level SENSOR init with lazy _get_sensor()
    so a missing AHT20 (I2C addr 0x38) no longer raises ValueError on import and
    crashes the TTPython process; get_aht20() returns {} when unavailable
    - add_metadata.py: guard BNO055 imu_values dict access with .get() and an
    emptiness check so a missing BNO055 no longer raises KeyError ('Accelerometer')
    and propagates as "Metadata write failed"
    - tt_take_photos.py: resolve project root and binary paths before chdir() so the
    Path.cwd() fallback in _safe_project_root() still points to the project root;
    previously the Lepton cap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
    [tt_take_photos.py]
2026-04-19 fix: replace unreliable inspect.getfile with upward binary search for project root
    The previous _safe_project_root() used inspect.getfile(flir), but @SQify uses
    @wraps which copies metadata without replacing __code__, so getfile returned the
    SQ.py wrapper path (ticktalkpython/) instead of tt_take_photos.py. This caused
    capture_bin and lepton_bin to resolve to nonexistent paths -> silent failure.
    Replace with _find_project_root() which walks upward from the images directory
    argument looking for the capture binary. This is independent of Python module
    introspection and works correctly inside TTPython's compiled execution context.
    Also remove inspect/sys/Path imports from flir() that are no lo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
    [tt_take_photos.py]
2026-04-19 fix: port robust flir() implementation from button_hold_camera.py
    - Replace chdir() with cwd= in subprocess.run — chdir() is process-wide
    and would affect other concurrently-running TTPython SQ nodes
    - Increase timeout from 5s to 20s to match button_hold_camera.py
    - Add stdout/stderr=DEVNULL to prevent pipe-buffer deadlock on chatty output
    - Add _reset_lepton() on timeout, non-zero exit, and missing output files
    - Validate .pgm and lepton_temp_*.csv actually appeared after each binary runs
    - Use glob rename (IMG_*.pgm) instead of hardcoded IMG_0000.pgm
    - makedirs(directory) replaces the complex fallback/chdir error-handling block
    that is no longer needed without chdir()
    Co-Authored-By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
    [tt_take_photos.py]
2026-04-19 fix: address Copilot review comments on flir() validation
    - Use sys.executable to invoke lepton_reset.py instead of relying on
    execute bit and shebang; guard with isfile() check before running
    - Snapshot directory before each binary runs and diff against after,
    so stale IMG_*.pgm / lepton_temp_*.csv from prior attempts cannot
    mask a failed current capture
    - Align capture validation pattern (IMG_*.pgm) with the rename glob
    - Fix "radiometery" typo → "radiometry" in log message
    - Remove unused listdir import
    [tt_take_photos.py]
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2026-04-19 fix: address second round of Copilot review comments on flir()
    - Wrap makedirs() in try/except with fallback to <project_root>/images/fallback
    so a permissions or read-only FS error doesn't abort the TT pipeline
    - Rename by mtime (max(..., key=getmtime)) instead of sorted()[0] so we
    always rename the file just produced, not a stale older IMG_*.pgm or
    lepton_temp_*.csv that predates the current run
    [tt_take_photos.py]
2026-04-19 fix: address third round of Copilot review comments on flir()
    - Validate output by mtime >= run start time instead of set-difference;
    handles overwrite case (e.g. fallback dir reuse) that after-before missed
    - Return True on double directory failure to match all other non-fatal
    failure paths in flir() — keeps pipeline alive consistently
    [tt_take_photos.py]
2026-04-19 fix: name mtime slop constant and document why it exists
    Replaces magic `- 1` with MTIME_SLOP_SEC and adds comment explaining
    the tolerance covers filesystem timestamp granularity and clock skew.
    [tt_take_photos.py]
2026-04-19 fix: return fresh paths from _run_flir_cmd to avoid re-glob in rename step
    _run_flir_cmd now returns the list of mtime-verified fresh files instead
    of True/False. The rename step consumes those paths directly, so it can
    never pick up a file from a concurrent run sharing the same fallback
    directory.
    Also corrects stale line reference in KNOWN_ISSUES.md: payload parsing
    in lora_runtime_integration.py is in process_lora_command (~line 350),
    not line 545 (sync_with_lora_config).
    [tt_take_photos.py]
2026-04-19 fix: unify _run_flir_cmd return type to always return list
    All failure paths now return [] instead of mixing False and [].
    Empty list = failure, non-empty list = fresh output paths.
    Callers already use truthiness check so behaviour is unchanged.
    [tt_take_photos.py]
2026-04-20 fix: replace broken LiPo SOC formula with INA260 coulomb-counting battery manager
    Voltaic V50 outputs regulated 5V USB; the old formula (V−3.0)/1.2×100
    applied to WittyPi get_input_voltage always returned ~100% regardless of
    charge level. Fixes issue #46.
    - Add tools/battery_manager.py: INA260 coulomb-counting path + file-based
    persistent state; returns battery_pct=None when hardware absent so callers
    omit the channel rather than transmit a wrong value
    - Add docs/BATTERY_ESTIMATION_PLAN.md: hardware analysis, solution design,
    implementation steps, and Adafruit INA260 BOM note
    - Wire both LoRa and IP uplink data-collection blocks in ticktalk_main.py
    to call battery_manager.get_bat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
    [ticktalk_main.py]
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2026-04-20 fix: address all Copilot PR review comments
    - ticktalk_main.py: exception handlers used data['battery_pct'] instead
    of data['battery_percent'], causing key mismatch with LoRa encoders
    - ticktalk_main.py: IP uplink block accessed batt_status['input_voltage_v']
    which does not exist in battery_manager return dict; key removed
    - ticktalk_main.py: get_data() 3-tuple unpack updated to 4-tuple to match
    new wittypi_control.get_data() signature; internal_current now included
    in the get_status action response
    - tools/initial_health_check.py: get_data() unpack updated to 4-tuple;
    wittypi_internal_current_a added to returned dict
    - tools/debug_status_command.py: get_data() unpack updated to 4-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
    [ticktalk_main.py]
2026-04-20 fix: address second round of Copilot review comments
    ticktalk_main.py:
    - Replace stale "INA260 coulomb counter" comments (×2) with accurate
    "battery_manager (source varies by hardware)" wording
    - Fix None% log: print "Battery: unavailable (source)" when pct is None
    - Add inline note that battery_source is device-side diagnostic only
    and is intentionally not encoded in LoRa/IP packets
    tools/wittypi_control.py:
    - Update get_wittypi_status() docstring to include internal_current
    tools/initial_health_check.py:
    - Replace min_battery_voltage_v=3.6 (LiPo cell threshold) with
    min_input_voltage_v=4.5: wittypi_battery_voltage_v is the regulated
    5V VIN from the Voltaic V50, not a cell voltag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
    [ticktalk_main.py]
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2026-04-20 fix: address fifth round of Copilot review comments
    - Pass pre-fetched wittypi_data to get_battery_status() in both LoRa
    blocks so battery_manager Path 3 reuses existing I2C reading instead
    of calling get_wittypi_status() a second time
    - Add wittypi_data parameter to get_battery_status() and
    _read_wittypi_output() for caller-supplied pre-fetched data
    - Fix plan doc "Fallback: no hardware" section to describe the actual
    3-path chain (ADS1115 → INA260 → WittyPi → unavailable)
    [ticktalk_main.py]
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2026-04-21 fix: address Copilot review comments on PR #48
    - segformer_daemon: cap request size at 8 KB, parse only up to first newline
    - segformer_daemon: verify existing socket path is S_ISSOCK before unlinking
    - ticktalk_main: verify socket is S_ISSOCK before connecting to daemon
    - segformer_daemon.service: add TimeoutStartSec=60 and bounded ExecStartPost retry loop
    - export_segformer_onnx: remove unused sys, Path, and Config imports
    - coreg_multiple: reformat save_metadata_summary dict across multiple lines
    [ticktalk_main.py]
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2026-04-21 fix: address third round of Copilot review comments on PR #48
    - segformer_daemon: fix umask value — Unix sockets use 0o777 base mode, so
    umask 0o117 gives 0o660 (was incorrectly 0o007 which gives 0o770)
    - segformer_daemon/ticktalk_main: use lstat() instead of stat() to avoid
    following symlinks planted by another user in world-writable directories
    - Move socket from /tmp to systemd RuntimeDirectory=/run/segformer/ —
    removes /tmp TOCTOU/symlink exposure; update path in daemon, ticktalk,
    and service file; add RuntimeDirectoryMode=0750
    - export_segformer_onnx: fix prerequisites docstring — remove unused
    onnxruntime-extensions, add actual deps (torch, transformers, rasterio,
    ope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
    [ticktalk_main.py]
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2026-04-21 fix: address eleventh round of Copilot review comments on PR #48
    - segformer_daemon/export_segformer_onnx: drop redundant .astype(np.float32)
    before passing to preprocess_bands() — avoids a full-frame copy since
    preprocess_bands() already coerces to float32 on entry
    - segformer_daemon: catch PermissionError from makedirs and log an actionable
    message suggesting --socket /tmp/... for non-root non-systemd runs
    - ticktalk_main: bytearray + extend() for daemon response accumulation,
    matching the same fix already applied to handle_connection()
    [ticktalk_main.py]
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
